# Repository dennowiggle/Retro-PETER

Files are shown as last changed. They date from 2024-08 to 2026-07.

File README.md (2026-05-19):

# Retro-PETER
A Retro computer project => FPGA peripheral board + 3.3V RCBUS slot + CPU board(s) making a custom system.

## Description
Retro-PETER is a family of boards based around the Lattice ECP5 FPGA to create a custom retro computer system.
* [PETER](Hardware/PETER "Peripheral ECP5 Technology and Entertainment Resource board.") base board with FPGA provides the peripheral features. It has on board SRAM memory but no CPU.
    - One 3.3V RCBUS connector provides a CPU slot.
    - One 3.3V RCBUS expansion connector allows connection of an RCBUS backplane for more card slots.
* [ANALYZER](Hardware/Analyzer "Logic Analyzer for RCBUS using PI PICO 2") is a 5V tolerant 72 channel logic analyzer for RCBUS.
* [BALD](Hardware/BALD "Bus Activity LED Display.") is an RCBUS LED card that flickers lights when there is activity. I found this useful for bringup of new CPU's either on an RCBUS CPU card or internal CPU cores.
* [BUTLER](Hardware/BUTLER "Backplane with Universal Translation Logic for Exploring Retro") is a backplane with voltage translation logic to support 2 x 3.3V connectors for 3.3V RCBUS cards and 3 x 5V connectors for 5V RCBUS cards.
* [GOLD](Hardware/GOLD "GPIO On LED Display.") is a simple LED board that connects to 6 GPIO outputs for flashing lights and debug info. I love a binary counter.
* [RANDY](Hardware/RANDY "RCBUS Adapter to Nouveau Design. Yeah!") is a bus adapter from RCBUS to John's Basement [2067-Z8S180](https://github.com/johnwinans/2067-Z8S180/) card.
* [SEWER](Hardware/SEWER "Simple Eval With EZ80F91 on RCBUS") is an eZ80 CPU card.
* [SPIFEE](Hardware/SPIFEE "Sixty-eight thousand Processor Including Flash Engineering Eval") is an RCBUS board with an M68SEC000FU20 CPU that runs in 8-bit mode.
* [ZORO](Hardware/ZORO "Z8S180 On RCBUS Only.") is a Z180 RCBUS CPU card.

**WARNING** : This is a 3.3V system and any connections to PETER, including RCBUS, must NOT exceed 3.3V.

**Disclaimer** This is a hobby project and a vehicle for play. Not intended to be a product or to be optimised for size, cost, function, or meet any standard. All boards are prototypes and should be considered such even if there are new revisions over time.

## Background
John Winans has a video series and boards for an ice40HX4K + Z180 CPU card aka Z80 Nouveau. There is also a companion CP/M video series and project files. This project grew from following along with those video's and projects. Here are some links to follow John's work :
* John's Basement [FPGA](https://www.youtube.com/playlist?list=PL3by7evD3F52On-ws9pcdQuEL-rYbNNFB) YouTube series.
    - Supporting  [2057-ice40HX4K](https://github.com/johnwinans/2057-ICE40HX4K-TQ144-breakout) board.
    - [Code](https://github.com/johnwinans/Verilog-Examples) for Series.
* John's Basement [Z80 Nouveau](https://www.youtube.com/playlist?list=PL3by7evD3F52rUbThUNDYGxNpKFF1HCNT) YouTube series.
    - Supporting [2067-Z8S180](https://github.com/johnwinans/2067-Z8S180/) board.
    - [Code](https://github.com/johnwinans/2067-Z8S180/tree/main/fpga) for Series.
* John's Basement [Z80 Retro](https://www.youtube.com/playlist?list=PL3by7evD3F51Cf9QnsAEdgSQ4cz7HQZX5) YouTube series covering CP/M.
    - [CP/M SW](https://github.com/Z80-Retro/2063-Z80-cpm) to go along with the video series and which supports 2057-ice40HX4K + 2067-Z8S180 aka Z80 Nouveau.
* Johns Z80 Retro! [Discord](https://discord.gg/jf73DRZvh5) channel.

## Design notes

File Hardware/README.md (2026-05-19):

# Retro-PETER Hardware Design Files
A Retro Computer project => FPGA peripheral board + 3.3V RCBUS slot + CPU board(s) making a custom system.

Hardware design files in KiCad 8 format are located here. 

Schematic design PDF drawings can be found in the `output` sub-directory of each board directory.

**Warning** : This is a 3.3V system and any connections to PETER, including RCBUS, must NOT exceed 3.3V.

**Disclaimer** : This is a hobby project and a vehicle for play. Not intended to be a product or to be optimised for size, cost, function, or meet any standard. All boards are prototypes and should be considered such even if there are new revisions over time.

## Description
Retro-PETER is a family of boards based around the Lattice ECP5 FPGA to create a custom retro computer system.
* [PETER](PETER "Peripheral ECP5 Technology and Entertainment Resource board.") base board with FPGA provides the peripheral features. It has on board SRAM memory but no CPU.
    - One 3.3V RCBUS connector provides a CPU slot.
    - One 3.3V RCBUS expansion connector allows connection of an RCBUS backplane for more card slots.
* [ANALYZER](Analyzer "Logic Analyzer for RCBUS using PI PICO 2") is a 5V tolerant 72 channel logic analyzer for RCBUS.
* [BALD](BALD "Bus Activity LED Display.") is an RCBUS LED card that flickers lights when there is activity. I found this useful for bringup of new CPU's either on an RCBUS CPU card or internal CPU cores.
* [BUTLER](BUTLER "Backplane with Universal Translation Logic for Exploring Retro") is a backplane with voltage translation logic to support 2 x 3.3V connectors for 3.3V RCBUS cards and 3 x 5V connectors for 5V RCBUS cards.
* [GOLD](GOLD "GPIO On LED Display.") is a simple LED board that connects to 6 GPIO outputs for flashing lights and debug info. I love a binary counter.
* [RANDY](RANDY "RCBUS Adapter to Nouveau Design. Yeah!") is a bus adapter from RCBUS to John's Basement [2067-Z8S180](https://github.com/johnwinans/2067-Z8S180/) card.
* [SEWER](SEWER "Simple Eval With EZ80F91 on RCBUS") is an eZ80 CPU card.
* [SPIFEE](SPIFEE "Sixty-eight thousand Processor Including Flash Engineering Eval") is an RCBUS board with an M68SEC000FU20 CPU that runs in 8-bit mode.
* [ZORO](ZORO "Z8S180 On RCBUS Only.") is a Z180 RCBUS CPU card.

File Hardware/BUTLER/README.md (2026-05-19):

# BUTLER
Backplane with Universal Translation Logic for Exploring Retro

## Description
BUTLER is an RCBUS backplane board with voltage translation logic. It has 2 connectors for 3.3V cards and 3 connectors for 5V cards.

The buffer direction control signal comes from the [PETER](../PETER) FPGA. The card uses three backplane signals for GND as well as GND planes to try and improve signal integrity.

## Top View
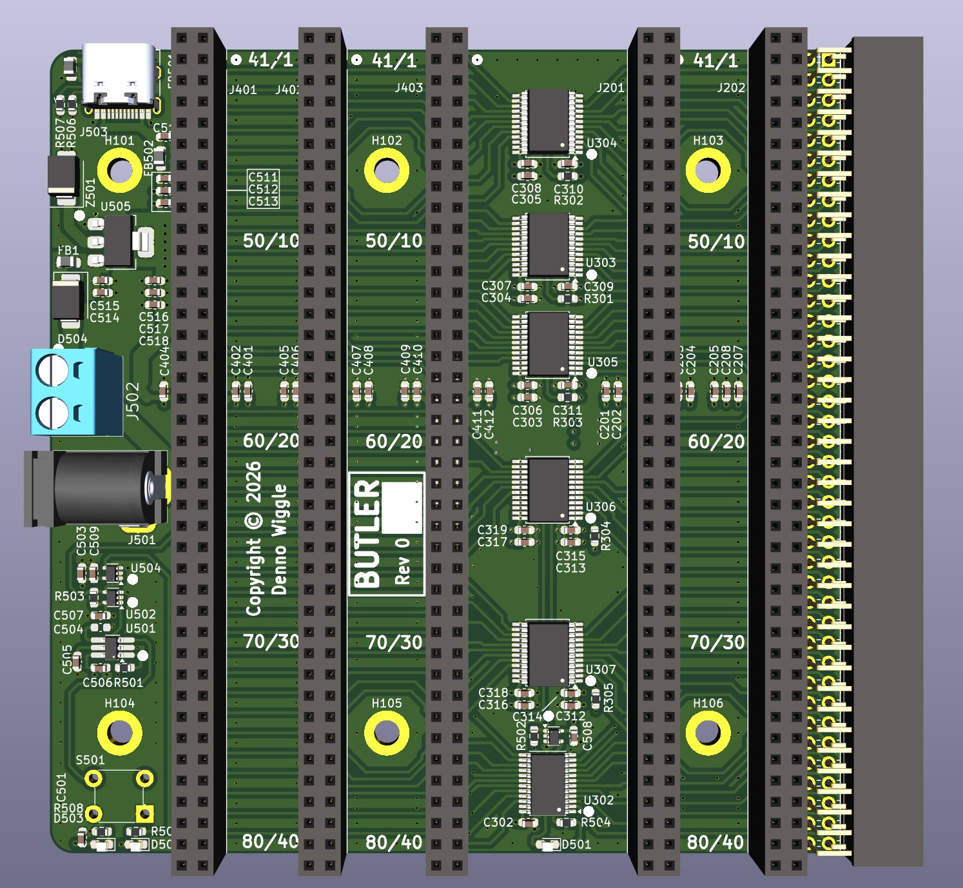
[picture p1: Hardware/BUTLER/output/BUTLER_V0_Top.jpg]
BUTLER Top View Board Image Top View of the BUTLER backplane board.


## Bottom View
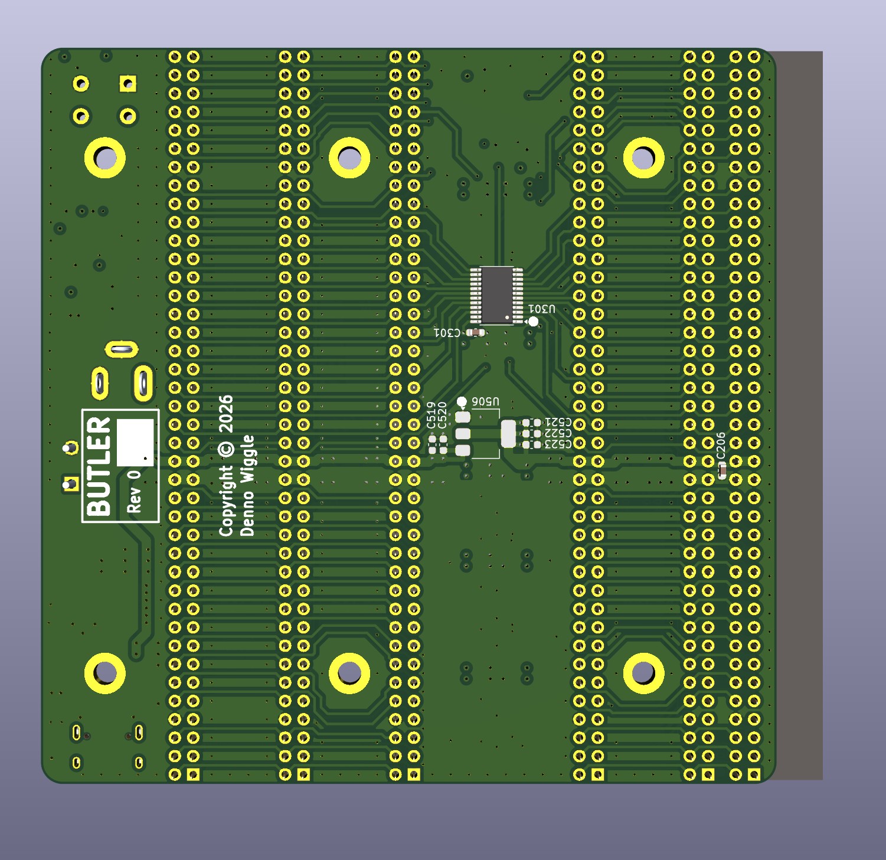
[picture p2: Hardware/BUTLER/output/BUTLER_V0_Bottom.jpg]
BUTLER Bottom View Board Image Bottom View of the BUTLER backplane board.


## BUTLER Board Rev 0.0 Release Notes
1. The [output](output/) directory contains the BOM, netlist, and PDF schematic.

2. Board design used KiCad 9.0

## BUTLER Future Changes.
1. Replace U505 5V LDO with TRACO POWER TSR 1-2450 or equivalent that has a wide input voltage operating range and is a switch mode power supply. This has been tested on the prototype as rework and worked well.

## Notes
Only preliminary testing has taken place.

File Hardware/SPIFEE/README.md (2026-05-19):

# SPIFEE
Sixty-eight thousand Processor Including Flash Engineering Eval

## Description
SPIFEE is an RCBUS board with an M68SEC000FU20 CPU that runs in 8-bit mode. There is no RAM or control signal decoding hosted on the board, that is taken care of on the main [PETER board](../PETER/).

The purpose of the card is to use it to learn 68000 programming.

## Top View
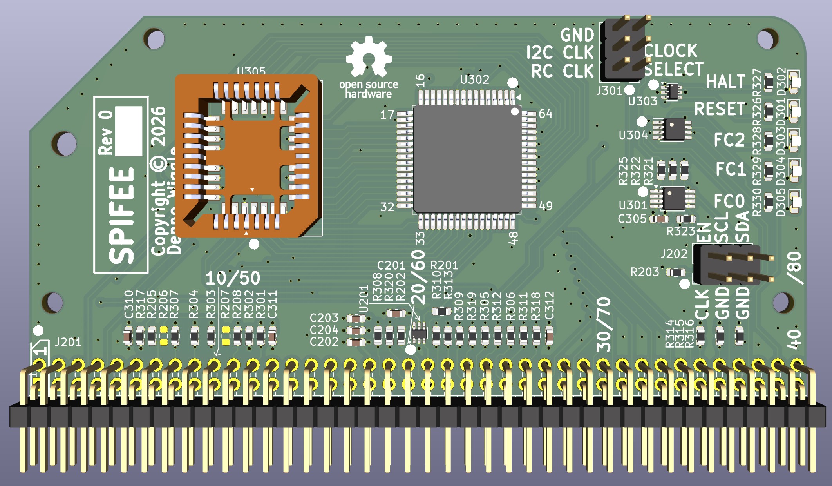
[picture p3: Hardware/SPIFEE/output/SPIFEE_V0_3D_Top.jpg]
SPIFEE Top View Board Image Top View of the SPIFEE M68000 board.


## Bottom View
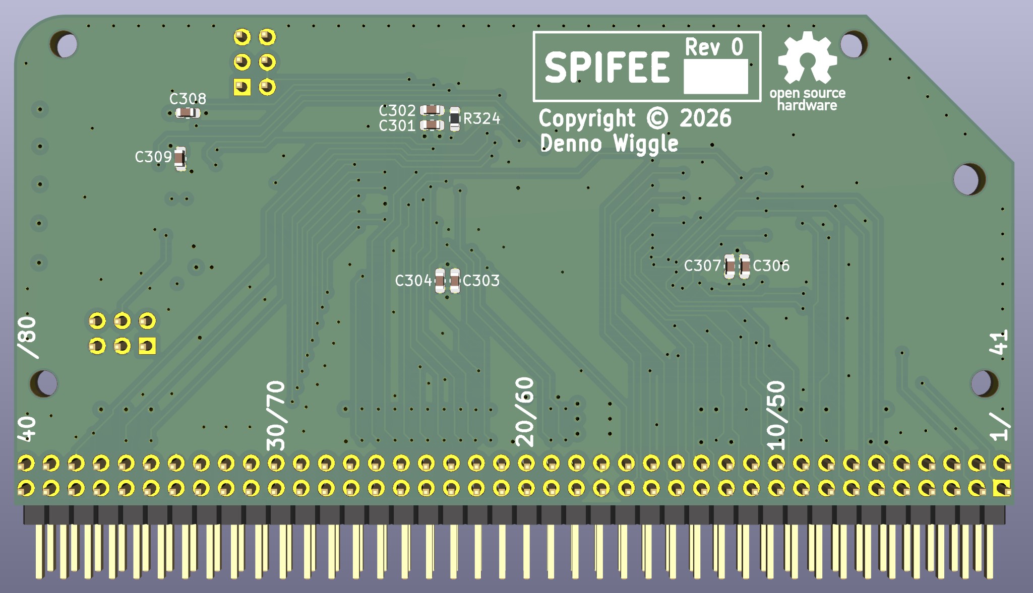
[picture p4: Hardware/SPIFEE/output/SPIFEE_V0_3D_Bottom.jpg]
SPIFEE Bottom View Board Image Bottom View of the SPIFEE M68000 board.


## SPIFEE Board Rev 0.0 Release Notes
1. The [output](output/) directory contains the BOM, netlist, and PDF schematic.

2. Board design used KiCad 10.0

3. Jumper CPU_RESET_N to CPU_HALT_N, RCBUS pin 20 to pin 63.
   * If signals need to be separate then jumper CPU_HALT_N to spare pin on PETER FPGA e.g. spare GPIO pin on PETER GPIO header.
   
4. If using a socket for the FLASH have the assembly house solder the socket, or use a hotplate and hot air.
   * If soldering the FLASH part directly it is possible to program a blank FLASH when soldered onto the board from a ROM image inside the FPGA to start. First need to develop the ROM image to do that.

## Notes
The FLASH has not been tested yet.

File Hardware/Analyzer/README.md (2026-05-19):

# ANALYZER
72 channel logic analyzer for RCBUS.

## Description
ANALYZER is a 72 channel logic analyzer in an RCBUS board form factor with 3 x Pi Pico modules. 

This design is a derivative work of John Winans [S-100 bus logic analyzer](https://github.com/johnwinans/2070-S-100-bus-analyzer) targeted for RCBUS instead of S-100 bus for use on the PETER project.

Both projects use the Dr Gusman [LogicAnalyzer software and firmware](https://github.com/gusmanb/logicanalyzer).

## Top View
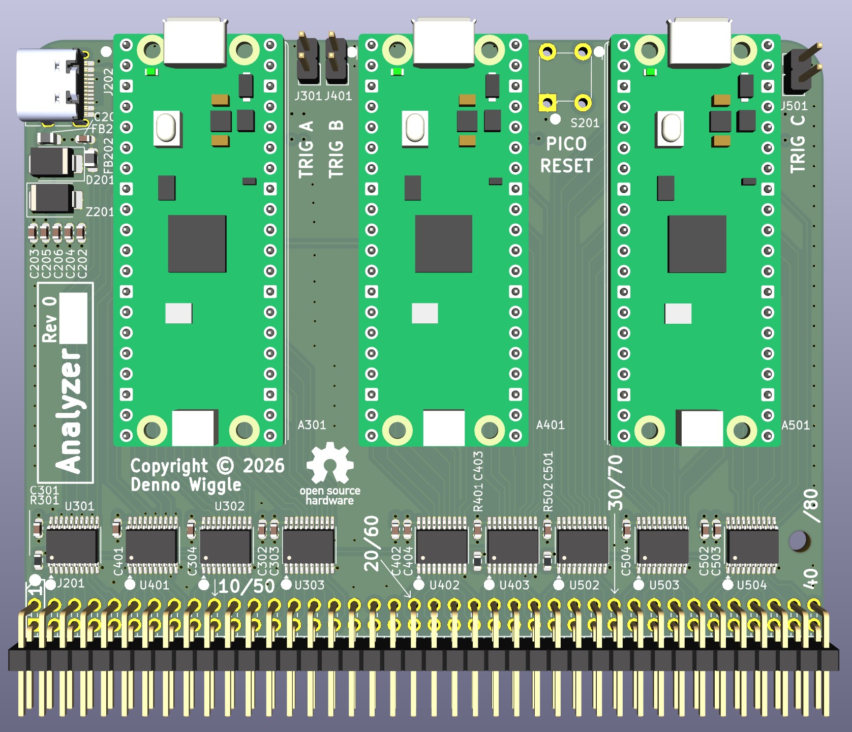
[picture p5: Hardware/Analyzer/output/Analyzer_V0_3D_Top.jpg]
ANALYZER Top View Board Image Top View of the RCBUS LogicAnalyzer board.


## Bottom View
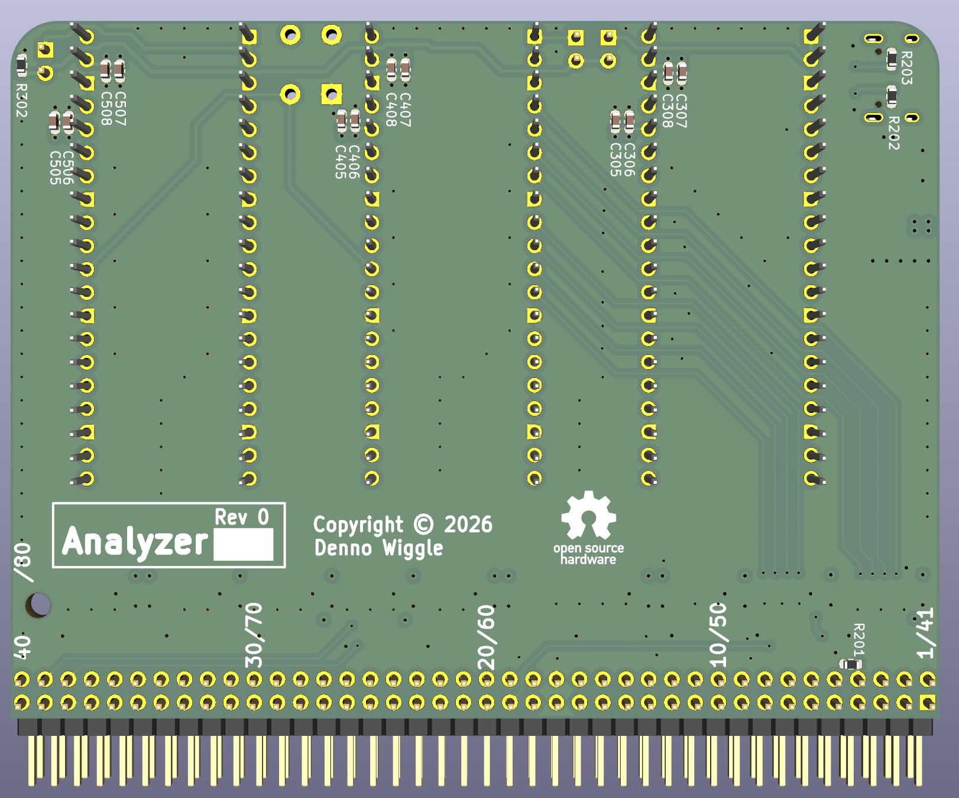
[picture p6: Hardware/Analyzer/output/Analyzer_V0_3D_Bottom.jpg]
ANALYZER Bottom View Board Image Bottom View of the RCBUS LogicAnalyzer board.


## ANALYZER Board Rev 0.0 Release Notes

1. The 'output' directory contains the BOM, netlist, and PDF schematic.

2. Board design used KiCad 10.0

3. Use sockets to mount the PICO's so that they are elevated above the board for anyone wanting to try WiFi.

## Notes for future
1. Consider using 3 x individual Pico 10K pull-down resistors for
  - TRIG_CHA, TRIG_CHB, TRIG_CHC instead of R302 2.2K on TRIG.

2. Consider replacing D201 with 3 schottky diodes to VSYS_A, VSYS_B, VSYS_B.
  - Provides option for manually sequencing power via each Pico USB connector.
  - Useful for getting same tty device name in Linux on each power on.

## Analyzer Board Pi Pico Channel Mapping to Signal and Pin Names
The [gusmanb software](https://github.com/gusmanb/logicanalyzer) only has the choice of 16 pins for trigger.

The table below has the middle PICO as the master. With the RCBUS backplane you can jumper the desired trigger signal to one of the unused pins. e.g. custom pin 41, analyzer channel 1.

 | Pico A       | Single A | Multi A | PETER Signal | RCBUS Pin | RCBUS Name  | 
 | ------------ | -------- | ------- | ------------ | --------- | ----------- |
 | GPIO_CHA_P2  | 1        | 25      | A15          | 1         | A15         | 
 | GPIO_CHA_P3  | 2        | 26      | A14          | 2         | A14         | 
 | GPIO_CHA_P4  | 3        | 27      | A13          | 3         | A13         | 
 | GPIO_CHA_P5  | 4        | 28      | DREQ0_N      | 45        | custom      | 
 | GPIO_CHA_P6  | 5        | 29      | A11          | 5         | A11         | 
 | GPIO_CHA_P7  | 6        | 30      | A10          | 6         | A10         | 
 | GPIO_CHA_P8  | 7        | 31      | A5           | 11        | A5          | 
 | GPIO_CHA_P9  | 8        | 32      | A21          | 51        | A21         | 
 | GPIO_CHA_P10 | 9        | 33      | A6           | 10        | A6          | 
 | GPIO_CHA_P11 | 10       | 34      | A22          | 50        | A22         | 
 | GPIO_CHA_P12 | 11       | 35      | A7           | 9         | A7          | 
 | GPIO_CHA_P13 | 12       | 36      | A23          | 49        | A23         | 
 | GPIO_CHA_P14 | 13       | 37      | A9           | 7         | A9          | 
 | GPIO_CHA_P15 | 14       | 38      | A8           | 8         | A8          | 
 | GPIO_CHA_P16 | 15       | 39      | A2           | 14        | A2          | 
 | GPIO_CHA_P17 | 16       | 40      | A17          | 55        | A17         | 
 | GPIO_CHA_P18 | 17       | 41      | A1           | 15        | A1          | 
 | GPIO_CHA_P19 | 18       | 42      | A16          | 56        | A16         | 
 | GPIO_CHA_P20 | 19       | 43      | A0           | 16        | A0          | 
 | GPIO_CHA_P21 | 20       | 44      | A18          | 54        | A18         | 
 | GPIO_CHA_P22 | 21       | 45      | A3           | 13        | A3          | 
 | GPIO_CHA_A0  | 22       | 46      | A19          | 53        | A19         | 
 | GPIO_CHA_A1  | 23       | 47      | A4           | 12        | A4          | 
 | GPIO_CHA_A2  | 24       | 48      | A20          | 52        | A20         | 
 
 | Pico B       | Single B | Multi B | PETER Signal | RCBUS Pin | RCBUS Name  | 
 | ------------ | -------- | ------- | ------------ | --------- | ----------- |
 | GPIO_CHB_P2  | 1        | 1       | MEM_OE_N     | 41        | custom      | 
 | GPIO_CHB_P3  | 2        | 2       | MEM_CE_N     | 42        | custom      | 
 | GPIO_CHB_P4  | 3        | 3       | MEM_WE_N     | 43        | custom      | 
 | GPIO_CHB_P5  | 4        | 4       | A12          | 4         | A12         | 
 | GPIO_CHB_P6  | 5        | 5       | TEND0_N      | 46        | custom      | 
 | GPIO_CHB_P7  | 6        | 6       | DREQ1_N      | 47        | custom      | 
 | GPIO_CHB_P8  | 7        | 7       | TEND1_N      | 48        | custom      | 
 | GPIO_CHB_P9  | 8        | 8       | M1_N         | 19        | /M1         | 
 | GPIO_CHB_P10 | 9        | 9       | BUSACK_N     | 62        | /BUSAK      | 
 | GPIO_CHB_P11 | 10       | 10      | INT0_N       | 22        | /INT        | 
 | GPIO_CHB_P12 | 11       | 11      | CLK_SRC      | 61        | CLK2        | 
 | GPIO_CHB_P13 | 12       | 12      | CLK_PHI      | 21        | CLK         | 
 | GPIO_CHB_P14 | 13       | 13      | PAGE         | 60        | PAGE_RESET2 | 
 | GPIO_CHB_P15 | 14       | 14      | RESET_N      | 20        | /RESET      | 
 | GPIO_CHB_P16 | 15       | 15      | WAIT_N       | 65        | /WAIT       | 
 | GPIO_CHB_P17 | 16       | 16      | RD_N         | 25        | /RD         | 
 | GPIO_CHB_P18 | 17       | 17      | BUSREQ_N     | 64        | /BUSRQ      | 
 | GPIO_CHB_P19 | 18       | 18      | WR_N         | 24        | /WR         | 
 | GPIO_CHB_P20 | 19       | 19      | HALT_N       | 63        | /HALT       | 
 | GPIO_CHB_P21 | 20       | 20      | MREQ_N       | 23        | /MREQ       | 
 | GPIO_CHB_P22 | 21       | 21      | IORQ_N       | 26        | /IORQ       | 
 | GPIO_CHB_A0  | 22       | 22      | NMI_N        | 66        | /NMI        | 
 | GPIO_CHB_A1  | 23       | 23      | I2C_SCL      | 78        | USER6       | 
 | GPIO_CHB_A2  | 24       | 24      | I2C_SDA      | 79        | USER7       | 
 
 | Pico C       | Single C | Multi C | PETER Signal | RCBUS Pin | RCBUS Name  | 
 | ------------ | -------- | ------- | ------------ | --------- | ----------- |
 | GPIO_CHC_P2  | 1        | 49      | D0           | 27        | D0          | 
 | GPIO_CHC_P3  | 2        | 50      | D8           | 67        | D8          | 
 | GPIO_CHC_P4  | 3        | 51      | D1           | 28        | D1          | 
 | GPIO_CHC_P5  | 4        | 52      | D9           | 68        | D9          | 
 | GPIO_CHC_P6  | 5        | 53      | D2           | 29        | D2          | 
 | GPIO_CHC_P7  | 6        | 54      | D10          | 69        | D10         | 
 | GPIO_CHC_P8  | 7        | 55      | D3           | 30        | D3          | 
 | GPIO_CHC_P9  | 8        | 56      | D11          | 70        | D11         | 
 | GPIO_CHC_P10 | 9        | 57      | D14          | 73        | D14         | 
 | GPIO_CHC_P11 | 10       | 58      | D6           | 33        | D6          | 
 | GPIO_CHC_P12 | 11       | 59      | D13          | 72        | D13         | 
 | GPIO_CHC_P13 | 12       | 60      | D5           | 32        | D5          | 
 | GPIO_CHC_P14 | 13       | 61      | D12          | 71        | D12         | 
 | GPIO_CHC_P15 | 14       | 62      | D4           | 31        | D4          | 
 | GPIO_CHC_P16 | 15       | 63      | UART1_RX     | 36        | RX          | 
 | GPIO_CHC_P17 | 16       | 64      | UART2_TX     | 75        | TX2         | 
 | GPIO_CHC_P18 | 17       | 65      | UART1_TX     | 35        | TX          | 
 | GPIO_CHC_P19 | 18       | 66      | D15          | 74        | D15         | 
 | GPIO_CHC_P20 | 19       | 67      | D7           | 34        | D7          | 
 | GPIO_CHC_P21 | 20       | 68      | UART2_RX     | 76        | RX2         | 
 | GPIO_CHC_P22 | 21       | 69      | DATA_DIR     | 37        | USER1       | 
 | GPIO_CHC_A0  | 22       | 70      | USER2        | 38        | USER2       | 
 | GPIO_CHC_A1  | 23       | 71      | USER3        | 39        | USER3       | 
 | GPIO_CHC_A2  | 24       | 72      | USER4        | 40        | USER4       | 

 | Unconnected  |          |         |              | RCBUS Pin | RCBUS Name  | 
 | ------------ | -------- | ------- | ------------ | --------- | ----------- |
 |              |          |         |              | 57        | GND         | 
 |              |          |         |              | 58        | 5V          | 
 |              |          |         |              | 59        | /RFSH       | 
 |              |          |         |              | 77        | USER5       | 
 |              |          |         |              | 80        | USER8_IEI   |

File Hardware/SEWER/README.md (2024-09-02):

# SEWER
Simple Eval With EZ80F91 on RCBUS

## Description
SEWER is an RCBUS board with an ez80F91 CPU. There is no RAM or ROM memory hosted on the board.

## Top View
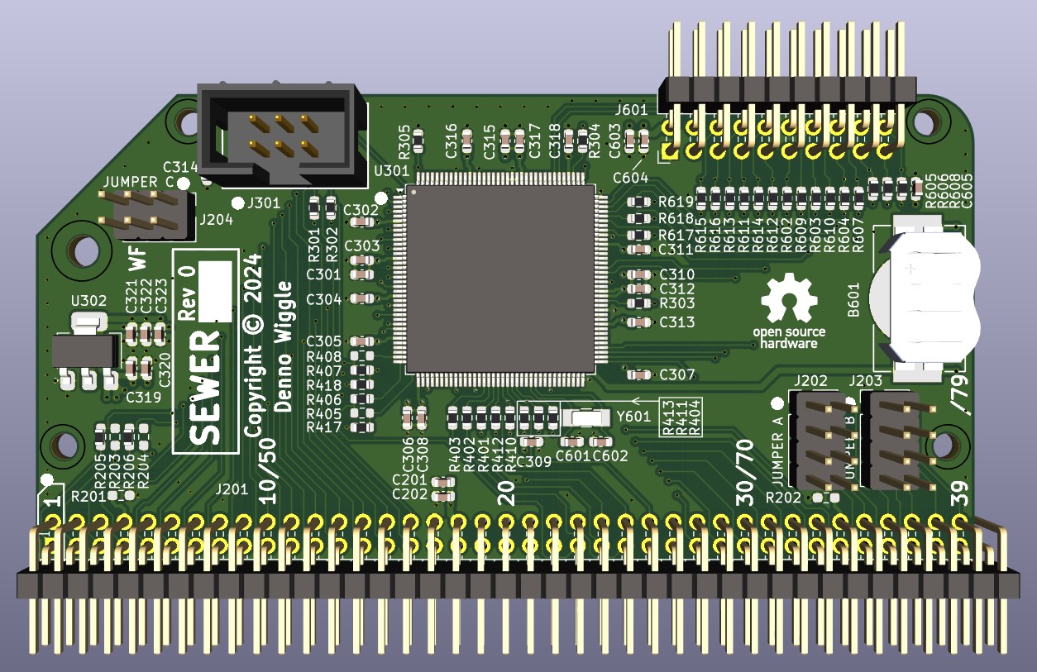
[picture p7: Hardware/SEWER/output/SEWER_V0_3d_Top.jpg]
SEWER Top View Board Image Top View of the Simple Eval With EZ80F91 on RCBUS board.


## Bottom View
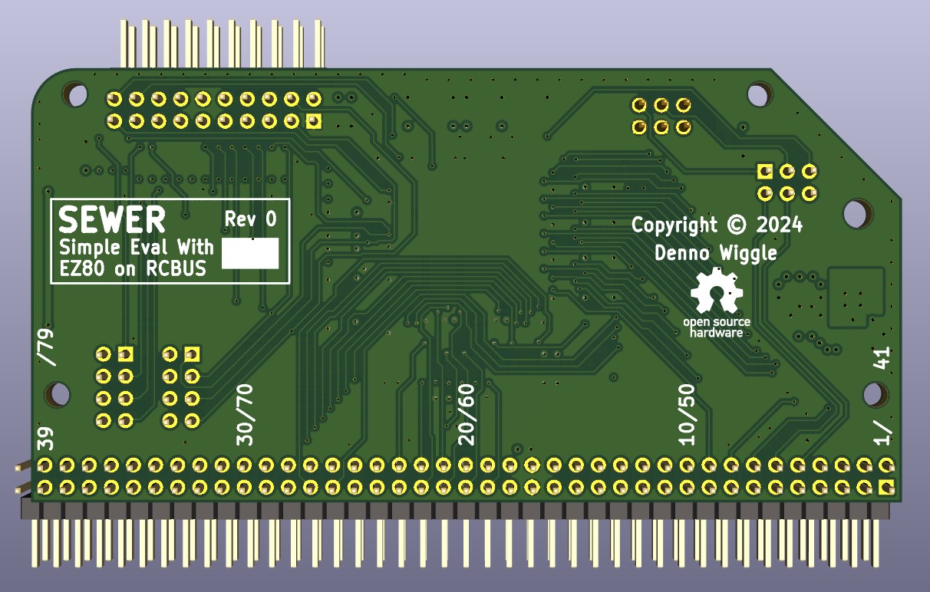
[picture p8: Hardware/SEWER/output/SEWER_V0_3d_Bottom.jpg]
ZORO Bottom View Board Image Bottom View of the Simple Eval With EZ80F91 on RCBUS board.


## SEWER Board Rev 0.0 Release Notes

1. The 'output' directory contains the BOM, netlist, and PDF schematic.

2. Board design used KiCad 8.0.4.

3. This board was designed for evaluation purposes. It is not a final design.

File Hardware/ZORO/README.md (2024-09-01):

# ZORO
Z8S180 On RCBUS Only.

## Description
ZORO is an RCBUS board with a Z180 CPU. There is no RAM or ROM memory hosted on the board.

## Top View
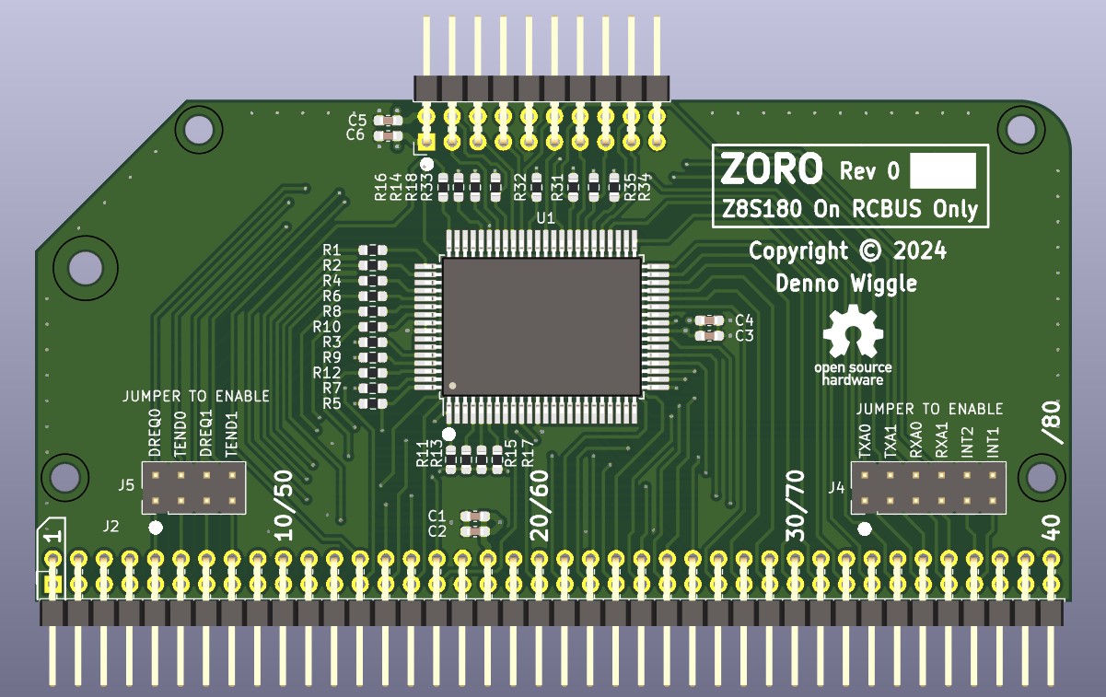
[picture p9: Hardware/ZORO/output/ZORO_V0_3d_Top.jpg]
ZORO Top View Board Image Top View of the Z8S180 On RCBUS Only board.


## Bottom View
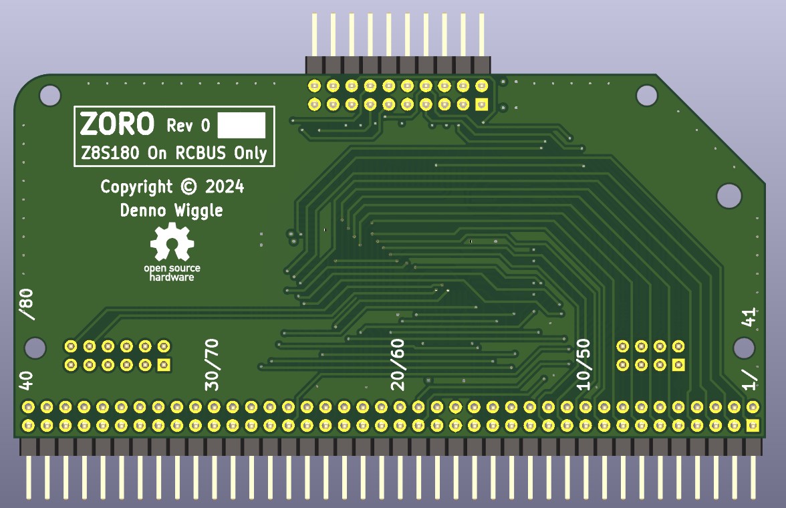
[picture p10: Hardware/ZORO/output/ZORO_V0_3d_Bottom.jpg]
ZORO Bottom View Board Image Bottom View of the Z8S180 On RCBUS Only board.


## ZORO Board Rev 0.0 Release Notes

1. The 'output' directory contains the BOM, netlist, and PDF schematic.

2. Board design used KiCad 8.0.4.

3. Change J2 to Adam Tech part number PH2RA-80-UA to reduce insertion force.

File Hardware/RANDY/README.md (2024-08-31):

# RANDY
RCBUS Adapter to Nouveau Design. Yeah!

## Description
This project is an adapter board to interface the [2067-Z8S180 board](https://github.com/johnwinans/2067-Z8S180) from John Winan's Z80 Nouveau Project to an RCBUS backplane board connector. 
* If a right-angle RCBUS socket is installed on the top side, the board will plug into an RCBUS expansion port.
* If a right-angle RCBUS plug is installed on the bottom side, the board will plug into an RCBUS card slot.

## Top View
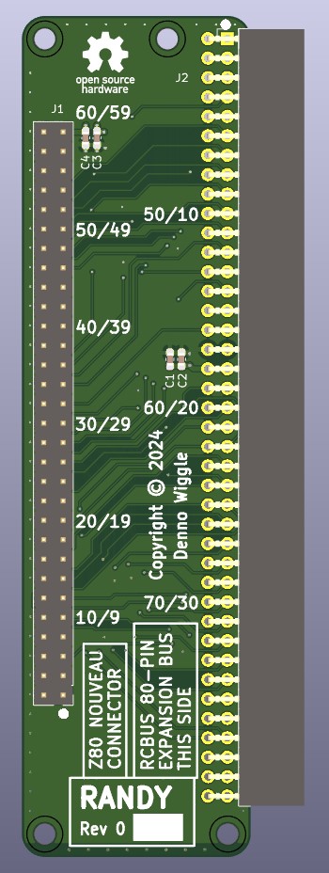
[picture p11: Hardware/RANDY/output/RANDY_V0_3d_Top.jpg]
RANDY Top View Board Image Top View of the RCBUS Adapter to Nouveau Design - Yeah! board.


## Bottom View
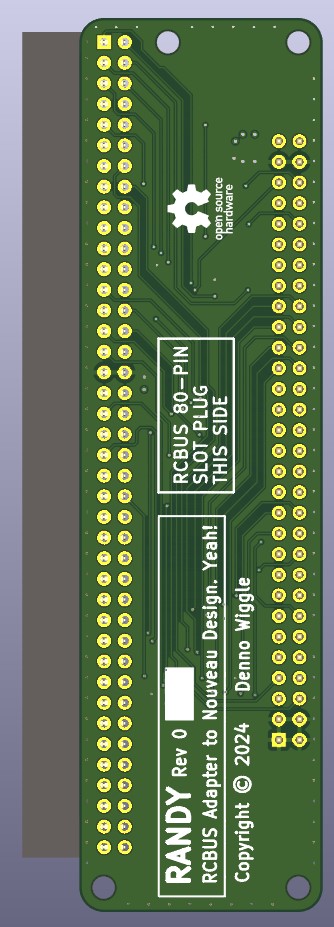
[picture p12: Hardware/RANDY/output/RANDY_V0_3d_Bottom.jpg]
RANDY Bottom View Board Image Bottom View of the RCBUS Adapter to Nouveau Design - Yeah! board.


## RANDY Board Rev 0.0 Release Notes

1. The 'output' directory contains the BOM, netlist, and PDF schematic.

2. Board design used KiCad 8.0.4.

3. J2 changed to Samtec SSW-140-02-F-D-RA.

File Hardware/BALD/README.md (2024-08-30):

# BALD
Bus Activity LED Display.

## Description
BALD is an RCBUS board with LED's to show bus activity.

## Top View
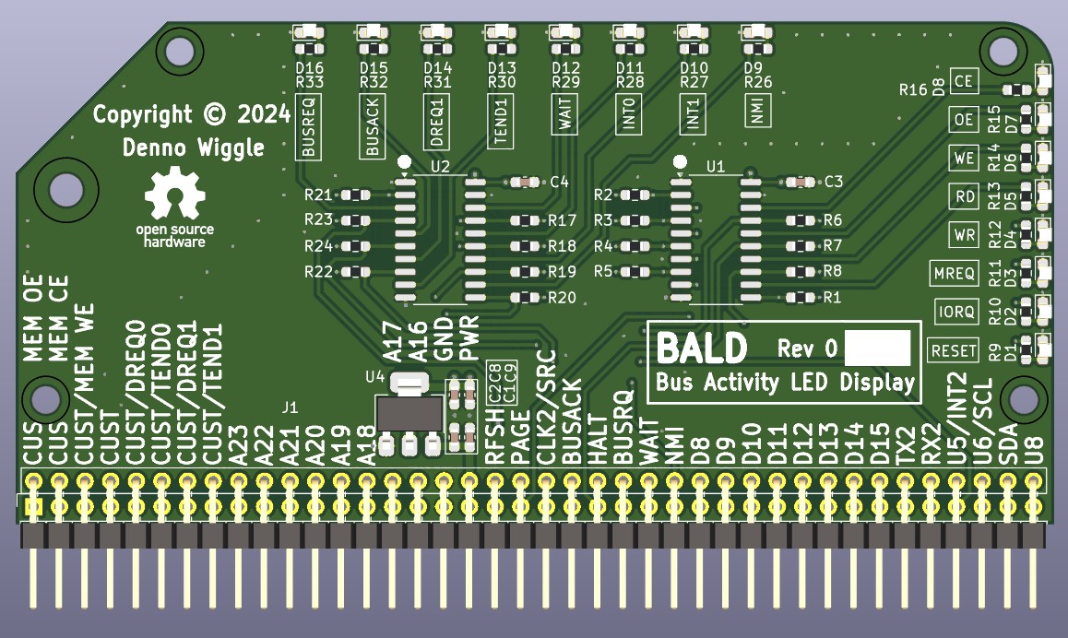
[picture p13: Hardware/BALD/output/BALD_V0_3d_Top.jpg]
BALD Top View Board Image Top View of the Bus Activity LED Display board.


## Bottom View
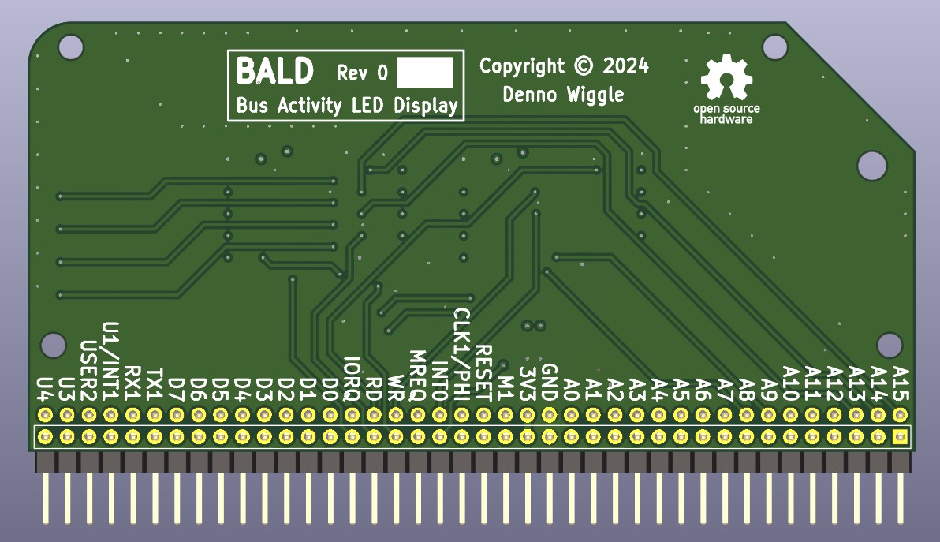
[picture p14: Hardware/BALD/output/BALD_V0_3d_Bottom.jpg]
BALD Bottom View Board Image Bottom View of the Bus Activity LED Display board.


## BALD Board Rev 0.0 Release Notes

1. The 'output' directory contains the BOM, netlist, and PDF schematic.

2. Board design used KiCad 8.0.4.

3. J1 was changed to Adam Tech part number PH2RA-80-UA to reduce insertion force.

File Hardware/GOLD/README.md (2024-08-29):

# GOLD
GPIO On LED Display

## Description
GOLD is a small breakout board that connects to the GPIO connector on PETER to display signal status on 6 LED's.

## Top View
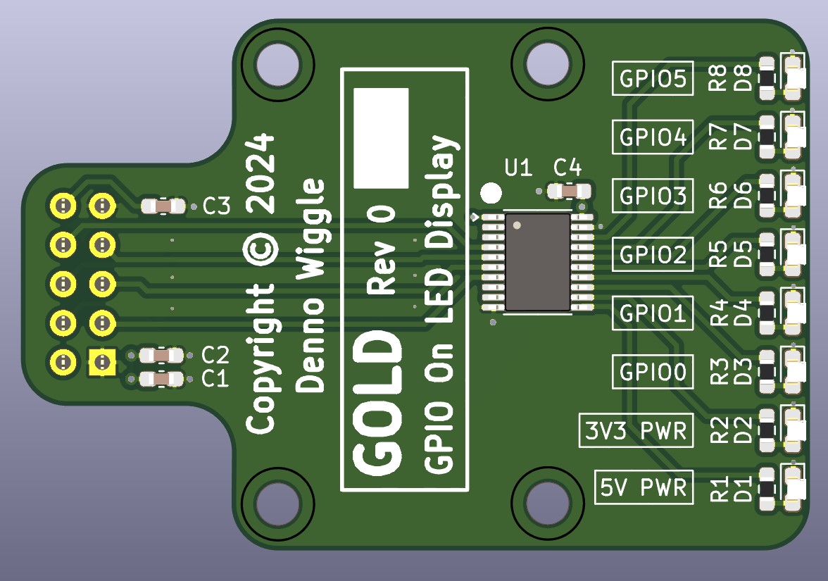
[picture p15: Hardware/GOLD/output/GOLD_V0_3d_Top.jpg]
GOLD Top View Board Image Top View of the GPIO On LED Display board.


## Bottom View
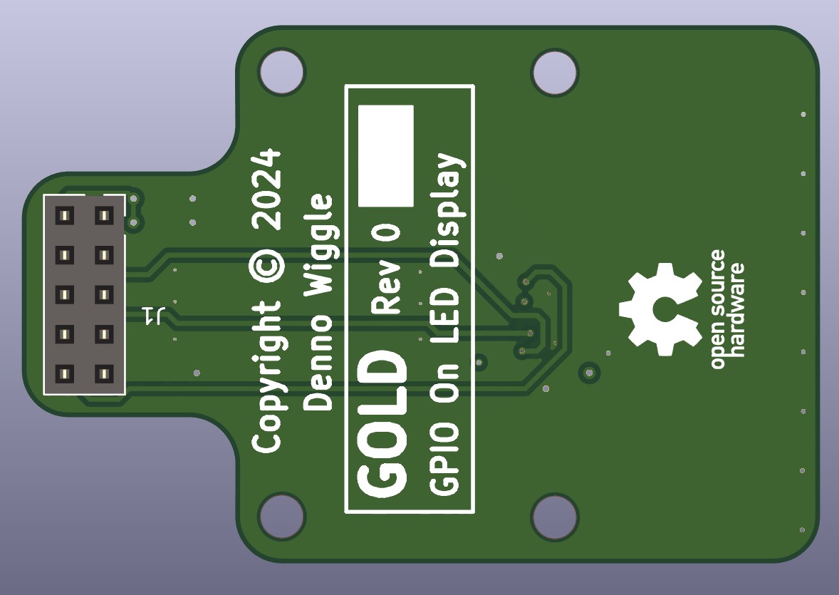
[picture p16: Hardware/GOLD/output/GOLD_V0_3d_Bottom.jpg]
GOLD Bottom View Board Image Bottom View of the GPIO On LED Display board.


## GOLD Board Rev 0.0 Release Notes

1. The 'output' directory contains the BOM, netlist, and PDF schematic.

2. Board design used KiCad 8.0.4.

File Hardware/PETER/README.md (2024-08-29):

# PETER
Peripheral ECP5 Technology and Entertainment Resource

## Description
PETER is an FPGA board based around a Lattice ECP5 FPGA chip. It provides peripheral features for a plug in 3.3V RCBUS CPU card. 

The PETER board provides video, audio, I2C, SPI, SNES controller, 2x USB UART, and PS2 keyboard and mouse connection to a 3.3V RCBUS card slot and expansion connector. 

In addition there is an ESP32-S3 WiFi module for programming the FPGA and system bootloader(s), Zilog ZDI, WiFi console and additonal features. There are on-board connectors for provision of a W5500 Wizmon Ethernet module and DS3132 Real Time Clock + AT24C32 EEPROM module.

**Warning** : This is a 3.3V system and any connections to PETER, including RCBUS, must NOT exceed 3.3V.

**Disclaimer** : This is a hobby project and a vehicle for play. Not intended to be a product or to be optimised for size, cost, function, or meet any standard. All boards are prototypes and should be considered such even if there are new revisions over time.

## Top View
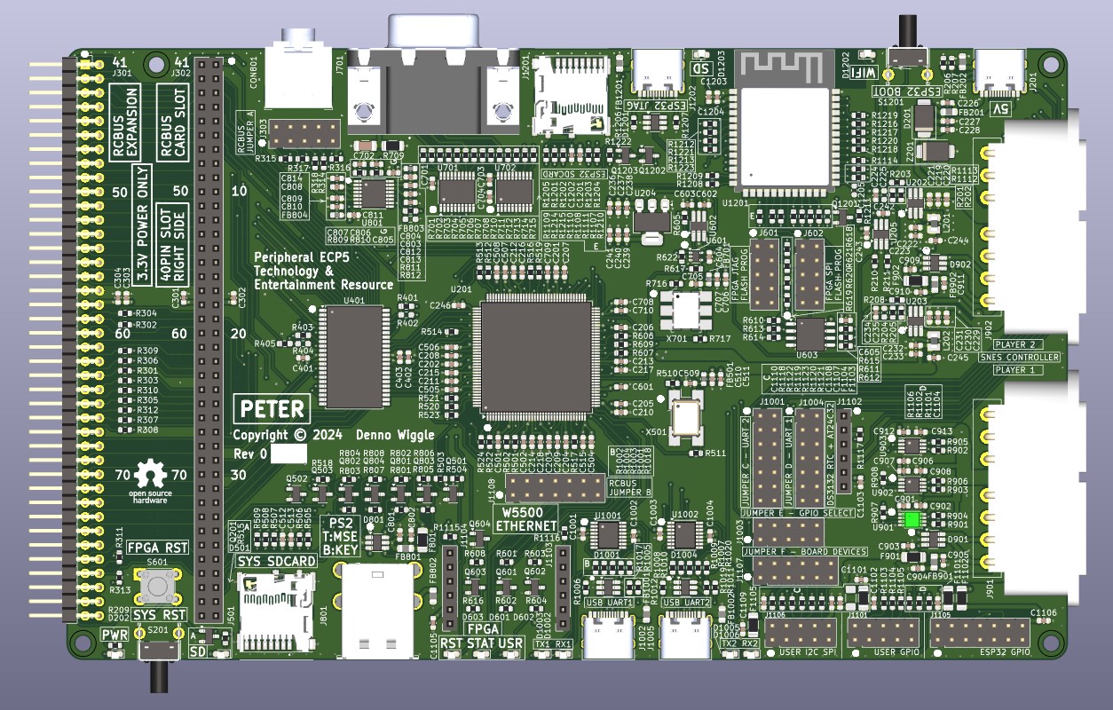
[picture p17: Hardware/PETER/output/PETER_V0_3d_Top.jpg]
PETER Top View Board Image Top View of the Peripheral ECP5 Technology and Entertainment Resource board.


## Front View
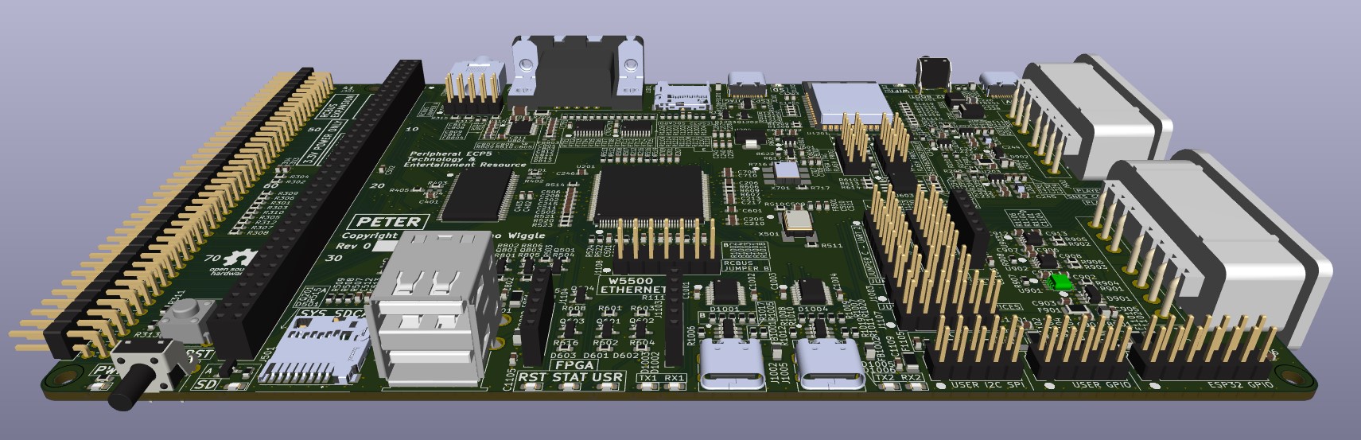
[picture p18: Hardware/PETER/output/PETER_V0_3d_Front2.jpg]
PETER Front View Board Image Top View of the Peripheral ECP5 Technology and Entertainment Resource board.


## Rear View
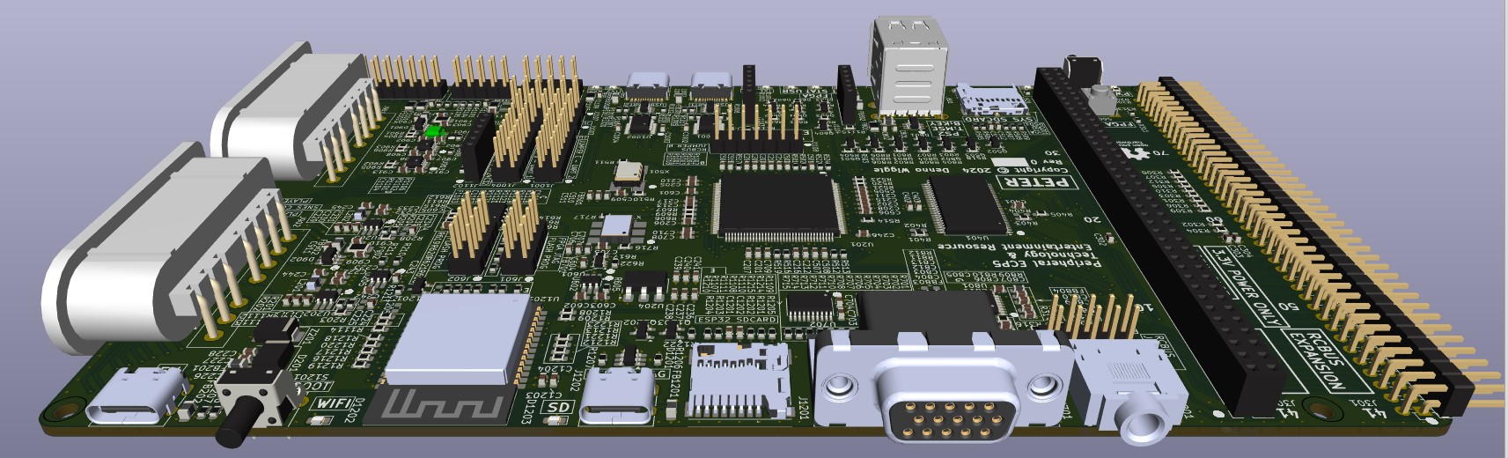
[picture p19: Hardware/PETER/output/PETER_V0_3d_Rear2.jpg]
PETER Rear View Board Image Top View of the Peripheral ECP5 Technology and Entertainment Resource board.


## Side View
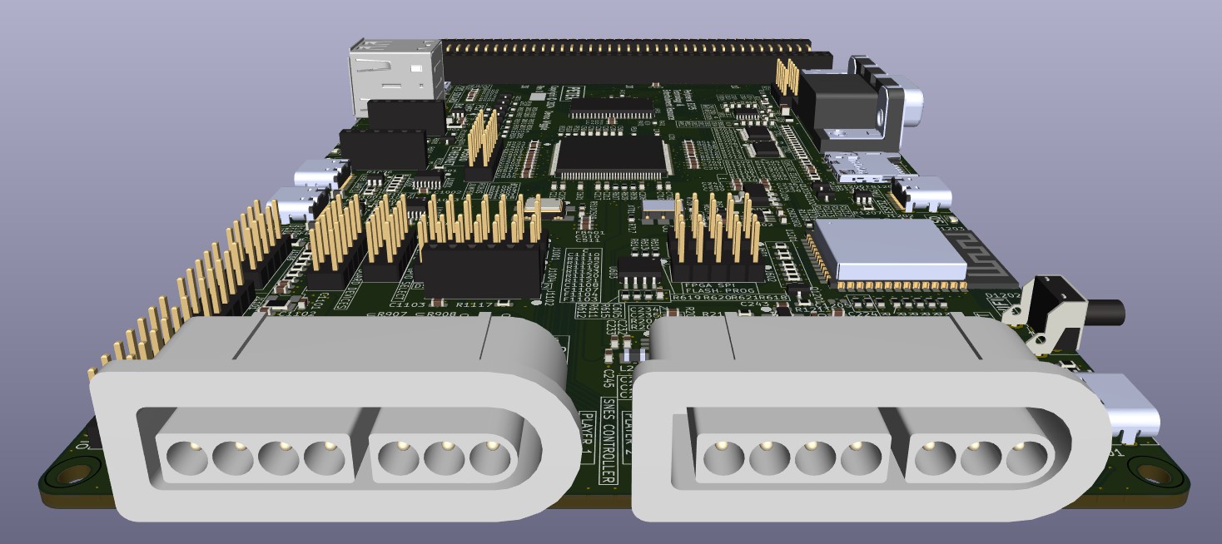
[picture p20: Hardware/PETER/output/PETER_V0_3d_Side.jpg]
PETER Side View Board Image Top View of the Peripheral ECP5 Technology and Entertainment Resource board.


## Board Bring-up Status
   - Most of the board has been tested and status is okay.
   - Audio RTL on the FPGA has yet to be implmented so the audio port is not tested.
   - The ESP32 SD card slot has not been tested.
   - RCBUS compatibility is 3.3V and has not been tested with any RCBUS supported products other than the boards here.

## Programming
* To program the FPGA FLASH an FT232H USB module can be used.
   1. Method (1) uses the open source `ecpprog` tool and JTAG. 
       - Pin connections are as follows:

      | Signal        |  FT232H Module Pin  | PETER Location |
      | ------------- | ------------------- | ---------------- |
      | TDI           | AD1 | J601.2 |
      | TMS           | AD3 | J601.4 |
      | TCK           | AD0 | J601.8 |
      | TDO           | AD2 | J601.10 |
      | GND      | Module Specific | J503.1 or 3,5,7,9 |

   2. Method (2) uses an open source SPI programmer SW tool. 
       - Pin connections are as follows:

      | Signal        |  FT232H Module Pin  | PETER Location |
      | ------------- | ------------------- | ---------------- |
      | SPI_CLK       | AD0 | J602.8 |
      | SPI_MOSI      | AD1 | J602.2 |
      | SPI_MISO      | AD2 | J602.10 |
      | SPI_CS_N      | AD3 | J602.4 |
      | CRESET/INIT_N | AD4 | J602.6 |
      | DONE          | AD5 | J602.5 |
      | GND      | Module Specific | J602.1, or 3,7,9 |

   - Connector pin layout has been chosen so that the same programming cable supports both SPI and JTAG.

* The on-board ESP32 module is programmed using the J1202 USB connector in JTAG mode. 
   - Alternatively it can be programmed over ESP32 UART0 on pins J1105.11 and J1105.12. 
   - When using UART switch S1201 provides the 'boot' function to put the ESP32 into programming mode. 
   - USB JTAG does not require the boot switch. 
   - Both methods require use of the ESP32 programming tool found in Arduino, Platform IO, or Espressif SW tools.

## PETER Board Rev 0.0 Release Notes

1. The 'output' directory contains the BOM, netlist, and PDF schematic.

2. Board design used KiCad 8.0.4.

3. There are only four mounting holes. If the RCBUS card slot is used the board should be supported from underneath when plugging in the card to prevent the PCB from bending. Adhesive rubber feet may be a better option than using the mounting holes.

4. Silkscreen error
   - J1106 silkscreen should show `GPIO`. Instead silkscreen shows `USER I2C SPI`.
   - J1101 silkscreen should show `USER I2C SPI`. Instead silkscreen shows `GPIO`.

5. USB UART TX/RX LED's are rather weak compared to the other LED's on the board. The resistor in series with each LED can be changed to a lower value (eg 270ohms).
   - Resistor locations are R1001, R1002, R1007, R1008.
   - Note : in general the LED's are low light by design. This is intentional.

6. R401 should be 10K instead of 0 ohms if R401 is populated.

7. J301 RCBUS expansion connector part number was changed to PH2RA-80-UA which has a gold flash plating providing less resistance during plug/unplug. 

8. J302 RCBUS card slot socket was purchased from Ebay and had gold plating. 

9. Reset signal FPGA_CRESET_N high level = 2.77V due to being open drain and Q604 having 20K biasing resistance. This meets the 2V Vih requirement of the FPGA pin. If a higher level is desired change R617 to 1K.

10. The SRAM memory MEM_WE_N, MEM_OE_N, and MEM_CE_N signals are routed through the FPGA and as a consequence there is about a ~10ns delay from the CPU_WR_N, CPU_RD_N, CPU_MREQ_N signals to their SRAM equivalent signals. 
    - If direct connection is needed for timing needs then the RCBUS board can be designed to directly connect to the SRAM memory signals. Alternatively the RCBUS expansion connector provides pins where jumper wires can be attached.

11. The [FTDI DT_PROG](https://www.ftdichip.com/Support/Documents/AppNotes/AN_124_User_Guide_For_FT_PROG.pdf) tool can be used to program U1001 & U1002 FT230X pin CBUS3 for VBUS_SENSE function. 
    - This allows the FT230X IC to detect removal of the USB cable and resets the USB connection without a power cycle of the board.

12. U202 and U203 TPS62A02PDDCR used for the 3.3V and 1.1V power supplies is a 2A part. The system is low power and the 1A TPS62A01PDDCR should be sufficient and would provide a lower overcurrent trip point providing enhanced overcurrent protection. The 1A part is footprint and circuit compatible.

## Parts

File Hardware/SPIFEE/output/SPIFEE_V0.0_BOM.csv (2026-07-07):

Reference | Value | Qty | DNP | Digikey | LCSC Part # | MPN | Manufacturer | Description
C201,C202,C301,C304,C305,C307,C308,C309,C310,C311,C312 | 100nF | 11 |  | 311-1344-1-ND | C14663 | CC0603KRX7R9BB104 | YAGEO | CAP CER 0.1UF 50V X7R 0603
R301,R302,R303,R304,R305,R306,R307,R308,R309,R310,R311,R312,R313,R314,R315,R316,R317,R318,R319,R320,R321,R322,R323 | 10K | 23 |  | 311-10.0KHRCT-ND | C98220 | RC0603FR-0710KL | Yaego | RES 10K OHM 1% 1/10W 0603
R206,R207 | 0R | 2 | DNP | 311-0.0GRCT-ND | C95177 | RC0603JR-070RL | Yaego | RES 0 OHM 5% 1/10W 0603
R203,R326,R327,R328,R329,R330 | 1K00 | 6 |  | 311-1.00KHRCT-ND | C22548 | RC0603FR-071KL | Yaego | RES 1K OHM 1% 1/10W 0603
R202,R205,R208 | 0R | 3 |  | 311-0.0GRCT-ND | C95177 | RC0603JR-070RL | Yaego | RES 0 OHM 5% 1/10W 0603
R201,R324,R325 | 33R | 3 |  | 13-RC0603FR-0733RLCT-ND | C108661 | RC0603FR-0733RL | Yaego | RES 33 OHM 1% 1/10W 0603
C203,C204,C302,C303,C306 | 4.7uF | 5 |  | 1276-1784-1-ND | C19666 | CL10A475KO8NNNC | Yaego | CAP CER 4.7UF 16V X5R 0603
U303 | 74LVC2G07 | 1 |  | 1727-4121-1-ND | C24478 | 74LVC2G07GW,125 | Nexperia | IC BUFF NON-INVERT 5.5V 6-TSSOP
U201 | 74LVC2G34 | 1 |  | 1727-4219-1-ND |  | 74LVC2G34GW,125 | Nexperia | IC BUFF NON-INVERT 5.5V 6-TSSOP
U302 | MC68SEC000FU | 1 |  |  |  | MC68SEC000FU20 | Motorola | 16/32-bit microprocessor, 16-bit external data bus, 23-bit external address bus (effectively 24-bit), QFP64
U305 | SST39LF040-55 | 1 |  | SST39LF040-55-4C-NHE-ND | C645927 | SST39LF040-55-4C-NHE | Microchip | IC FLASH 4MBIT 512KX8 PARALLEL 3V3 55ns PLCC32
D301,D302,D303,D304,D305 | LED_LTST-S270KGKT | 5 |  | 160-1478-1-ND | C125113 | LTST-S270KGKT | Lite-On Inc. | LED 571NM GREEN CLEAR CHIP 0603 R/A
U304 | 74LVC3G06 | 1 |  | 31-74LVC3G06SS8-7CT-ND | C6089410 | 74LVC3G06SS8-7 | Diodes Incorporated | IC INVERTER 3CH 3-INP 8SSOP
U301 | DS1086LU+ | 1 |  | DS1086LU+-ND | C1519863 | DS1086LU+ | Analog Devices Inc./Maxim Integrated | IC I2C SS CLOCK GENERATOR uSOP8
J202,J301 | Conn_02x03 | 2 |  | 2057-PH2-06-UA-ND |  | PH2-06-UA | Adam Tech | CONN HEADER VERT 6POS 2.54MM
J201 | Conn_02x40_Top_Bottom | 1 |  | 2057-PH2RA-80-UA-ND |  | PH2RA-80-UA | Adam Tech | CONN HEADER R/A 80POS 2.54MM
H1,H2,H3,H4,H5 | MountingHole | 5

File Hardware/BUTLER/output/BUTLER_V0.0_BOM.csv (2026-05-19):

Reference | Value | Footprint | Qty | DNP | Digikey | LCSC Part # | MPN | Manufacturer | Voltage | Description
C202,C203,C206,C207,C301,C302,C306,C307,C308,C309,C310,C311,C314,C315,C318,C319,C402,C403,C406,C407,C410,C411,C505,C506,C507,C508,C509,C510,C511,C515,C516 | 100nF | Capacitor_SMD:C_0603_1608Metric | 31 |  | 311-1344-1-ND | C14663 | CC0603KRX7R9BB104 | YAGEO | 50V | CAP CER 0.1UF 50V X7R 0603
C504,C520,C521 | 100nF | Capacitor_SMD:C_0603_1608Metric | 3 | DNP | 311-1344-1-ND | C14663 | CC0603KRX7R9BB104 | YAGEO | 50V | CAP CER 0.1UF 50V X7R 0603
C201,C204,C205,C208,C303,C304,C305,C312,C313,C316,C317,C401,C404,C405,C408,C409,C412,C501,C503,C512,C513,C514,C517,C518 | 4.7uF | Capacitor_SMD:C_0603_1608Metric | 24 |  | 1276-1784-1-ND | C19666 | CL10A475KO8NNNC | Yaego | 16V | CAP CER 4.7UF 16V X5R 0603
C519,C522,C523 | 4.7uF | Capacitor_SMD:C_0603_1608Metric | 3 | DNP | 1276-1784-1-ND | C19666 | CL10A475KO8NNNC | Yaego | 16V | CAP CER 4.7UF 16V X5R 0603
R301,R302,R303,R304,R305,R501,R502,R503 | 10K | Resistor_SMD:R_0603_1608Metric | 8 |  | 311-10.0KHRCT-ND | C98220 | RC0603FR-0710KL | Yaego |  | RES 10K OHM 1% 1/10W 0603
S501 | 1825910-6 | digikey-footprints:Switch_Tactile_THT_6x6mm | 1 |  | 450-1650-ND |  | 1825910-6 | TE Connectivity ALCOSWITCH Switches |  | SWITCH TACTILE SPST-NO 0.05A 24V
R504 | 1K00 | Resistor_SMD:R_0603_1608Metric | 1 |  | 311-1.00KHRCT-ND | C22548 | RC0603FR-071KL | Yaego |  | RES 1K OHM 1% 1/10W 0603
R505,R508 | 2K32 | Resistor_SMD:R_0603_1608Metric | 2 |  | 311-2.32KHRCT-ND | C137749 | RC0603FR-072K32L | Yaego |  | RES 2K32 OHM 1% 1/10W 0603
R506,R507 | 5K1 | Resistor_SMD:R_0603_1608Metric | 2 |  | 311-5.10KHRCT-ND | C105580 | RC0603FR-075K1L | Yaego |  | RES 5.1K OHM 1% 1/10W 0603
U502 | 74AHC1G09GW,125 | Package_TO_SOT_SMD:SOT-353_SC-70-5 | 1 |  | 1727-6017-1-ND | C730245 | 74AHC1G09GW,125 | Nexperia USA Inc. |  | IC GATE AND 1CH 2-INP OPEN DRAIN 5TSSOP
U503,U504 | 74LVC1G38GW,125 | Package_TO_SOT_SMD:SOT-353_SC-70-5 | 2 |  | 1727-6077-1-ND | C548373 | 74LVC1G38GW,125 | Nexperia USA Inc. |  | IC GATE NAND 1CH 2-INP OPEN DRAIN 5TSSOP
U505 | AZ1117CH-5.0TRG1 | Package_TO_SOT_SMD:SOT-223 | 1 |  | AZ1117CH-5.0TRG1DICT-ND | C99342 | AZ1117CH-5.0TRG1 | Diodes Inc |  | IC REG LINEAR 5.0V 1A SOT223
D504 | B320B-13-F | Diode_SMD:D_SMB | 1 |  | B320B-FDICT-ND | C134449 | B320B-13-F | Diodes Inc |  | DIODE SCHOTTKY 20V 3A SMB
FB1,FB501,FB502 | BLM21PG121SN1D | Inductor_SMD:L_0805_2012Metric | 3 |  | 490-5986-1-ND | C79382 | BLM21PG121SN1D | Murata Electronics North America |  | FERRITE BEAD 120 OHM 0805 3A
J201,J202,J401,J402,J403 | Conn_02x40_Top_Bottom | WTM_Library:PinSocket_2x40_P2.54mm_Horizontal_RCBUS80,WTM_Library:PinSocket_2x40_P2.54mm_Vertical_RCBUS80 | 5 |  |  | C7500806 |  |  |  | CONN RCPT 80POS 0.1 TIN PCB R/A,Generic connector, double row, 02x40, top/bottom pin numbering scheme (row 1: 1...pins_per_row, row2: pins_per_row+1 ... num_pins), script generated (kicad-library-utils/schlib/autogen/connector/)
J203 | Conn_02x40_Top_Bottom | WTM_Library:PinSocket_2x40_P2.54mm_Horizontal_RCBUS80,WTM_Library:PinSocket_2x40_P2.54mm_Vertical_RCBUS80 | 1 |  | 612-SSW-140-02-T-D-RA-ND | C22385332 | SSW-140-02-T-D-RA | Samtec Inc. |  | CONN RCPT 80POS 0.1 TIN PCB R/A,Generic connector, double row, 02x40, top/bottom pin numbering scheme (row 1: 1...pins_per_row, row2: pins_per_row+1 ... num_pins), script generated (kicad-library-utils/schlib/autogen/connector/)
D501,D502,D503 | LED_LTST-S270KGKT | WTM_Library:LTST-S270KGKT | 3 |  | 160-1478-1-ND | C125113 | LTST-S270KGKT | Lite-On Inc. |  | LED 571NM GREEN CLEAR CHIP 0603 R/A
J501 | PJ-002A | WTM_Library:CUI_PJ-002A | 1 |  | CP-002A-ND |  | PJ-002A |  |  | CONN PWR JACK 2X5.5MM SOLDER
J502 | Screw_Terminal_01x02 | WTM_Library:CUI_TB001-500-02BE | 1 |  | 102-6134-ND |  | TB001-500-02BE | CUI Devices |  | TERM BLOCK, SCREW TYPE, 5.00MM PCB
Z501 | SMBJ5.0A | Diode_SMD:D_SMB | 1 |  | SMBJ5.0ALFCT-ND | C110528 | SMBJ5.0A | Littlefuse |  | TVS DIODE 5VWM 9.2VC DO214AA
U301,U302 | SN74CBT3861PWR | Package_SO:TSSOP-24_4.4x7.8mm_P0.65mm | 2 |  | 296-6483-1-ND | C44508 | SN74CBTD3861DBQR | Texas Instruments |  | 10-bit FET bus switch
U303,U304,U305,U306,U307 | SN74LVC8T245DBR | Package_SO:SSOP-24_5.3x8.2mm_P0.65mm | 5 |  | 296-21065-1-ND | C19197 | SN74LVC8T245DBR | Texas Instruments |  | IC TRANSLATION TXRX 5.5V 24SSOP
U506 | TLV1117LV33DCYR | Package_TO_SOT_SMD:SOT-223 | 1 | DNP | 296-28778-1-ND | C15578 | TLV1117LV33DCYR | Texas Instruments |  | IC REG LINEAR 3.3V 1A SOT223-4
U501 | TPS3808EG50DBVR | Package_TO_SOT_SMD:TSOT-23-6_HandSoldering | 1 |  | 296-TPS3808EG50DBVRCT-ND | C134123 | TPS3808EG50DBVR | Texas Instruments |  | IC VOLT SUPERVISOR 5V SOT23-6
J503 | USB_C_Receptacle_USB2.0 | WTM_Library:USB_C_Receptacle_HRO_TYPE-C-31-M-12 | 1 |  | 2073-USB4105-GF-ACT-ND | C167321 | USB4105-GF-A | GCT |  | CONN RCP USB2.0 TYP C 24P SMD RA

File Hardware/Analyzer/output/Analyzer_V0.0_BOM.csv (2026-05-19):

Reference | Value | Footprint | Qty | DNP | Digikey | LCSC Part # | MPN | Manufacturer | Description
Z201 | SMBJ5.0A | Diode_SMD:D_SMB | 1 |  | SMBJ5.0ALFCT-ND | C110528 | SMBJ5.0A | Littlefuse | TVS DIODE 5VWM 9.2VC DO214AA
U301,U302,U303,U401,U402,U403,U502,U503,U504 | 74LVCH245APW,118 | Package_SO:TSSOP-20_4.4x6.5mm_P0.65mm | 9 |  | 1727-4041-1-ND | C426764 | 74LVCH245APW,118 | Nexperia USA Inc. | IC TXRX NON-INVERT 3.6V 20-TSSOP
S201 | 1825910-6 | digikey-footprints:Switch_Tactile_THT_6x6mm | 1 |  | 450-1650-ND |  | 1825910-6 | TE Connectivity ALCOSWITCH Switches | SWITCH TACTILE SPST-NO 0.05A 24V
R302 | 2.2K | Resistor_SMD:R_0603_1608Metric | 1 |  | 311-2.20KHRCT-ND | C114662 | RC0603FR-072K2L | Yaego | RES 2.2K OHM 1% 1/10W 0603
R301,R401,R502 | 10K | Resistor_SMD:R_0603_1608Metric | 3 |  | 311-10.0KHRCT-ND | C98220 | RC0603FR-0710KL | Yaego | RES 10K OHM 1% 1/10W 0603
R202,R203 | 5K1 | Resistor_SMD:R_0603_1608Metric | 2 |  | 311-5.10KHRCT-ND | C105580 | RC0603FR-075K1L | Yaego | RES 5.1K OHM 1% 1/10W 0603
R201 | 0R | Resistor_SMD:R_0603_1608Metric | 1 |  | 311-0.0GRCT-ND | C95177 | RC0603JR-070RL | Yaego | RES 0 OHM 5% 1/10W 0603
J301,J401,J501 | Conn_01x02 | Connector_PinHeader_2.54mm:PinHeader_1x02_P2.54mm_Vertical | 3 |  | 2057-PH2-02-UA-ND |  | PH2-02-UA | Adam Tech | CONN HEADER VERT 2POS 2.54MM
J202 | USB_C_Receptacle_USB2.0 | WTM_Library:USB_C_Receptacle_HRO_TYPE-C-31-M-12 | 1 |  | 2073-USB4105-GF-ACT-ND | C167321 | USB4105-GF-A | GCT | CONN RCP USB2.0 TYP C 24P SMD RA
J201 | Conn_02x40_Top_Bottom | WTM_Library:RCBUS_PinHeader_2x40_P2.54mm_Horizontal | 1 |  | 2057-PH2RA-80-UA-ND |  | PH2RA-80-UA | Adam Tech | CONN HEADER R/A 80POS 2.54MM
H4 | MountingHole | MountingHole:MountingHole_2.7mm_M2.5_DIN965 | 1
FB201,FB202 | BLM21PG121SN1D | Inductor_SMD:L_0805_2012Metric | 2 |  | 490-5986-1-ND | C79382 | BLM21PG121SN1D | Murata Electronics North America | FERRITE BEAD 120 OHM 0805 3A
D201 | B320B-13-F | Diode_SMD:D_SMB | 1 |  | B320B-FDICT-ND | C134449 | B320B-13-F | Diodes Inc | DIODE SCHOTTKY 20V 3A SMB
C203,C204,C205,C206,C302,C305,C307,C402,C405,C407,C502,C505,C507 | 4.7uF | Capacitor_SMD:C_0603_1608Metric | 13 |  | 1276-1784-1-ND | C19666 | CL10A475KO8NNNC | Yaego | CAP CER 4.7UF 16V X5R 0603
C201,C202,C301,C303,C304,C306,C308,C401,C403,C404,C406,C408,C501,C503,C504,C506,C508 | 100nF | Capacitor_SMD:C_0603_1608Metric | 17 |  | 311-1344-1-ND | C14663 | CC0603KRX7R9BB104 | YAGEO | CAP CER 0.1UF 50V X7R 0603
A301,A401,A501 | RaspberryPi_Pico2W | Module:RaspberryPi_Pico_Common_THT | 3 |  | 2648-SC1634-ND |  | SC1634 | Raspberry Pi | RASPBERRY PI PICO 2 WH RP2350

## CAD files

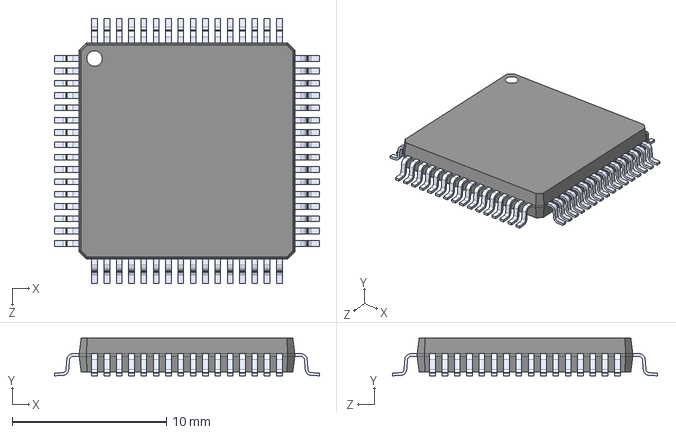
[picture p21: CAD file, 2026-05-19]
Hardware/SPIFEE/SPIFEE-3D/MC68SEC000FU20--3DModel-STEP-56544.STEP
17.2 x 2.45 x 17.2 mm

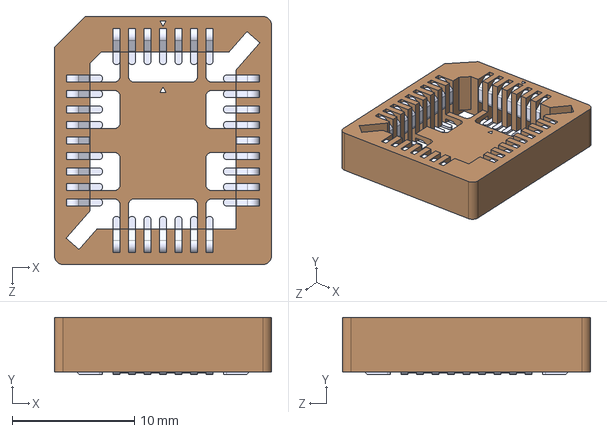
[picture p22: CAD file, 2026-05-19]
Hardware/SPIFEE/SPIFEE-3D/PLCC32_SMT_SOCKET_69802-132LF--3DModel-STEP-554624.STEP
17.8 x 4.70 x 20.3 mm

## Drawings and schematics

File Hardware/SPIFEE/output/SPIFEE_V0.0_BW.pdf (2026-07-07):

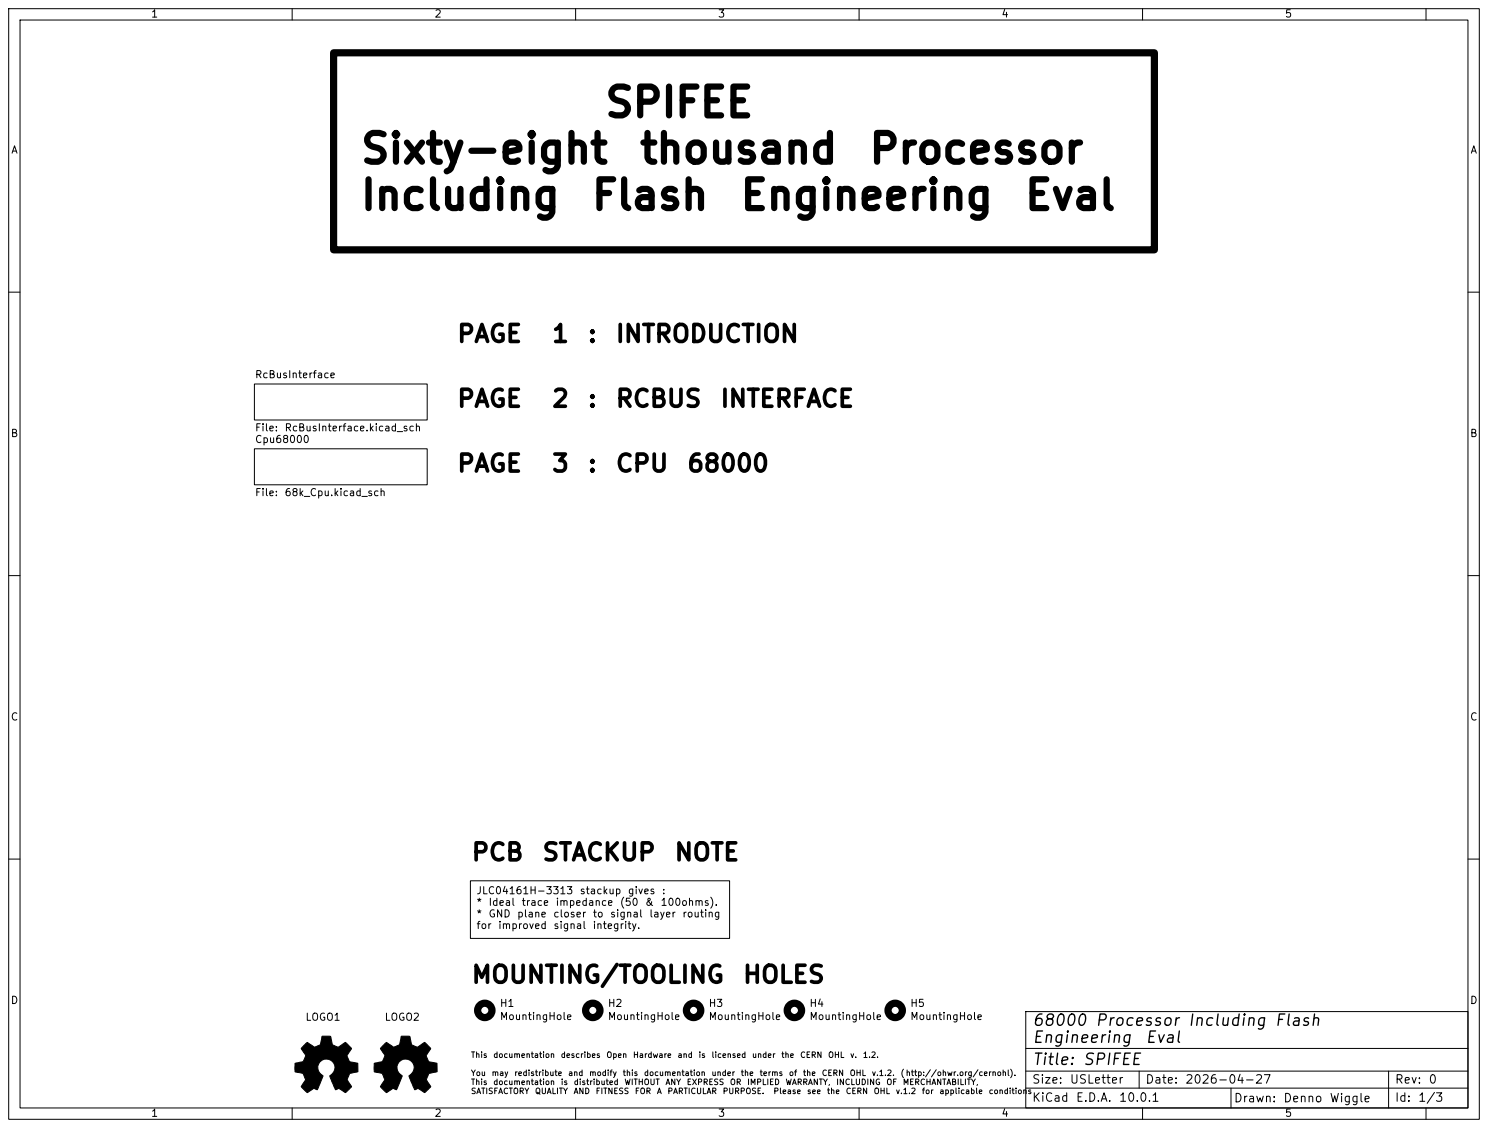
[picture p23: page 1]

Sixty-eight thousand Processor
Including Flash Engineering Eval

This documentation describes Open Hardware and is licensed under the CERN OHL v. 1.2. You may redistribute and modify this documentation under the terms of the CERN OHL v.1.2. ( http://ohwr.org/cernohl). This documentation is distributed WITHOUT ANY EXPRESS OR IMPLIED WARRANTY, INCLUDING OF MERCHANTABILITY, SATISFACTORY QUALITY AND FITNESS FOR A PARTICULAR PURPOSE. Please see the CERN OHL v.1.2 for applicable conditions PAGE 1 : INTRODUCTION

JLC04161H-3313 stackup gives : * Ideal trace impedance (50 & 100ohms). * GND plane closer to signal layer routing

for improved signal integrity.
MOUNTING/TOOLING HOLES

Size: USLetter | | Rev: 0
KiCad E.D.A. 10.0.1 | Drawn: Denno Wiggle | Id: 1/3

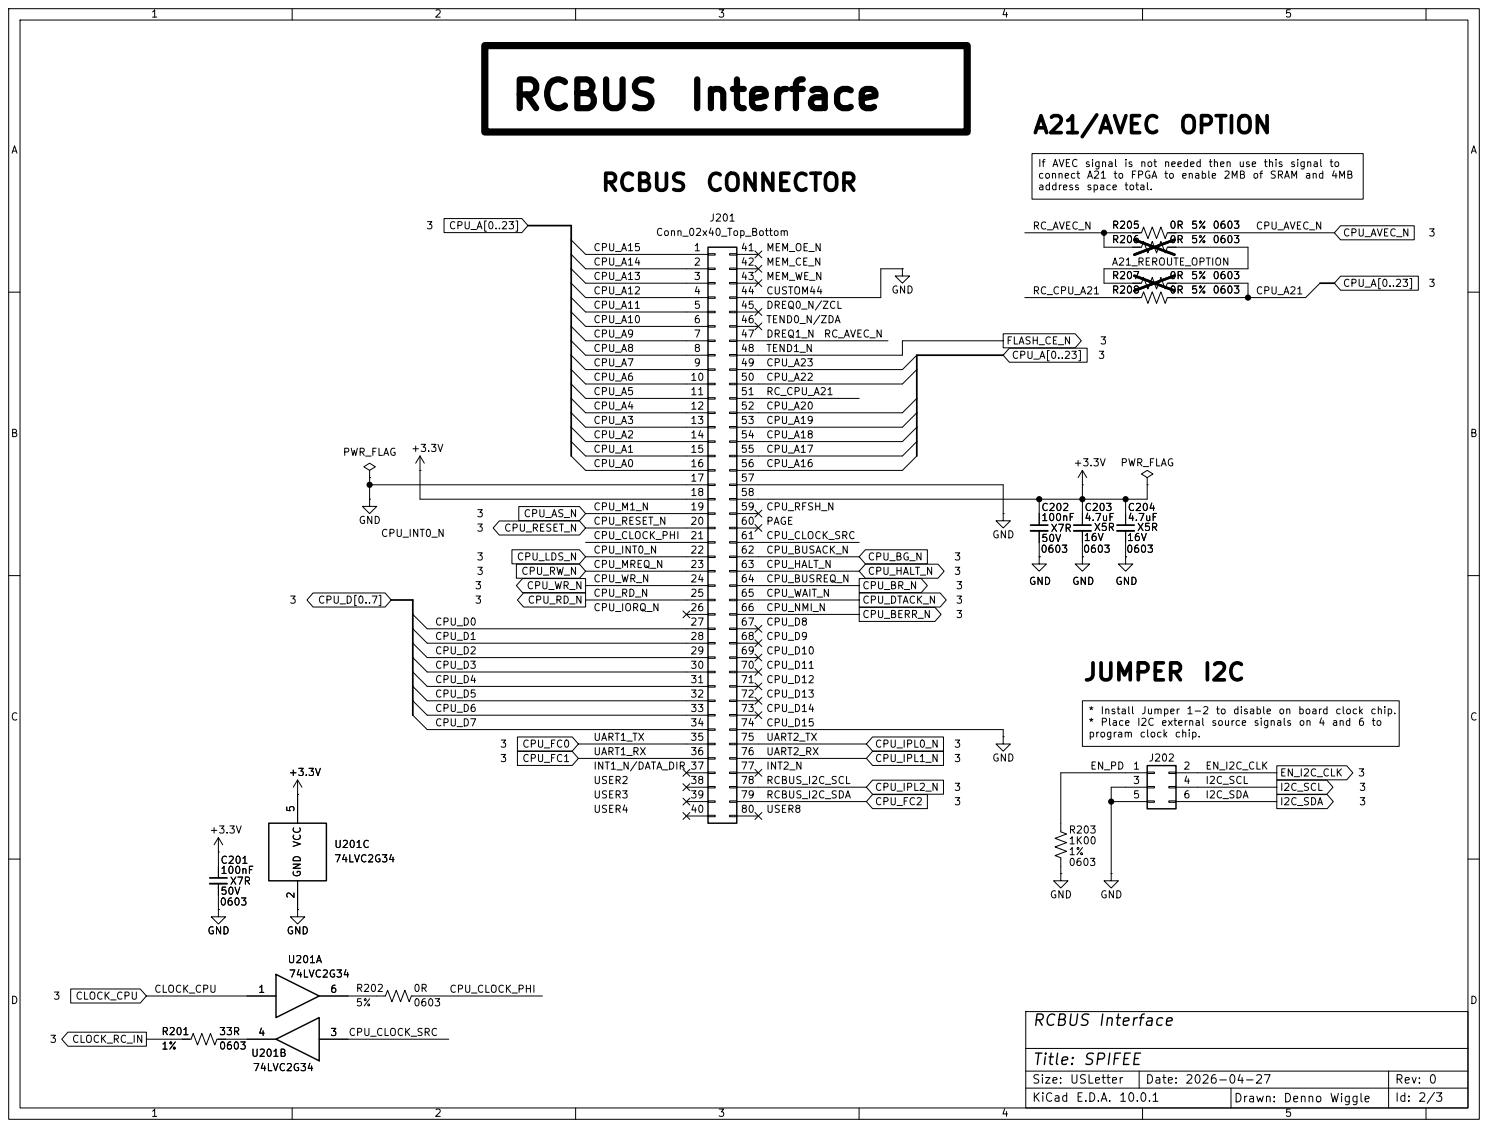
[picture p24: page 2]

address space total. RCBUS Interface
CUSTOM44 PAGE RCBUS_I2C_SDA CPU_D9 RCBUS_I2C_SCL CPU_M1_N RCBUS CONNECTOR

If AVEC signal is not needed then use this signal to
connect A21 to FPGA to enable 2MB of SRAM and 4MB

* Install Jumper 1-2 to disable on board clock chip. * Place I2C external source signals on 4 and 6 to

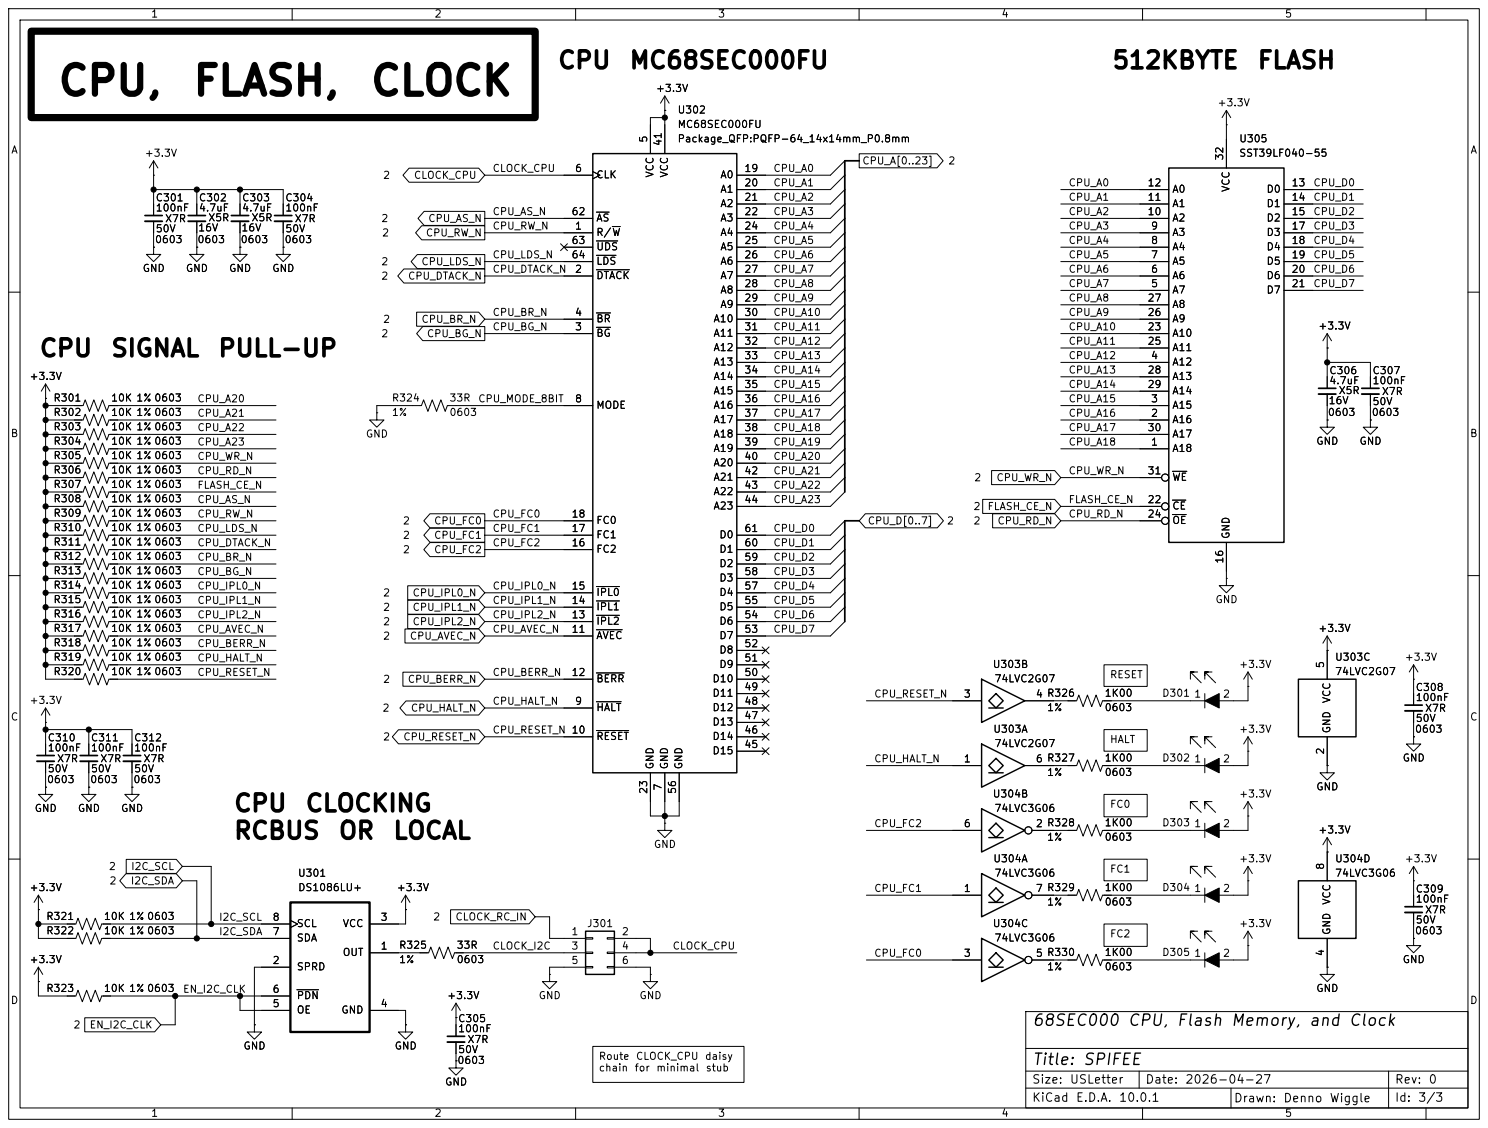
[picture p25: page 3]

CPU SIGNAL PULL-UP

FC2 Route CLOCK_CPU daisy chain for minimal stub

68SEC000 CPU, Flash Memory, and Clock

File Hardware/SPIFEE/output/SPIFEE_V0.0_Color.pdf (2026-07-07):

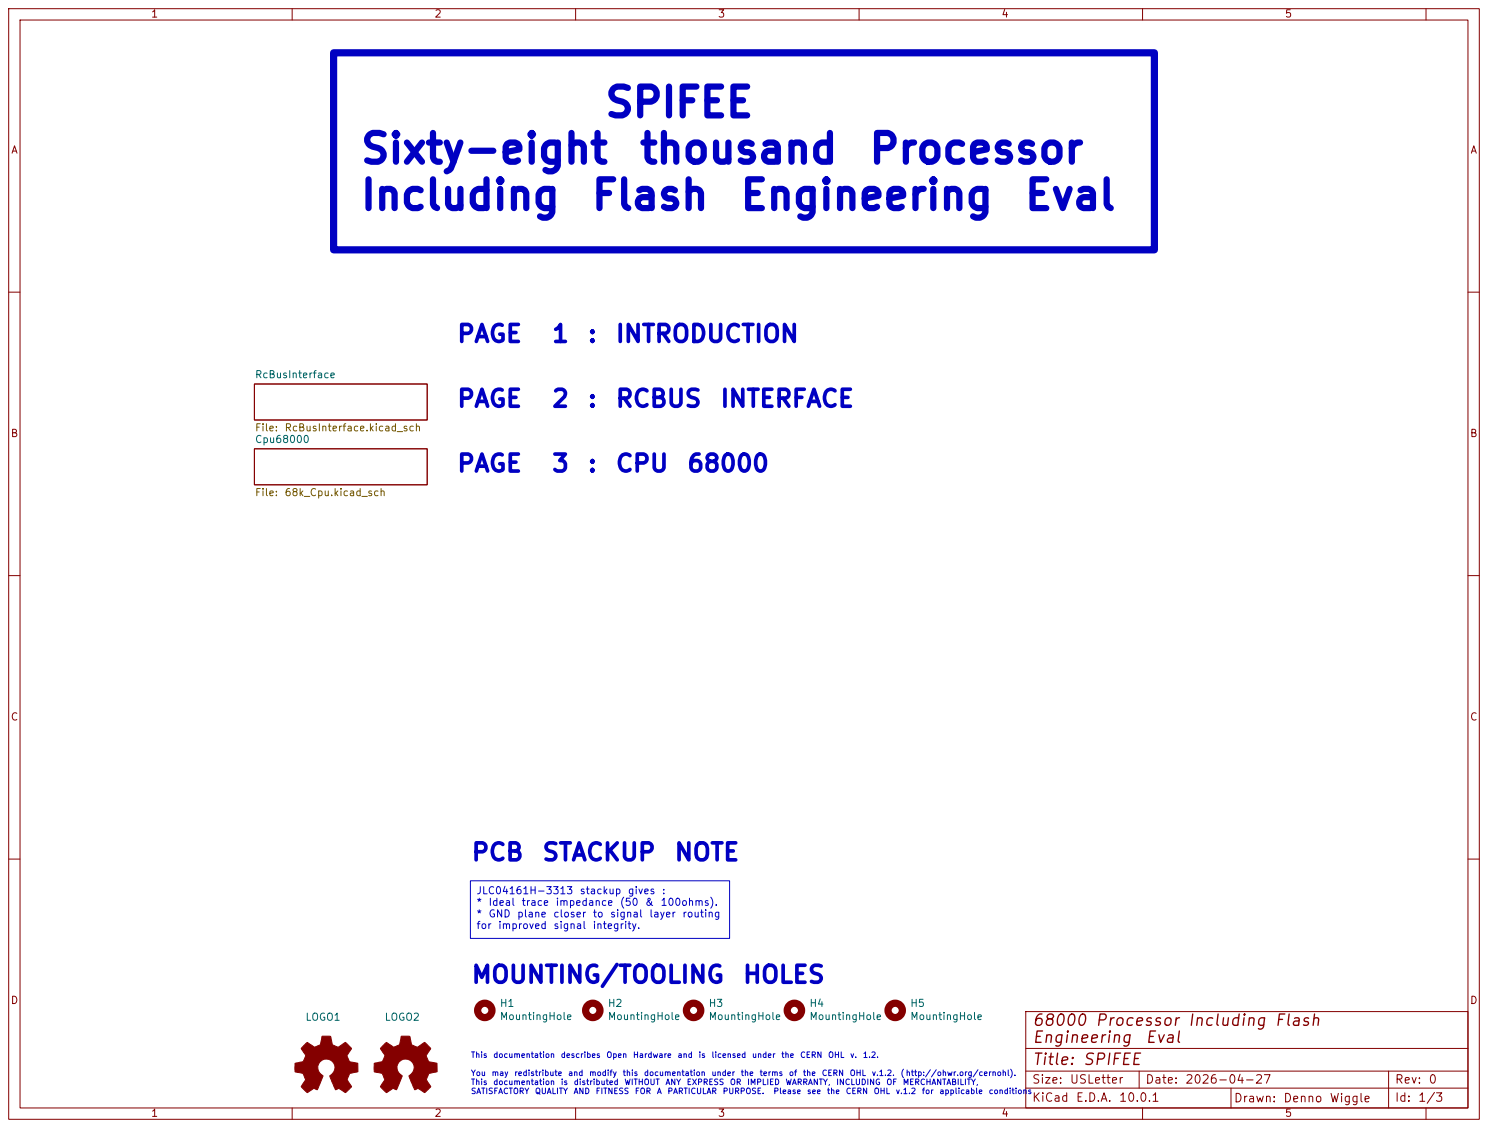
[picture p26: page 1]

Sixty-eight thousand Processor
Including Flash Engineering Eval

This documentation describes Open Hardware and is licensed under the CERN OHL v. 1.2. You may redistribute and modify this documentation under the terms of the CERN OHL v.1.2. ( http://ohwr.org/cernohl). This documentation is distributed WITHOUT ANY EXPRESS OR IMPLIED WARRANTY, INCLUDING OF MERCHANTABILITY, SATISFACTORY QUALITY AND FITNESS FOR A PARTICULAR PURPOSE. Please see the CERN OHL v.1.2 for applicable conditions PAGE 1 : INTRODUCTION

JLC04161H-3313 stackup gives : * Ideal trace impedance (50 & 100ohms). * GND plane closer to signal layer routing

for improved signal integrity.
MOUNTING/TOOLING HOLES

Size: USLetter | | Rev: 0
KiCad E.D.A. 10.0.1 | Drawn: Denno Wiggle | Id: 1/3

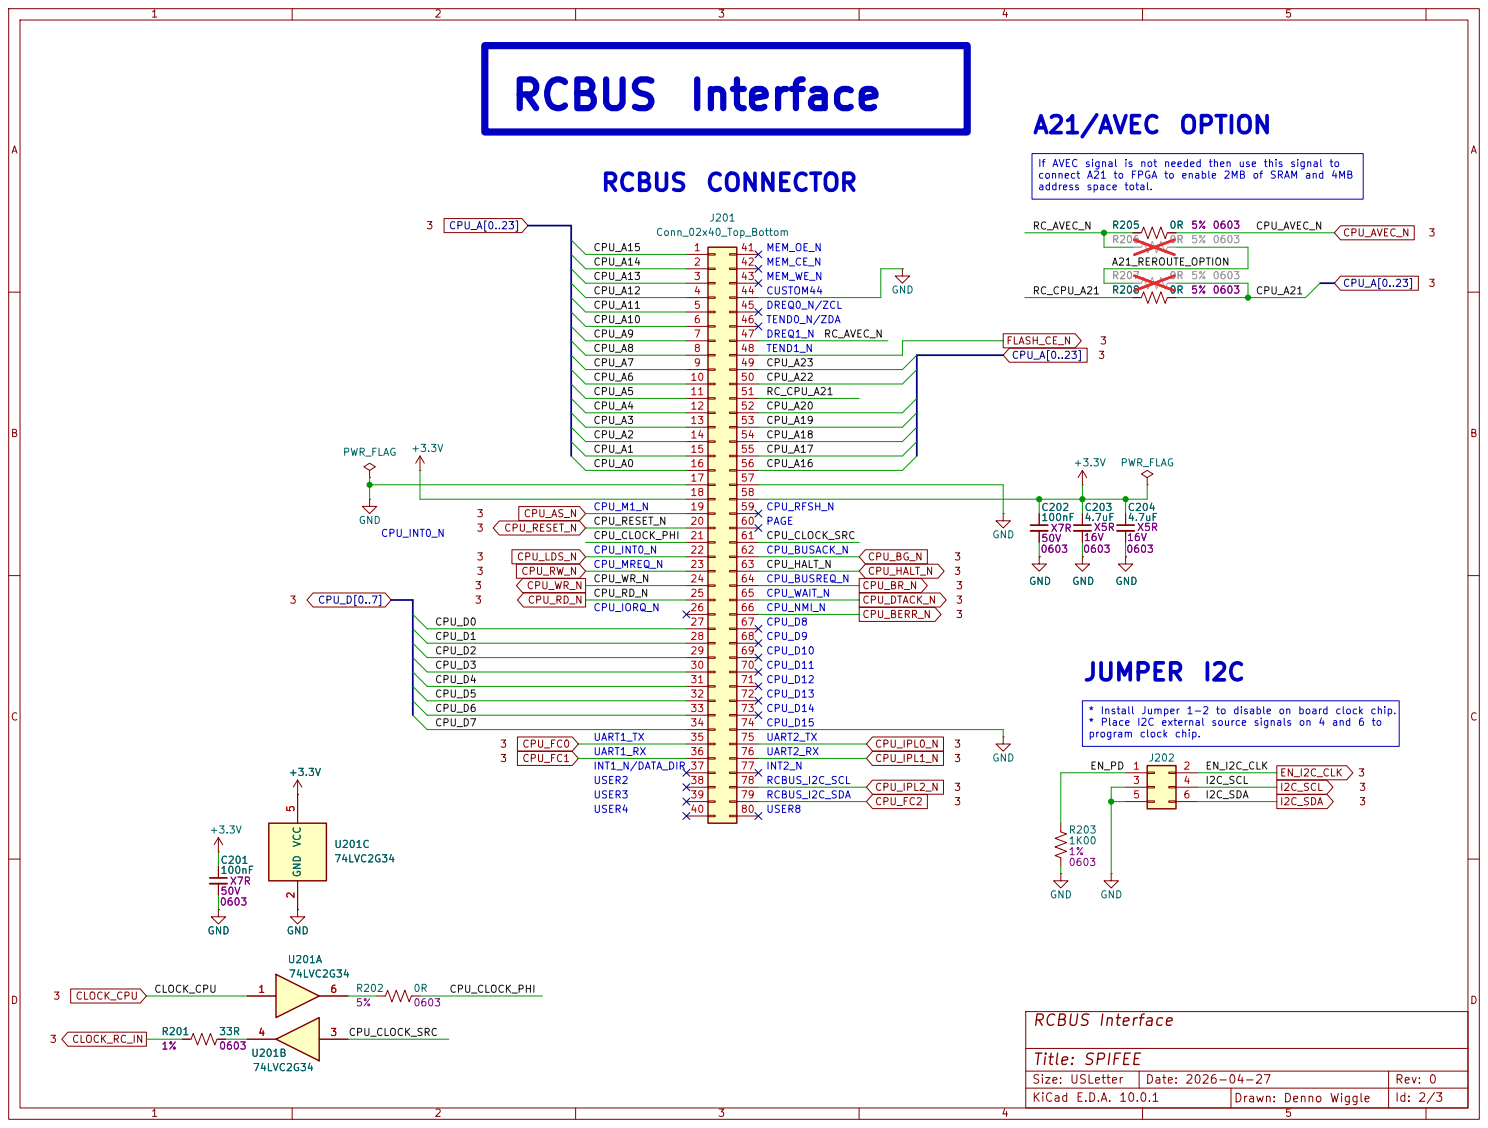
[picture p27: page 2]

If AVEC signal is not needed then use this signal to
connect A21 to FPGA to enable 2MB of SRAM and 4MB

* Install Jumper 1-2 to disable on board clock chip. * Place I2C external source signals on 4 and 6 to

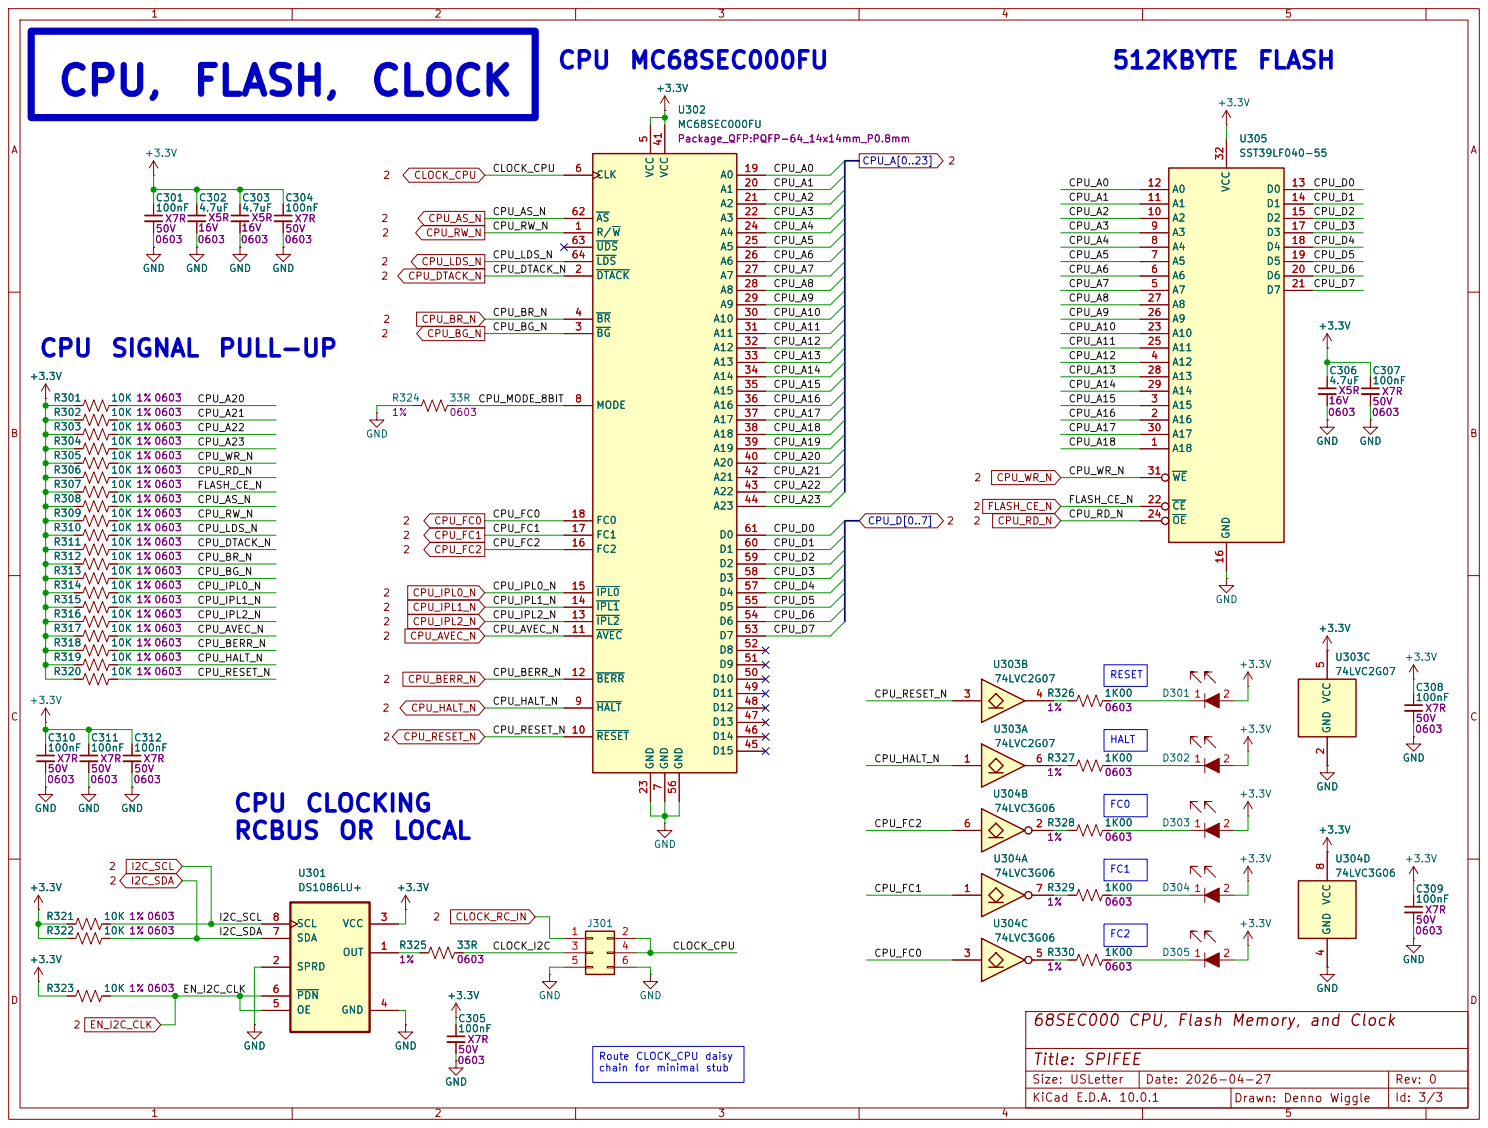
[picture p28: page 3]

68SEC000 CPU, Flash Memory, and Clock

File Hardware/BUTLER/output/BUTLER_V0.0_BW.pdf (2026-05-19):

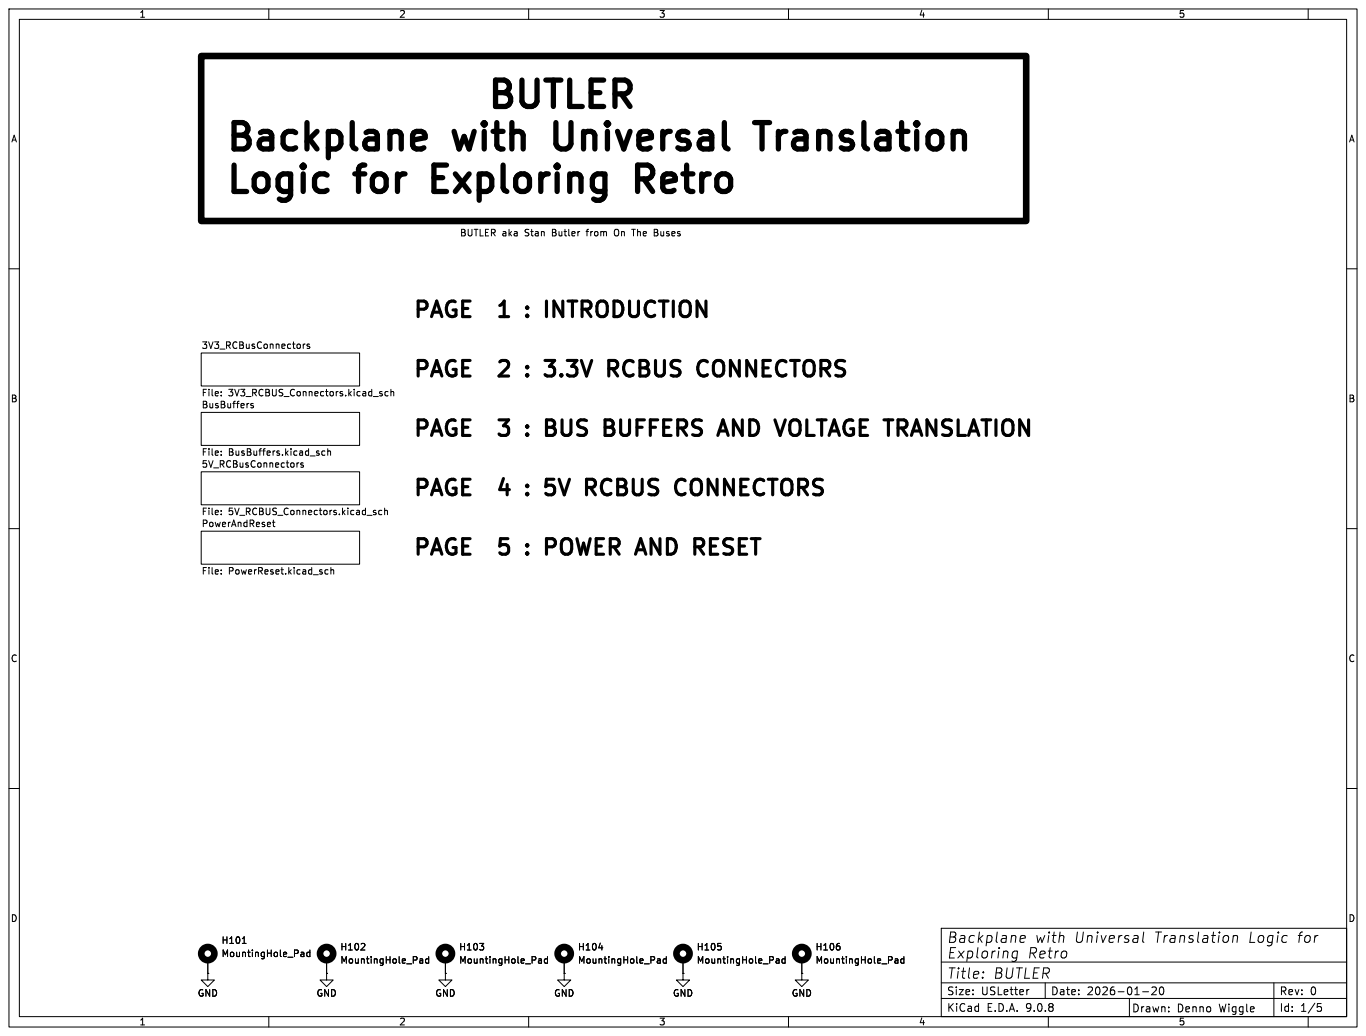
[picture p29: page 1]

Backplane with Universal Translation
Logic for Exploring Retro

5V_RCBusConnectors File: 5V_RCBUS_Connectors.kicad_sch PowerAndReset File: PowerReset.kicad_sch

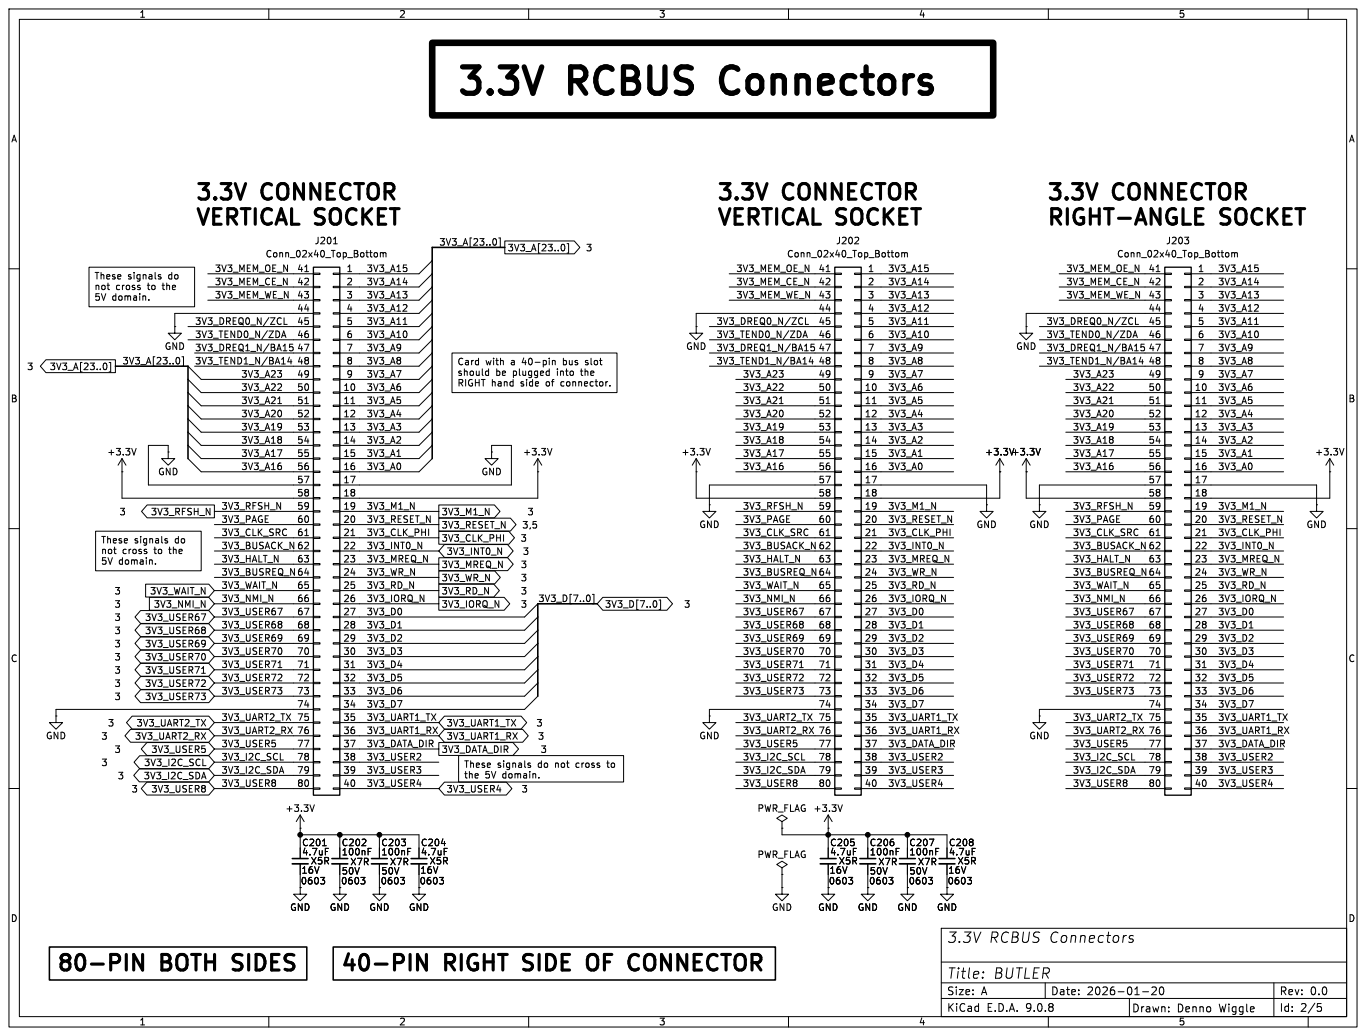
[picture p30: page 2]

5V domain. These signals do
not cross to the

the 5V domain. These signals do

3V3_D5 These signals do not cross to

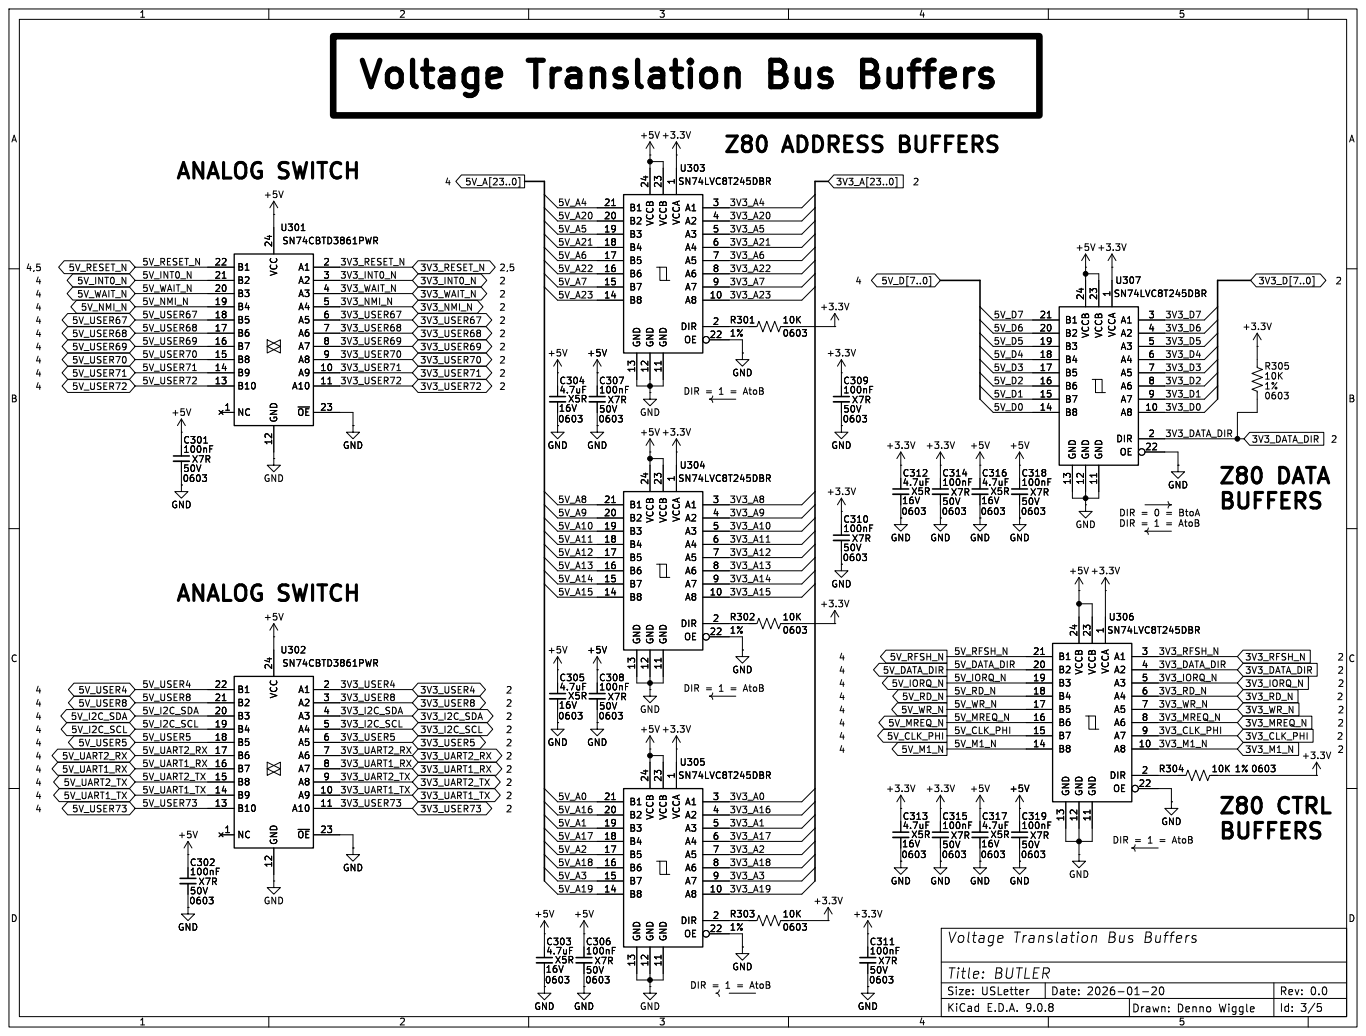
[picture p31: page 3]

5V_A7 Voltage Translation Bus Buffers

DIR = 1 = AtoB Z80 ADDRESS BUFFERS

DIR = 0 = BtoA DIR = 1 = AtoB ANALOG SWITCH

1 VCCB 23 GND 11 VCCB 24 GND 12 GND 13 B1 21 B2 20 B3 19 B4 18 B5 17 B6 16 B7 15 B8 14 U303 SN74LVC8T245DBR

1 VCCB 23 GND 11 VCCB 24 GND 12 GND 13 B1 21 B2 20 B3 19 B4 18 B5 17 B6 16 B7 15 B8 14 GND

1 VCCB 23 GND 11 VCCB 24 GND 12 GND 13 B1 21 B2 20 B3 19 B4 18 B5 17 B6 16 B7 15 B8 14 U307 SN74LVC8T245DBR

1 VCCB 23 GND 11 VCCB 24 GND 12 GND 13 B1 21 B2 20 B3 19 B4 18 B5 17 B6 16 B7 15 B8 14 U304 SN74LVC8T245DBR GND

1 VCCB 23 GND 11 VCCB 24 GND 12 GND 13 B1 21 B2 20 B3 19 B4 18 B5 17 B6 16 B7 15 B8 14 U306 SN74LVC8T245DBR GND

1 VCCB 23 GND 11 VCCB 24 GND 12 GND 13 B1 21 B2 20 B3 19 B4 18 B5 17 B6 16 B7 15 B8 14 R304 10K 1% 0603 GNDGND

DIR = 1 = AtoB ANALOG SWITCH

1 VCCB 23 GND 11 VCCB 24 GND 12 GND 13 B1 21 B2 20 B3 19 B4 18 B5 17 B6 16 B7 15 B8 14 U305 SN74LVC8T245DBR

1 VCCB 23 GND 11 VCCB 24 GND 12 GND 13 B1 21 B2 20 B3 19 B4 18 B5 17 B6 16 B7 15 B8 14 R303 10K

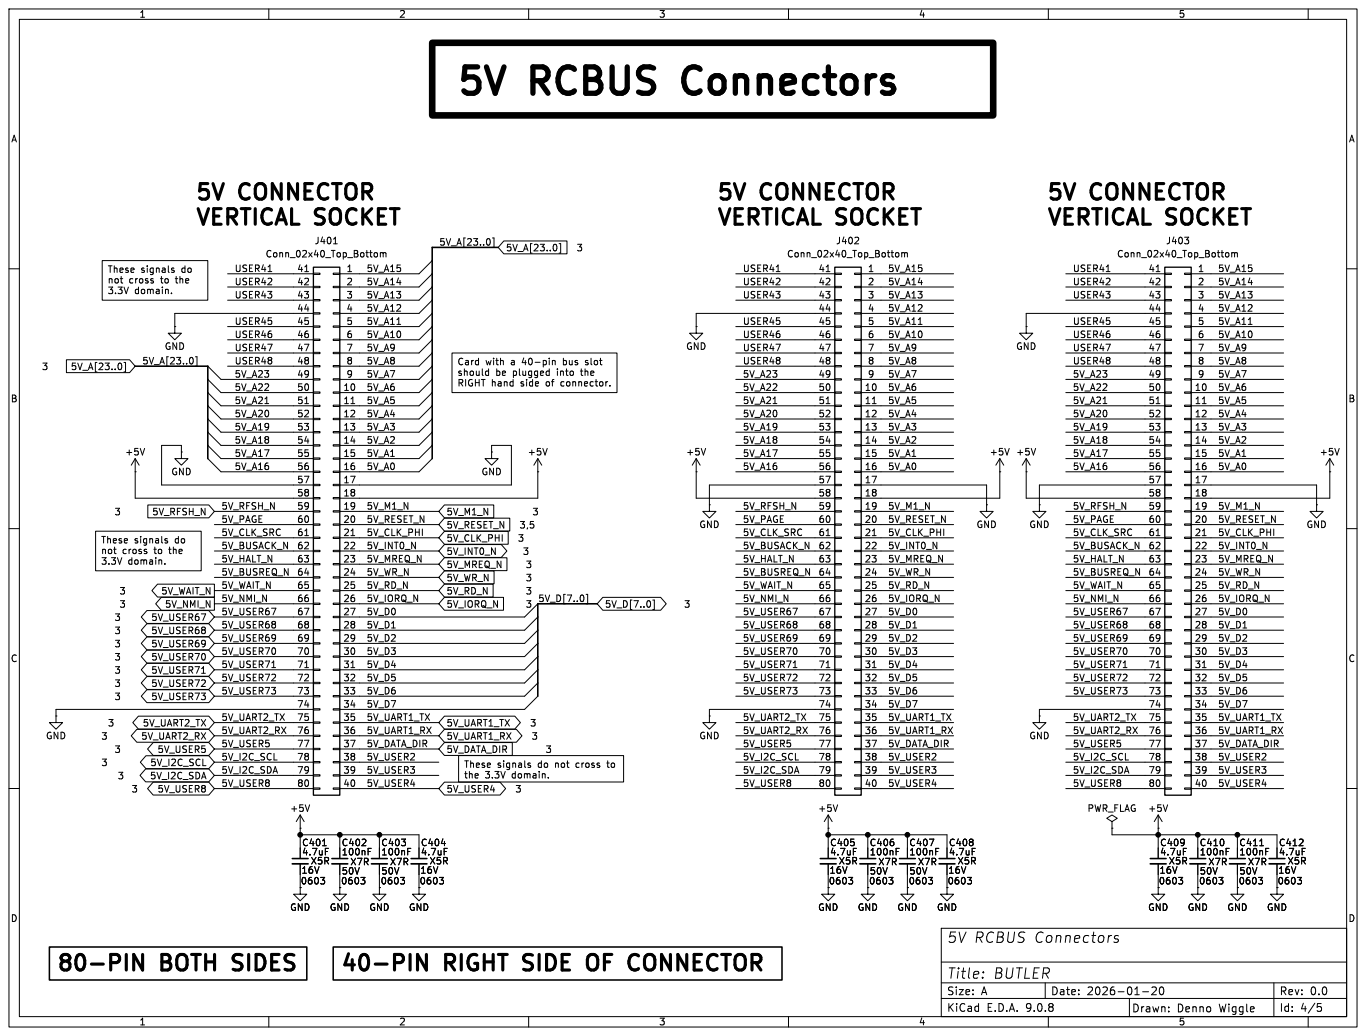
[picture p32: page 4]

5V_A11 These signals do
not cross to the

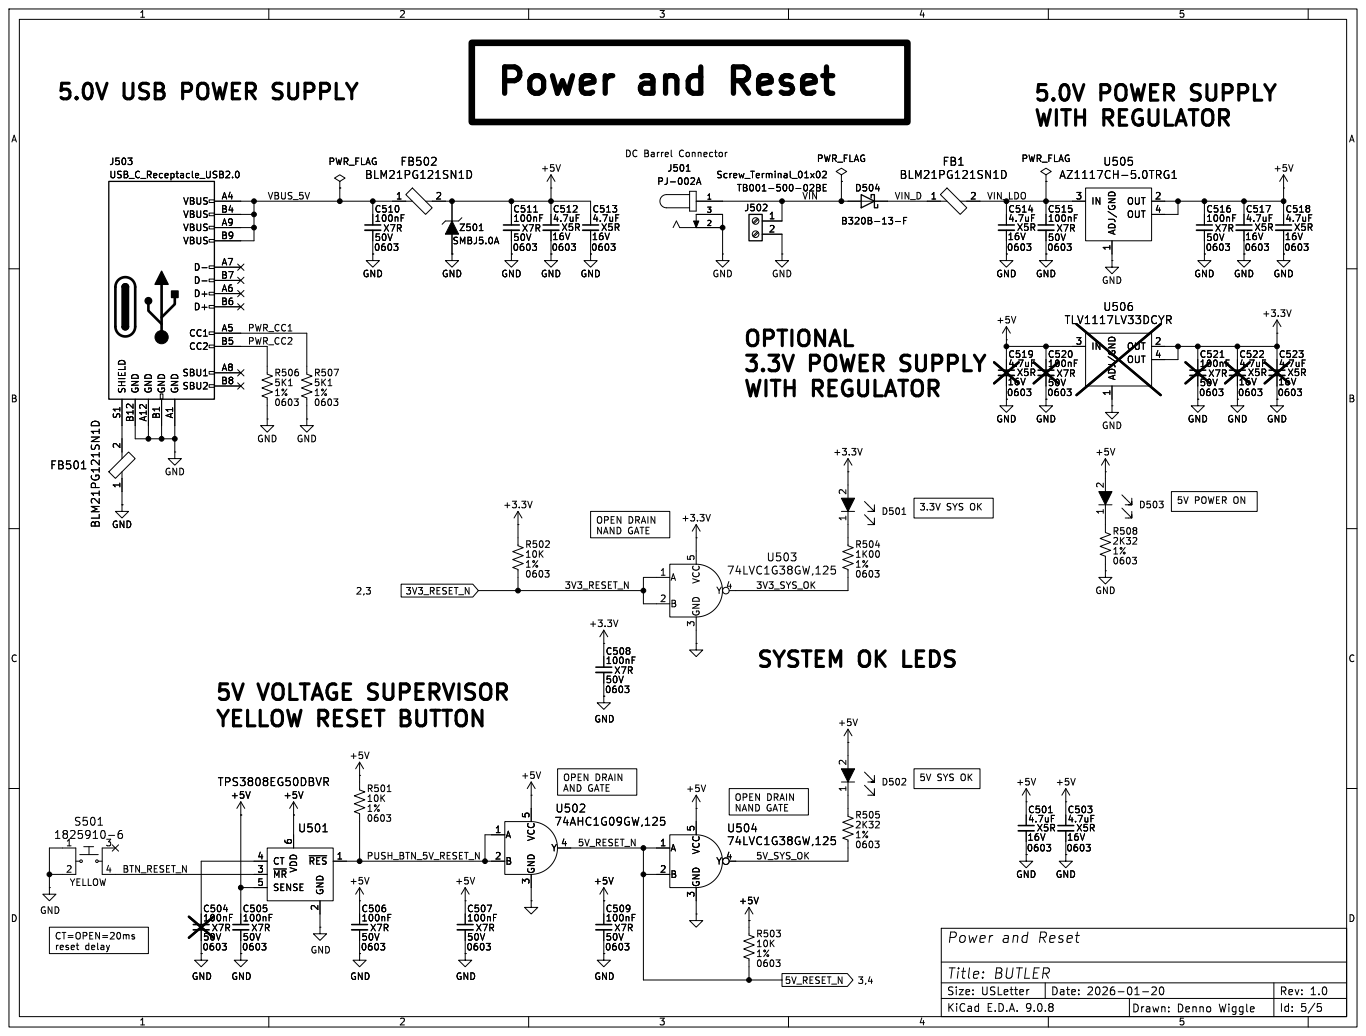
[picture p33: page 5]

5V SYS OK Power and Reset

3.3V SYS OK DC Barrel Connector YELLOW RESET BUTTON

5V POWER ON OPEN DRAIN
NAND GATE OPEN DRAIN
NAND GATE

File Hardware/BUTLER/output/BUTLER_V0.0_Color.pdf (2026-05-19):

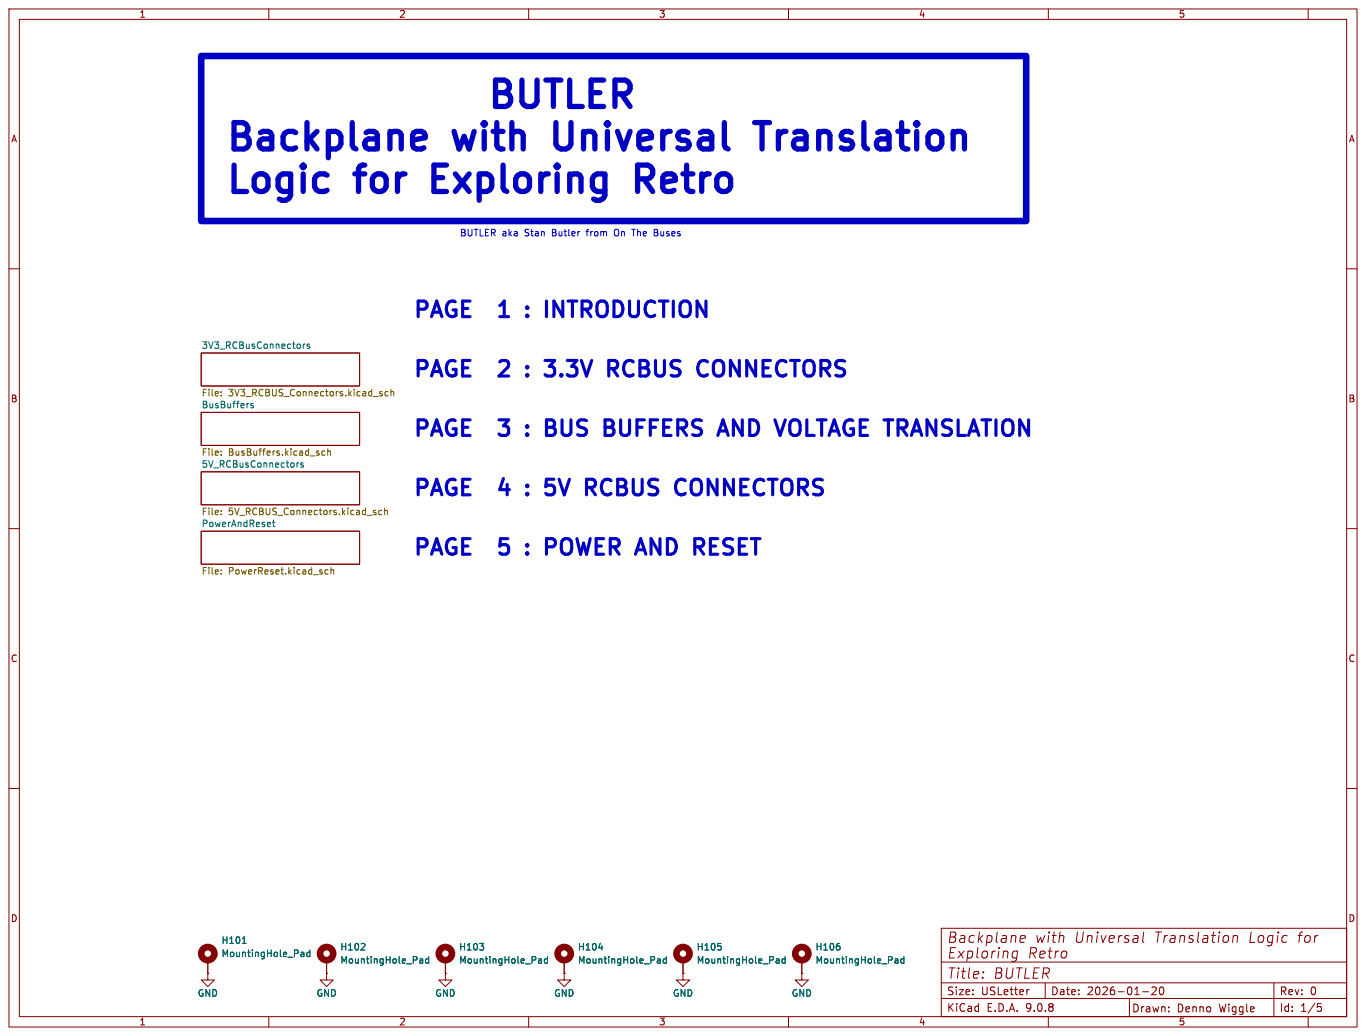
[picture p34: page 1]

3V3_RCBusConnectors File: 3V3_RCBUS_Connectors.kicad_sch BusBuffers File: BusBuffers.kicad_sch GND

Backplane with Universal Translation
Logic for Exploring Retro

5V_RCBusConnectors File: 5V_RCBUS_Connectors.kicad_sch PowerAndReset File: PowerReset.kicad_sch


5V domain. These signals do
not cross to the

the 5V domain. These signals do

3V3_D5 These signals do not cross to


5V_A7 Voltage Translation Bus Buffers

DIR = 1 = AtoB Z80 ADDRESS BUFFERS

DIR = 0 = BtoA DIR = 1 = AtoB ANALOG SWITCH

1 VCCB 23 GND 11 VCCB 24 GND 12 GND 13 B1 21 B2 20 B3 19 B4 18 B5 17 B6 16 B7 15 B8 14 U303 SN74LVC8T245DBR

1 VCCB 23 GND 11 VCCB 24 GND 12 GND 13 B1 21 B2 20 B3 19 B4 18 B5 17 B6 16 B7 15 B8 14 GND

1 VCCB 23 GND 11 VCCB 24 GND 12 GND 13 B1 21 B2 20 B3 19 B4 18 B5 17 B6 16 B7 15 B8 14 +5V U301 SN74CBTD3861PWR

1 VCCB 23 GND 11 VCCB 24 GND 12 GND 13 B1 21 B2 20 B3 19 B4 18 B5 17 B6 16 B7 15 B8 14 U307 SN74LVC8T245DBR

1 VCCB 23 GND 11 VCCB 24 GND 12 GND 13 B1 21 B2 20 B3 19 B4 18 B5 17 B6 16 B7 15 B8 14 U306 SN74LVC8T245DBR GND

1 VCCB 23 GND 11 VCCB 24 GND 12 GND 13 B1 21 B2 20 B3 19 B4 18 B5 17 B6 16 B7 15 B8 14 U304 SN74LVC8T245DBR

1 VCCB 23 GND 11 VCCB 24 GND 12 GND 13 B1 21 B2 20 B3 19 B4 18 B5 17 B6 16 B7 15 B8 14 R304 10K 1% 0603 GNDGND

DIR = 1 = AtoB ANALOG SWITCH

1 VCCB 23 GND 11 VCCB 24 GND 12 GND 13 B1 21 B2 20 B3 19 B4 18 B5 17 B6 16 B7 15 B8 14 U305 SN74LVC8T245DBR

1 VCCB 23 GND 11 VCCB 24 GND 12 GND 13 B1 21 B2 20 B3 19 B4 18 B5 17 B6 16 B7 15 B8 14 R303 10K


5V_A11 These signals do
not cross to the


5V SYS OK Power and Reset

5V POWER ON OPEN DRAIN
NAND GATE OPEN DRAIN
NAND GATE

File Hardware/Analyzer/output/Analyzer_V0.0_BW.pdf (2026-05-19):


Logic Analyzer for RCBUS
using PI PICO 2[W]

PAGE 2 : RCBUS INTERFACE & POWER SUPPLY

PAGE 3 : PI PICO ANALYZER A

PAGE 4 : PI PICO ANALYZER B

PAGE 5 : Pi PICO ANALYZER C

This documentation describes Open Hardware and is licensed under the CERN OHL v. 1.2. You may redistribute and modify this documentation under the terms of the CERN OHL v.1.2. ( http://ohwr.org/cernohl). This documentation is distributed WITHOUT ANY EXPRESS OR IMPLIED WARRANTY, INCLUDING OF MERCHANTABILITY, SATISFACTORY QUALITY AND FITNESS FOR A PARTICULAR PURPOSE. Please see the CERN OHL v.1.2 for applicable conditions BACKGROUND OF DESIGN

This design is a derivative work of John Winans S-100 bus logic
analyzer targeted for RCBUS instead of S-100 bus. https://github.com/johnwinans/2070-S-100-bus-analyzer Both projects use the Dr Gusman software and firmware. https://github.com/gusmanb/logicanalyzer JLC04161H-3313 stackup gives : * Ideal trace impedance (50 & 100ohms). * GND plane closer to signal layer routing

for improved signal integrity.
MOUNTING/TOOLING HOLES

Size: USLetter | | Rev: 0
KiCad E.D.A. 10.0.1 | Drawn: Denno Wiggle | Id: 1/5


RCBUS CARD SOCKET CONNECTOR
40-PIN LEFT SIDE

PUSH BUTTON RESET FOR PICO

RC Bus Connections and Power Supply


8 GPIO6 9 GPIO7 10 GPIO8 11 GPIO9 12 GND 13 GPIO10 14 GPIO11 15 GPIO12 16 GPIO13 17 GND 18 GPIO14 19 GPIO15 20 GPIO16 21 GPIO17 22 GND 23 GPIO18 24 GPIO19 25 GPIO20 26 GPIO21 27 GND 28 GPIO22 29 RUN 30 GPIO26_ADC0 31 GPIO27_ADC1 32

Pi PICO Analyzer Channel A

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

Pi PICO Analyzer Channel B

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

Pi PICO Analyzer Channel C

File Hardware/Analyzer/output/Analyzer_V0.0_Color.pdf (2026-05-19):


Logic Analyzer for RCBUS
using PI PICO 2[W]

PAGE 2 : RCBUS INTERFACE & POWER SUPPLY

PAGE 3 : PI PICO ANALYZER A

PAGE 4 : PI PICO ANALYZER B

PAGE 5 : Pi PICO ANALYZER C

This documentation describes Open Hardware and is licensed under the CERN OHL v. 1.2. You may redistribute and modify this documentation under the terms of the CERN OHL v.1.2. ( http://ohwr.org/cernohl). This documentation is distributed WITHOUT ANY EXPRESS OR IMPLIED WARRANTY, INCLUDING OF MERCHANTABILITY, SATISFACTORY QUALITY AND FITNESS FOR A PARTICULAR PURPOSE. Please see the CERN OHL v.1.2 for applicable conditions BACKGROUND OF DESIGN

This design is a derivative work of John Winans S-100 bus logic
analyzer targeted for RCBUS instead of S-100 bus. https://github.com/johnwinans/2070-S-100-bus-analyzer Both projects use the Dr Gusman software and firmware. https://github.com/gusmanb/logicanalyzer JLC04161H-3313 stackup gives : * Ideal trace impedance (50 & 100ohms). * GND plane closer to signal layer routing

for improved signal integrity.
MOUNTING/TOOLING HOLES

Size: USLetter | | Rev: 0
KiCad E.D.A. 10.0.1 | Drawn: Denno Wiggle | Id: 1/5


RCBUS CARD SOCKET CONNECTOR
40-PIN LEFT SIDE

PUSH BUTTON RESET FOR PICO

RC Bus Connections and Power Supply


8 GPIO6 9 GPIO7 10 GPIO8 11 GPIO9 12 GND 13 GPIO10 14 GPIO11 15 GPIO12 16 GPIO13 17 GND 18 GPIO14 19 GPIO15 20 GPIO16 21 GPIO17 22 GND 23 GPIO18 24 GPIO19 25 GPIO20 26 GPIO21 27 GND 28 GPIO22 29 RUN 30 GPIO26_ADC0 31 GPIO27_ADC1 32

Pi PICO Analyzer Channel A

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

Pi PICO Analyzer Channel B

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

Pi PICO Analyzer Channel C

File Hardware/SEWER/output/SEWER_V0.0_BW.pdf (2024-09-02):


RcBusInterface File: RcBusInterface.kicad_sch CpuPowerZdi File: ez80_PowerZdi.kicad_sch CpuGpioRtc File: ez80_Gpio.kicad_sch

Simple Eval With EZ80F91 on RCBUS




CPU Address and Data Bus



1 3 B601 BAT-HLD-012-SMT GND GND

CPU GPIO & Real Time Clock

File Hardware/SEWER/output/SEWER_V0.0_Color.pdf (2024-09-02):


RcBusInterface File: RcBusInterface.kicad_sch CpuPowerZdi File: ez80_PowerZdi.kicad_sch CpuGpioRtc File: ez80_Gpio.kicad_sch

Simple Eval With EZ80F91 on RCBUS




CPU Address and Data Bus



1 3 B601 BAT-HLD-012-SMT GND GND

CPU GPIO & Real Time Clock

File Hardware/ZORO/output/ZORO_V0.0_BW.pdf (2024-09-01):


3 NC 30 A18 31 VDD 32 A19 33 GND 34 D0 35 D1 36 D2 37 D3 38 D4 39 ~{INT0} 4 D5 40 D6 41 NC 42 NC 43 D7 44 ~{RTS0}45 ~{CTS0}46 ~{DCD0}47 TXA0 48 RXA0 49 ~{INT1} 5 CKA0/~{DREQ0}50 NC 51 TXA1 52 TEST 53 RXA1 54 CKA1/~{TEND0}55 TXS 56 RXS/~{CTS1}57 CKS 58 ~{DREQ1}59 ~{INT2} 6 ~{TEND1}60 ~{HALT}61 NC 62 NC 63 ~{RFSH}64

7 ~{RD} 70 PHI 71 GND 72 GND 73 XTAL 74 NC 75 EXTAL 76 ~{WAIT} 77 ~{BUSACK} 78 ~{BUSREQ} 79 A0

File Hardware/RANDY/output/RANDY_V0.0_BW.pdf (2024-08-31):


RCBUS Adapter to Nouveau Design. Yeah!

Converts BUS from John Winans Nouveau Project
Id: 1/1 Title: RANDY

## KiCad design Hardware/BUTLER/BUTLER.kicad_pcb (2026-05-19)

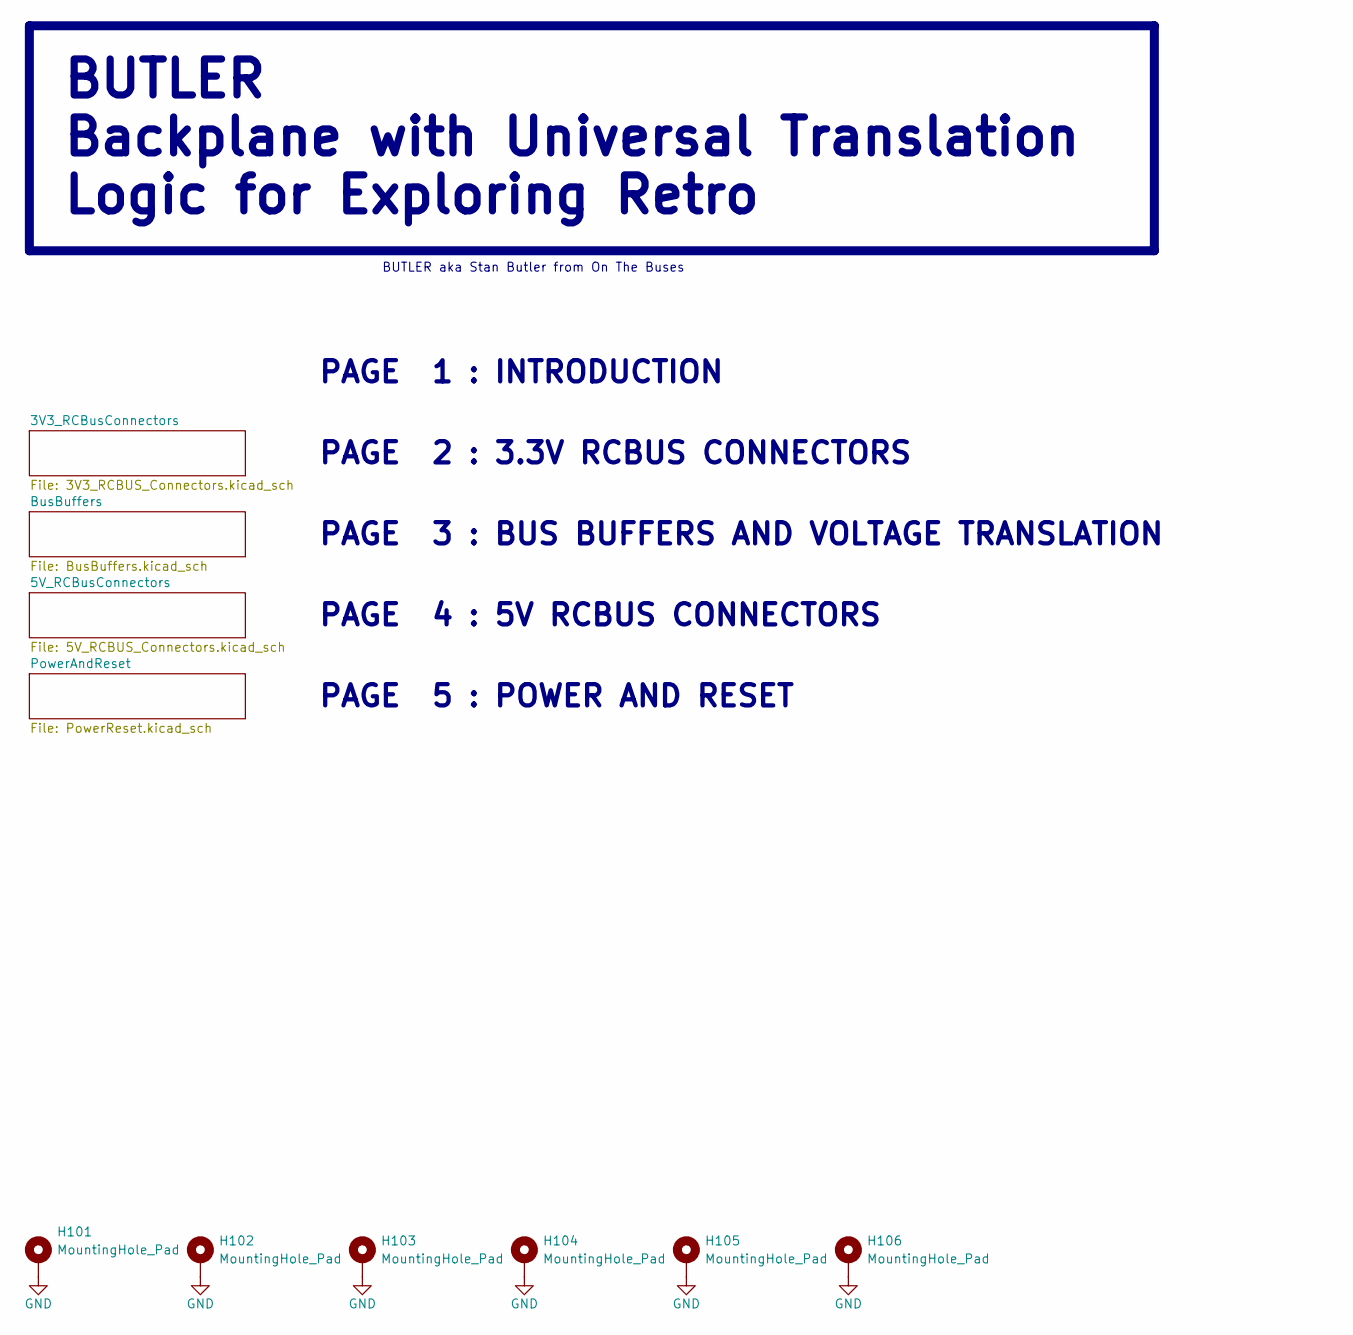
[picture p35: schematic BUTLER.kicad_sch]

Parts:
H101, H102, H103, H104, H105, H106: MountingHole_Pad; MountingHole_3.2mm_M3_DIN965_Pad

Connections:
GND: H101.1, H102.1, H103.1, H104.1, H105.1, H106.1; also elsewhere on the board

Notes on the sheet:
PAGE 5 : POWER AND RESET
PAGE 1 : INTRODUCTION
PAGE 4 : 5V RCBUS CONNECTORS
PAGE 2 : 3.3V RCBUS CONNECTORS
BUTLER aka Stan Butler from On The Buses
PAGE 3 : BUS BUFFERS AND VOLTAGE TRANSLATION
BUTLER Backplane with Universal Translation Logic for Exploring Retro

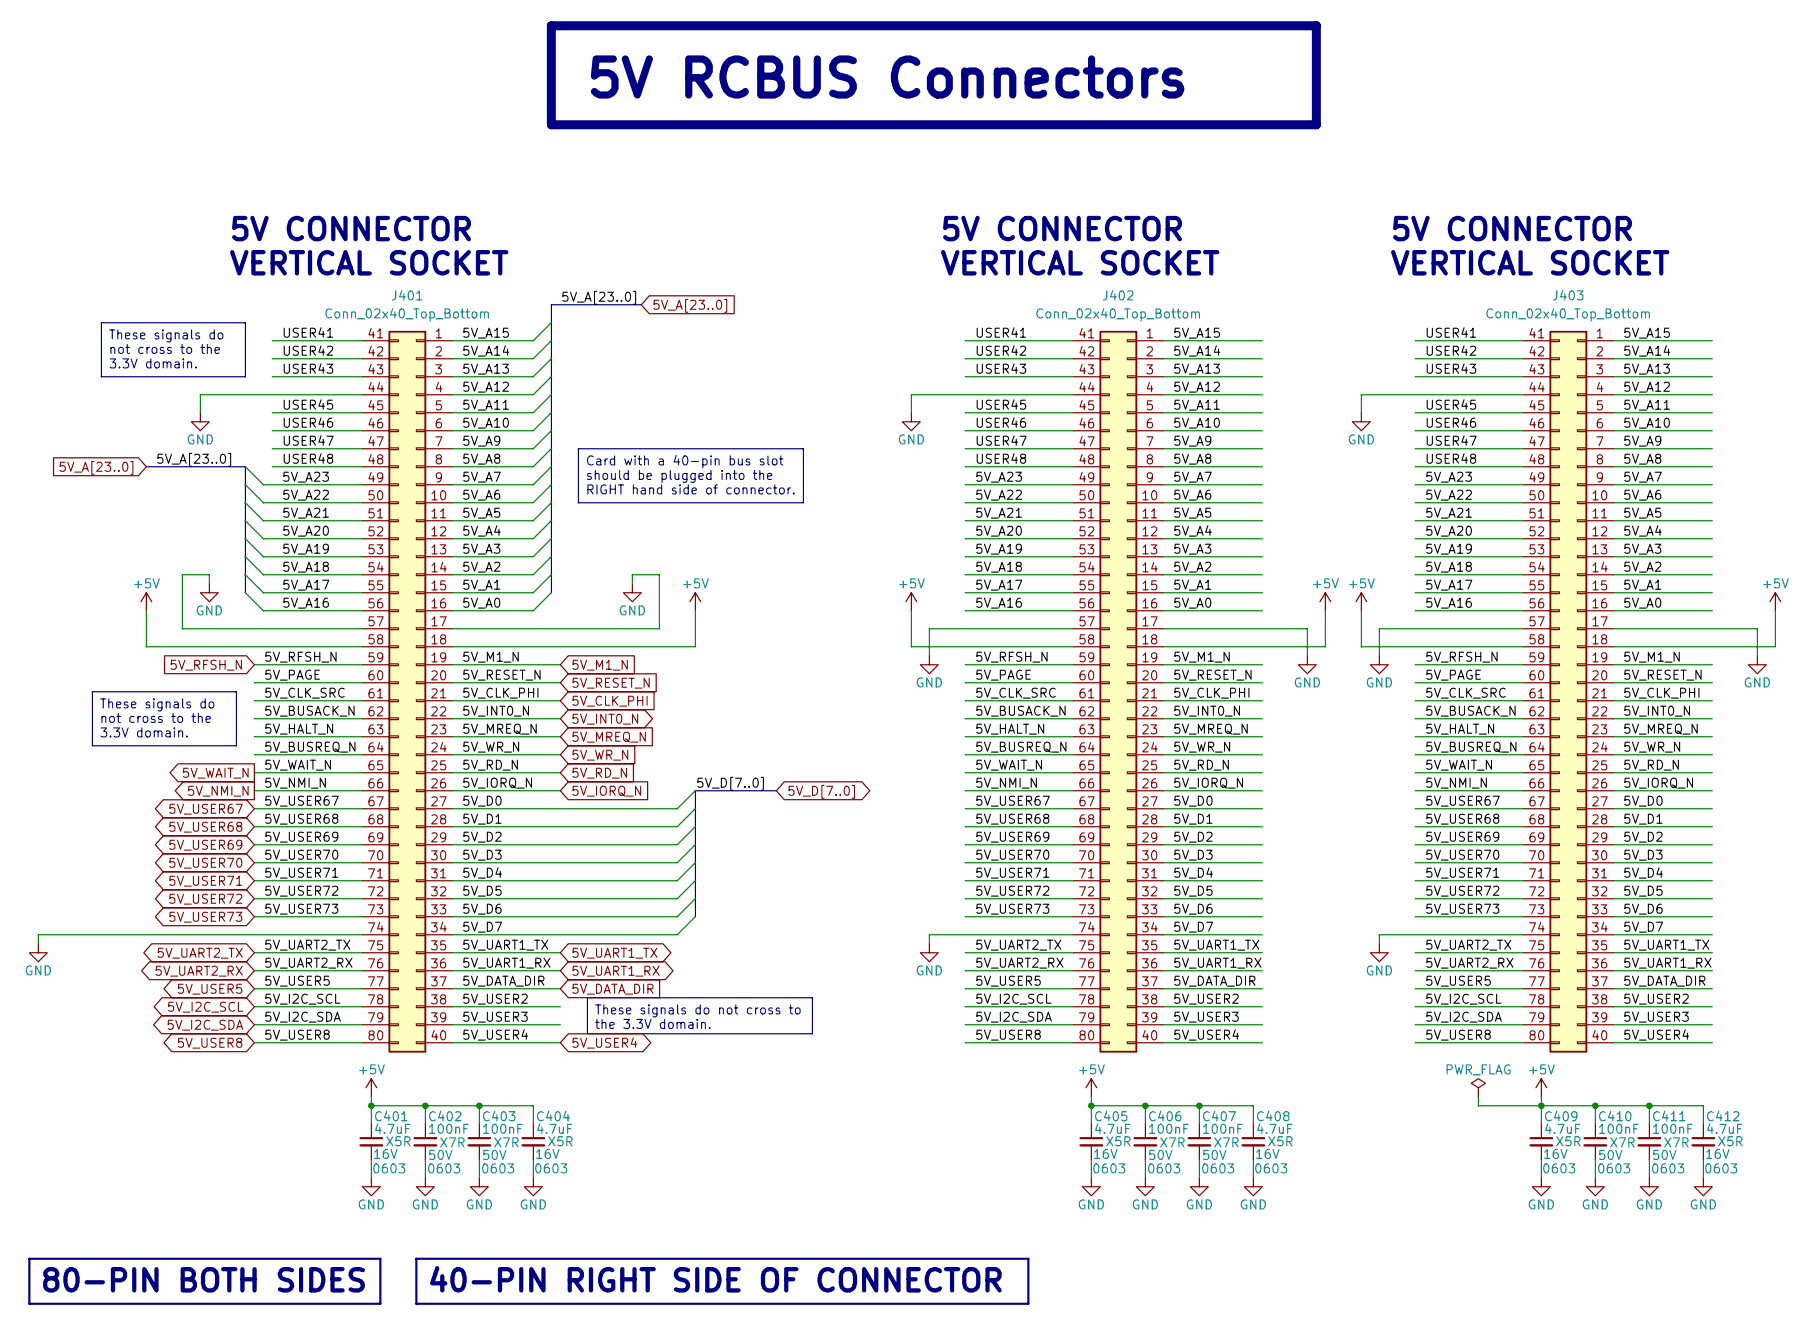
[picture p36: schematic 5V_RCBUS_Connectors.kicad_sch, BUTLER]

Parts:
C401, C404, C405, C408, C409, C412: 4.7uF; C_0603_1608Metric; Voltage 16V; Tolerance 10%; MPN CL10A475KO8NNNC; Digikey 1276-1784-1-ND
C402, C403, C406, C407, C410, C411: 100nF; C_0603_1608Metric; Voltage 50V; Tolerance 10%; MPN CC0603KRX7R9BB104; Digikey 311-1344-1-ND
J401, J402, J403: Conn_02x40_Top_Bottom; PinSocket_2x40_P2.54mm_Vertical_RCBUS80; LCSC Part # C7500806

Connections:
5V_A0: J401.16, J402.16, J403.16; also elsewhere on the board
5V_A1: J401.15, J402.15, J403.15; also elsewhere on the board
5V_A2: J401.14, J402.14, J403.14; also elsewhere on the board
5V_A3: J401.13, J402.13, J403.13; also elsewhere on the board
5V_A4: J401.12, J402.12, J403.12; also elsewhere on the board
5V_A5: J401.11, J402.11, J403.11; also elsewhere on the board
5V_A6: J401.10, J402.10, J403.10; also elsewhere on the board
5V_A7: J401.9, J402.9, J403.9; also elsewhere on the board
5V_A8: J401.8, J402.8, J403.8; also elsewhere on the board
5V_A9: J401.7, J402.7, J403.7; also elsewhere on the board
5V_A10: J401.6, J402.6, J403.6; also elsewhere on the board
5V_A11: J401.5, J402.5, J403.5; also elsewhere on the board
5V_A12: J401.4, J402.4, J403.4; also elsewhere on the board
5V_A13: J401.3, J402.3, J403.3; also elsewhere on the board
5V_A14: J401.2, J402.2, J403.2; also elsewhere on the board
5V_A15: J401.1, J402.1, J403.1; also elsewhere on the board
5V_A16: J401.56, J402.56, J403.56; also elsewhere on the board
5V_A17: J401.55, J402.55, J403.55; also elsewhere on the board
5V_A18: J401.54, J402.54, J403.54; also elsewhere on the board
5V_A19: J401.53, J402.53, J403.53; also elsewhere on the board
5V_A20: J401.52, J402.52, J403.52; also elsewhere on the board
5V_A21: J401.51, J402.51, J403.51; also elsewhere on the board
5V_A22: J401.50, J402.50, J403.50; also elsewhere on the board
5V_A23: J401.49, J402.49, J403.49; also elsewhere on the board
5V_CLK_PHI: J401.21, J402.21, J403.21; also elsewhere on the board
5V_D0: J401.27, J402.27, J403.27; also elsewhere on the board
5V_D1: J401.28, J402.28, J403.28; also elsewhere on the board
5V_D2: J401.29, J402.29, J403.29; also elsewhere on the board
5V_D3: J401.30, J402.30, J403.30; also elsewhere on the board
5V_D4: J401.31, J402.31, J403.31; also elsewhere on the board
5V_D5: J401.32, J402.32, J403.32; also elsewhere on the board
5V_D6: J401.33, J402.33, J403.33; also elsewhere on the board
5V_D7: J401.34, J402.34, J403.34; also elsewhere on the board
5V_DATA_DIR: J401.37, J402.37, J403.37; also elsewhere on the board
5V_I2C_SCL: J401.78, J402.78, J403.78; also elsewhere on the board
5V_I2C_SDA: J401.79, J402.79, J403.79; also elsewhere on the board
5V_INT0_N: J401.22, J402.22, J403.22; also elsewhere on the board
5V_IORQ_N: J401.26, J402.26, J403.26; also elsewhere on the board
5V_M1_N: J401.19, J402.19, J403.19; also elsewhere on the board
5V_MREQ_N: J401.23, J402.23, J403.23; also elsewhere on the board
5V_NMI_N: J401.66, J402.66, J403.66; also elsewhere on the board
5V_RD_N: J401.25, J402.25, J403.25; also elsewhere on the board
5V_RESET_N: J401.20, J402.20, J403.20; also elsewhere on the board
5V_RFSH_N: J401.59, J402.59, J403.59; also elsewhere on the board
5V_UART1_RX: J401.36, J402.36, J403.36; also elsewhere on the board
5V_UART1_TX: J401.35, J402.35, J403.35; also elsewhere on the board
5V_UART2_RX: J401.76, J402.76, J403.76; also elsewhere on the board
5V_UART2_TX: J401.75, J402.75, J403.75; also elsewhere on the board
5V_USER4: J401.40, J402.40, J403.40; also elsewhere on the board
5V_USER5: J401.77, J402.77, J403.77; also elsewhere on the board
5V_USER8: J401.80, J402.80, J403.80; also elsewhere on the board
5V_USER67: J401.67, J402.67, J403.67; also elsewhere on the board
5V_USER68: J401.68, J402.68, J403.68; also elsewhere on the board
5V_USER69: J401.69, J402.69, J403.69; also elsewhere on the board
5V_USER70: J401.70, J402.70, J403.70; also elsewhere on the board
5V_USER71: J401.71, J402.71, J403.71; also elsewhere on the board
5V_USER72: J401.72, J402.72, J403.72; also elsewhere on the board
5V_USER73: J401.73, J402.73, J403.73; also elsewhere on the board
5V_WAIT_N: J401.65, J402.65, J403.65; also elsewhere on the board
5V_WR_N: J401.24, J402.24, J403.24; also elsewhere on the board
+5V: C401.1, C402.1, C403.1, C404.1, C405.1, C406.1, C407.1, C408.1, C409.1, C410.1, C411.1, C412.1, J401.18, J401.58, J402.18, J402.58, J403.18, J403.58; also elsewhere on the board
/5V_RCBusConnectors/5V_BUSACK_N: J401.62, J402.62, J403.62
/5V_RCBusConnectors/5V_BUSREQ_N: J401.64, J402.64, J403.64
/5V_RCBusConnectors/5V_CLK_SRC: J401.61, J402.61, J403.61
/5V_RCBusConnectors/5V_HALT_N: J401.63, J402.63, J403.63
/5V_RCBusConnectors/5V_PAGE: J401.60, J402.60, J403.60
/5V_RCBusConnectors/5V_USER2: J401.38, J402.38, J403.38
/5V_RCBusConnectors/5V_USER3: J401.39, J402.39, J403.39
/5V_RCBusConnectors/USER41: J401.41, J402.41, J403.41
/5V_RCBusConnectors/USER42: J401.42, J402.42, J403.42
/5V_RCBusConnectors/USER43: J401.43, J402.43, J403.43
/5V_RCBusConnectors/USER45: J401.45, J402.45, J403.45
/5V_RCBusConnectors/USER46: J401.46, J402.46, J403.46
/5V_RCBusConnectors/USER47: J401.47, J402.47, J403.47
/5V_RCBusConnectors/USER48: J401.48, J402.48, J403.48
GND: C401.2, C402.2, C403.2, C404.2, C405.2, C406.2, C407.2, C408.2, C409.2, C410.2, C411.2, C412.2, J401.17, J401.44, J401.57, J401.74, J402.17, J402.44, J402.57, J402.74, J403.17, J403.44, J403.57, J403.74; also elsewhere on the board

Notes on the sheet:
80-PIN BOTH SIDES
40-PIN RIGHT SIDE OF CONNECTOR
5V CONNECTOR VERTICAL SOCKET
Card with a 40-pin bus slot should be plugged into the RIGHT hand side of connector.
These signals do not cross to the 3.3V domain.
5V RCBUS Connectors

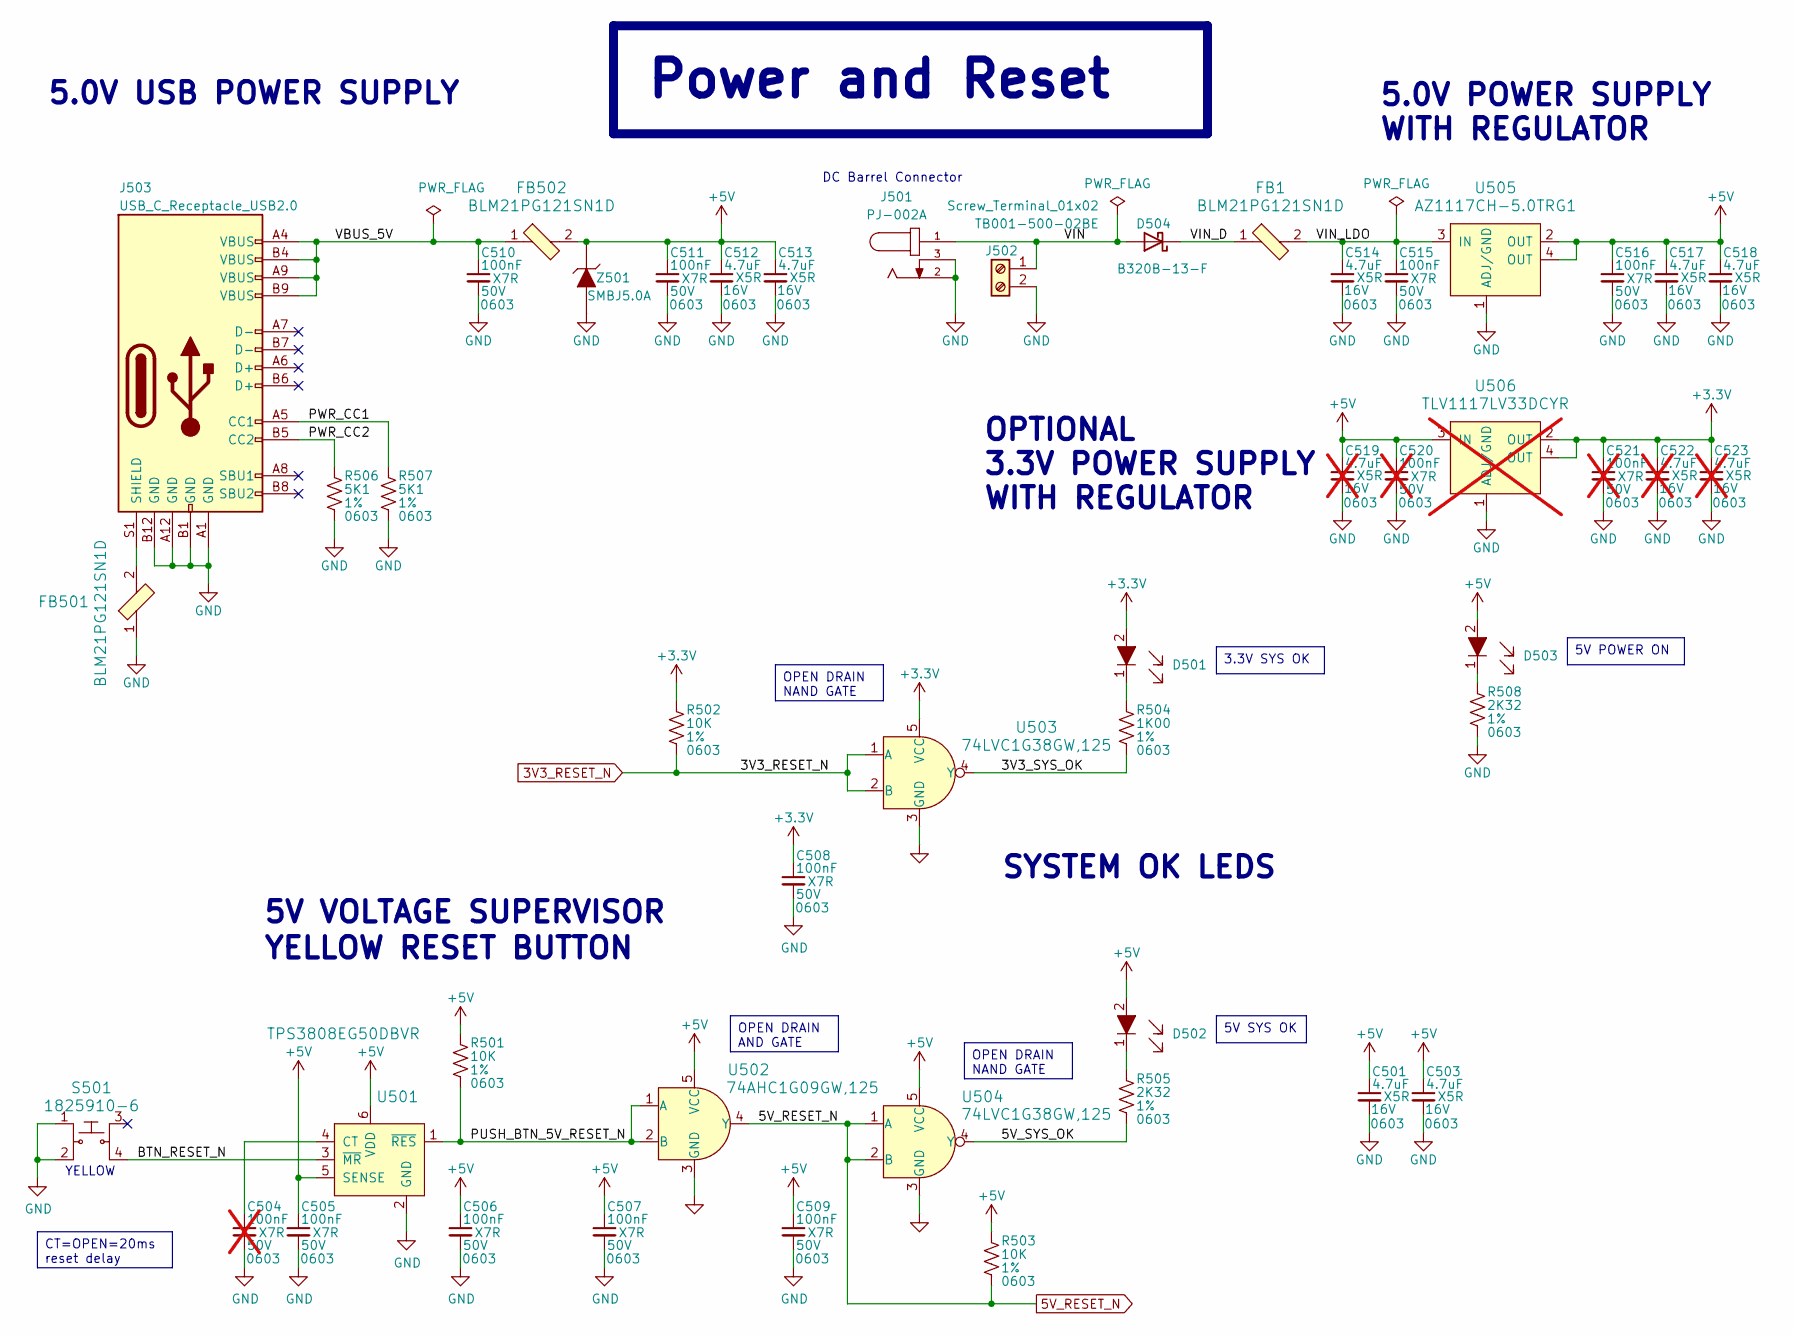
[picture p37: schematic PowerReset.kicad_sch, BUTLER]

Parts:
C501, C503, C512, C513, C514, C517, C518: 4.7uF; C_0603_1608Metric; Voltage 16V; Tolerance 10%; MPN CL10A475KO8NNNC; Digikey 1276-1784-1-ND
C504, C520, C521: 100nF; C_0603_1608Metric; Voltage 50V; Tolerance 10%; MPN CC0603KRX7R9BB104; Digikey 311-1344-1-ND; not fitted
C505, C506, C507, C508, C509, C510, C511, C515, C516: 100nF; C_0603_1608Metric; Voltage 50V; Tolerance 10%; MPN CC0603KRX7R9BB104; Digikey 311-1344-1-ND
C519, C522, C523: 4.7uF; C_0603_1608Metric; Voltage 16V; Tolerance 10%; MPN CL10A475KO8NNNC; Digikey 1276-1784-1-ND; not fitted
D501, D502, D503: LED_LTST-S270KGKT; LTST-S270KGKT; MPN LTST-S270KGKT; Digikey 160-1478-1-ND
D504: B320B-13-F; D_SMB; MPN B320B-13-F; Digikey B320B-FDICT-ND
FB1, FB501, FB502: BLM21PG121SN1D; L_0805_2012Metric; MPN BLM21PG121SN1D; Digikey 490-5986-1-ND
J501: PJ-002A; CUI_PJ-002A; MPN PJ-002A; Digikey CP-002A-ND
J502: Screw_Terminal_01x02; CUI_TB001-500-02BE; MPN TB001-500-02BE; Digikey 102-6134-ND
J503: USB_C_Receptacle_USB2.0; USB_C_Receptacle_HRO_TYPE-C-31-M-12; MPN USB4105-GF-A; LCSC Part # C167321
R501, R502, R503: 10K; R_0603_1608Metric; Tolerance 1%; MPN RC0603FR-0710KL; Digikey 311-10.0KHRCT-ND
R504: 1K00; R_0603_1608Metric; Tolerance 1%; MPN RC0603FR-071KL; Digikey 311-1.00KHRCT-ND
R505, R508: 2K32; R_0603_1608Metric; Tolerance 1%; MPN RC0603FR-072K32L; Digikey 311-2.32KHRCT-ND
R506, R507: 5K1; R_0603_1608Metric; Tolerance 1%; MPN RC0603FR-075K1L; Digikey 311-5.10KHRCT-ND
S501: 1825910-6; Switch_Tactile_THT_6x6mm; MPN 1825910-6; Digi-Key_PN 450-1650-ND
U501: TPS3808EG50DBVR; TSOT-23-6_HandSoldering; MPN TPS3808EG50DBVR; Digikey 296-TPS3808EG50DBVRCT-ND
U502: 74AHC1G09GW,125; SOT-353_SC-70-5; MPN 74AHC1G09GW,125; Digikey 1727-6017-1-ND
U503, U504: 74LVC1G38GW,125; SOT-353_SC-70-5; MPN 74LVC1G38GW,125; Digikey 1727-6077-1-ND
U505: AZ1117CH-5.0TRG1; SOT-223; MPN AZ1117CH-5.0TRG1; Digikey AZ1117CH-5.0TRG1DICT-ND
U506: TLV1117LV33DCYR; SOT-223; MPN TLV1117LV33DCYR; Digikey 296-28778-1-ND; not fitted
Z501: SMBJ5.0A; D_SMB; MPN SMBJ5.0A; Digikey SMBJ5.0ALFCT-ND

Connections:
3V3_RESET_N: R502.2, U503.1 (A), U503.2 (B); also elsewhere on the board
5V_RESET_N: R503.2, U502.4 (Y), U504.1 (A), U504.2 (B); also elsewhere on the board
+3.3V: C508.1, C521.1, C522.1, C523.1, D501.2, R502.1, U503.5 (VCC), U506.2 (OUT), U506.4 (OUT); also elsewhere on the board
+5V: C501.1, C503.1, C505.1, C506.1, C507.1, C509.1, C511.1, C512.1, C513.1, C516.1, C517.1, C518.1, C519.1, C520.1, D502.2, D503.2, FB502.2, R501.1, R503.1, U501.5 (SENSE), U501.6 (VDD), U502.5 (VCC), U504.5 (VCC), U505.2 (OUT), U505.4 (OUT), U506.3 (IN), Z501.1; also elsewhere on the board
/PowerAndReset/3V3_SYS_OK: R504.2, U503.4 (Y)
/PowerAndReset/5V_SYS_OK: R505.2, U504.4 (Y)
/PowerAndReset/BTN_RESET_N: S501.4, U501.3 (~MR)
/PowerAndReset/PUSH_BTN_5V_RESET_N: R501.2, U501.1 (~RES), U502.1 (A), U502.2 (B)
/PowerAndReset/PWR_CC1: J503.A5 (CC1), R507.1
/PowerAndReset/PWR_CC2: J503.B5 (CC2), R506.1
/PowerAndReset/VBUS_5V: C510.1, FB502.1, J503.A4 (VBUS), J503.A9 (VBUS), J503.B4 (VBUS), J503.B9 (VBUS)
/PowerAndReset/VIN: D504.2 (A), J501.1, J502.1
/PowerAndReset/VIN_D: D504.1 (K), FB1.1
/PowerAndReset/VIN_LDO: C514.1, C515.1, FB1.2, U505.3 (IN)
GND: C501.2, C503.2, C504.2, C505.2, C506.2, C507.2, C508.2, C509.2, C510.2, C511.2, C512.2, C513.2, C514.2, C515.2, C516.2, C517.2, C518.2, C519.2, C520.2, C521.2, C522.2, C523.2, FB501.1, J501.2, J501.3, J502.2, J503.A1 (GND), J503.A12 (GND), J503.B1 (GND), J503.B12 (GND), R506.2, R507.2, R508.2, S501.1, S501.2, U501.2 (GND), U502.3 (GND), U503.3 (GND), U504.3 (GND), U505.1 (ADJ/GND), U506.1 (ADJ/GND), Z501.2; also elsewhere on the board
unnamed: D501.1, R504.1
unnamed: D502.1, R505.1
unnamed: D503.1, R508.1
unnamed: FB501.2, J503.S1 (SHIELD)
unnamed: C504.1, U501.4 (CT)

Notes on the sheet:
5.0V USB POWER SUPPLY
OPTIONAL 3.3V POWER SUPPLY WITH REGULATOR
YELLOW RESET BUTTON
SYSTEM OK LEDS
5.0V POWER SUPPLY WITH REGULATOR
DC Barrel Connector
5V VOLTAGE SUPERVISOR
YELLOW
3.3V SYS OK
OPEN DRAIN NAND GATE
5V POWER ON
CT=OPEN=20ms reset delay
OPEN DRAIN AND GATE
5V SYS OK
Power and Reset

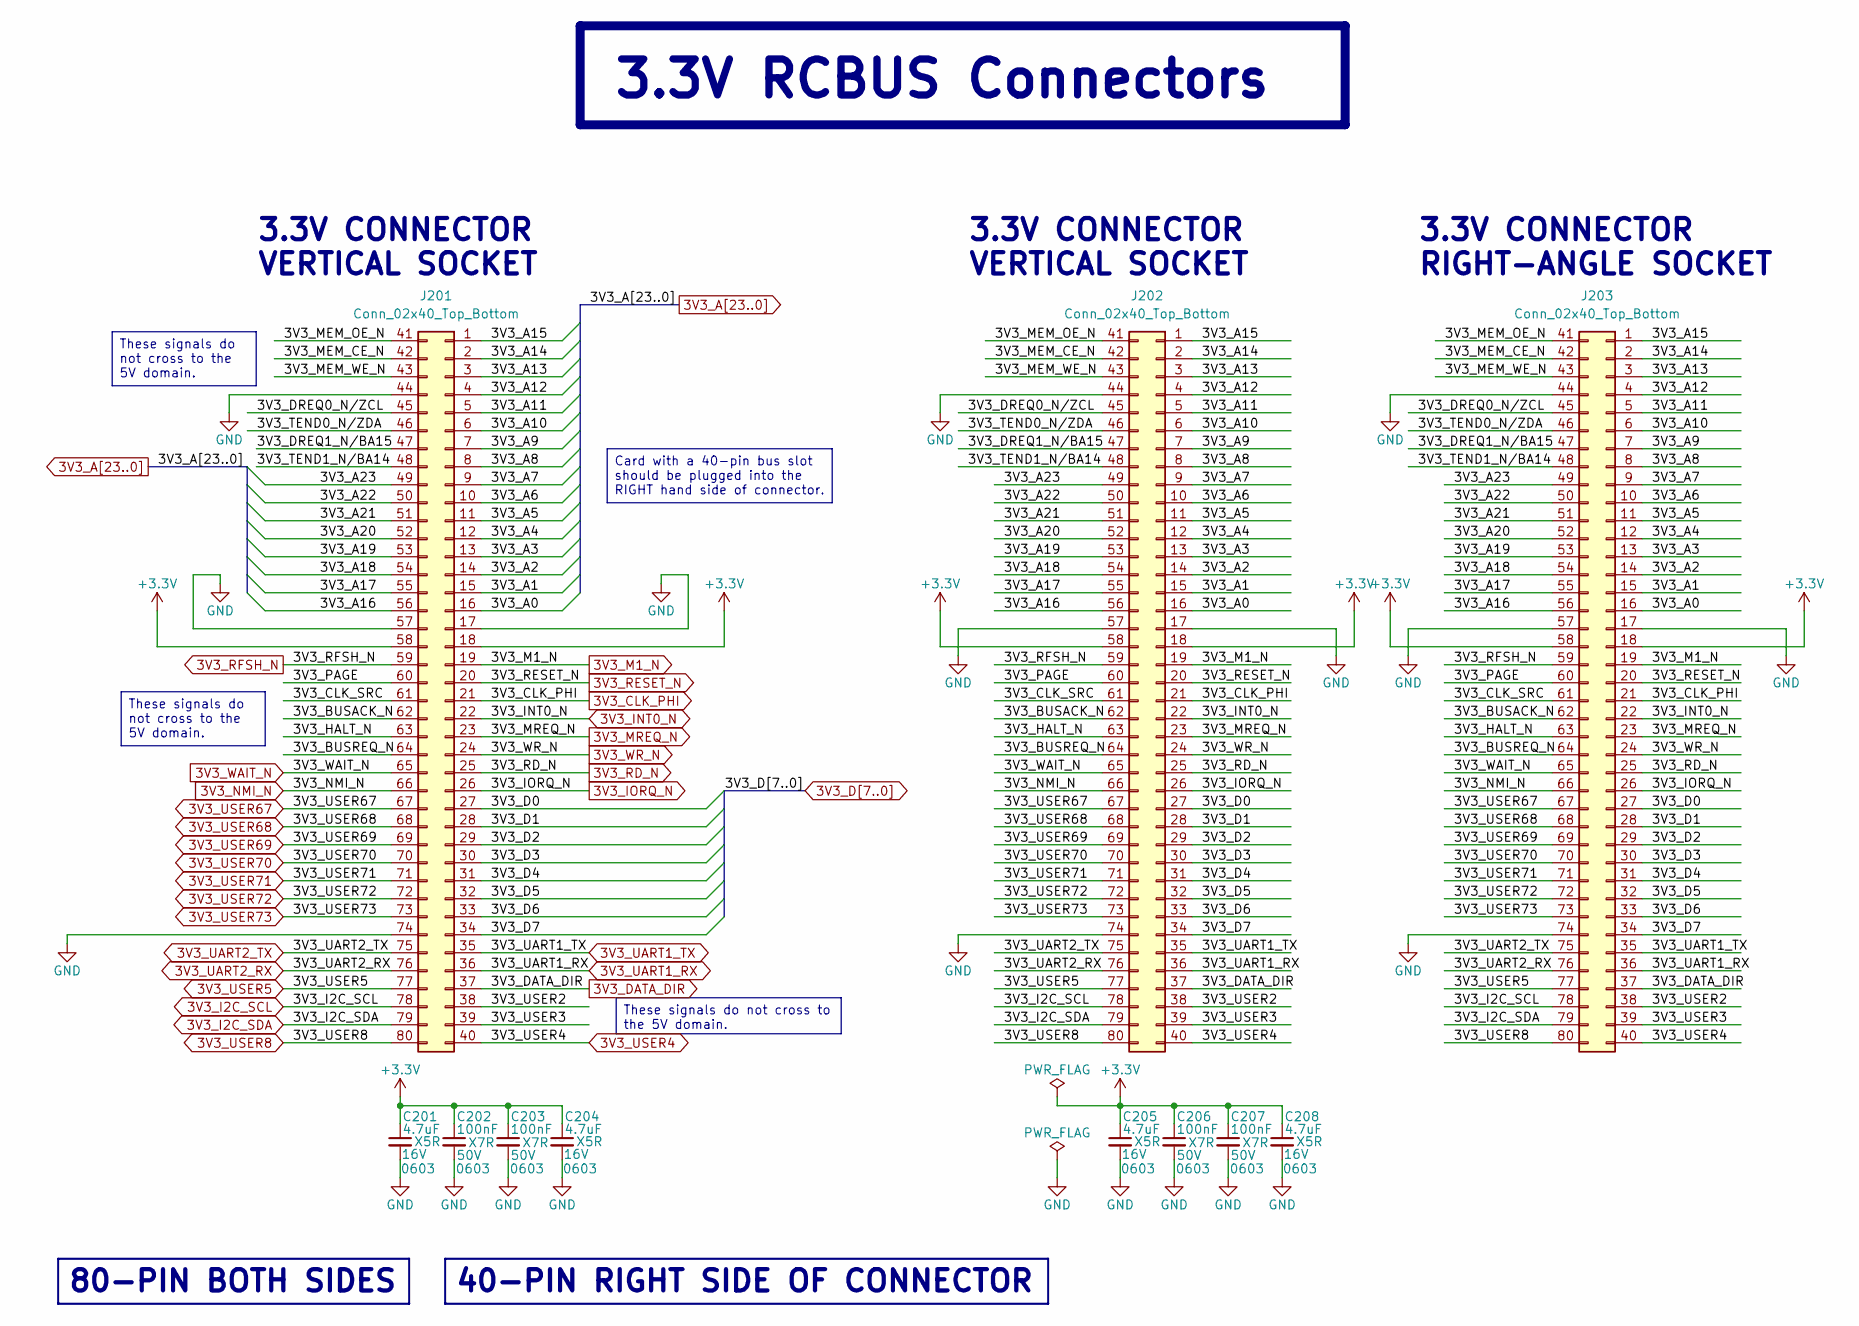
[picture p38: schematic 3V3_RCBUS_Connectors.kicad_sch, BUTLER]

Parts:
C201, C204, C205, C208: 4.7uF; C_0603_1608Metric; Voltage 16V; Tolerance 10%; MPN CL10A475KO8NNNC; Digikey 1276-1784-1-ND
C202, C203, C206, C207: 100nF; C_0603_1608Metric; Voltage 50V; Tolerance 10%; MPN CC0603KRX7R9BB104; Digikey 311-1344-1-ND
J201, J202: Conn_02x40_Top_Bottom; PinSocket_2x40_P2.54mm_Vertical_RCBUS80; LCSC Part # C7500806
J203: Conn_02x40_Top_Bottom; PinSocket_2x40_P2.54mm_Horizontal_RCBUS80; MPN SSW-140-02-T-D-RA; Digikey 612-SSW-140-02-T-D-RA-ND

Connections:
3V3_A0: J201.16, J202.16, J203.16; also elsewhere on the board
3V3_A1: J201.15, J202.15, J203.15; also elsewhere on the board
3V3_A2: J201.14, J202.14, J203.14; also elsewhere on the board
3V3_A3: J201.13, J202.13, J203.13; also elsewhere on the board
3V3_A4: J201.12, J202.12, J203.12; also elsewhere on the board
3V3_A5: J201.11, J202.11, J203.11; also elsewhere on the board
3V3_A6: J201.10, J202.10, J203.10; also elsewhere on the board
3V3_A7: J201.9, J202.9, J203.9; also elsewhere on the board
3V3_A8: J201.8, J202.8, J203.8; also elsewhere on the board
3V3_A9: J201.7, J202.7, J203.7; also elsewhere on the board
3V3_A10: J201.6, J202.6, J203.6; also elsewhere on the board
3V3_A11: J201.5, J202.5, J203.5; also elsewhere on the board
3V3_A12: J201.4, J202.4, J203.4; also elsewhere on the board
3V3_A13: J201.3, J202.3, J203.3; also elsewhere on the board
3V3_A14: J201.2, J202.2, J203.2; also elsewhere on the board
3V3_A15: J201.1, J202.1, J203.1; also elsewhere on the board
3V3_A16: J201.56, J202.56, J203.56; also elsewhere on the board
3V3_A17: J201.55, J202.55, J203.55; also elsewhere on the board
3V3_A18: J201.54, J202.54, J203.54; also elsewhere on the board
3V3_A19: J201.53, J202.53, J203.53; also elsewhere on the board
3V3_A20: J201.52, J202.52, J203.52; also elsewhere on the board
3V3_A21: J201.51, J202.51, J203.51; also elsewhere on the board
3V3_A22: J201.50, J202.50, J203.50; also elsewhere on the board
3V3_A23: J201.49, J202.49, J203.49; also elsewhere on the board
3V3_CLK_PHI: J201.21, J202.21, J203.21; also elsewhere on the board
3V3_D0: J201.27, J202.27, J203.27; also elsewhere on the board
3V3_D1: J201.28, J202.28, J203.28; also elsewhere on the board
3V3_D2: J201.29, J202.29, J203.29; also elsewhere on the board
3V3_D3: J201.30, J202.30, J203.30; also elsewhere on the board
3V3_D4: J201.31, J202.31, J203.31; also elsewhere on the board
3V3_D5: J201.32, J202.32, J203.32; also elsewhere on the board
3V3_D6: J201.33, J202.33, J203.33; also elsewhere on the board
3V3_D7: J201.34, J202.34, J203.34; also elsewhere on the board
3V3_DATA_DIR: J201.37, J202.37, J203.37; also elsewhere on the board
3V3_I2C_SCL: J201.78, J202.78, J203.78; also elsewhere on the board
3V3_I2C_SDA: J201.79, J202.79, J203.79; also elsewhere on the board
3V3_INT0_N: J201.22, J202.22, J203.22; also elsewhere on the board
3V3_IORQ_N: J201.26, J202.26, J203.26; also elsewhere on the board
3V3_M1_N: J201.19, J202.19, J203.19; also elsewhere on the board
3V3_MREQ_N: J201.23, J202.23, J203.23; also elsewhere on the board
3V3_NMI_N: J201.66, J202.66, J203.66; also elsewhere on the board
3V3_RD_N: J201.25, J202.25, J203.25; also elsewhere on the board
3V3_RESET_N: J201.20, J202.20, J203.20; also elsewhere on the board
3V3_RFSH_N: J201.59, J202.59, J203.59; also elsewhere on the board
3V3_UART1_RX: J201.36, J202.36, J203.36; also elsewhere on the board
3V3_UART1_TX: J201.35, J202.35, J203.35; also elsewhere on the board
3V3_UART2_RX: J201.76, J202.76, J203.76; also elsewhere on the board
3V3_UART2_TX: J201.75, J202.75, J203.75; also elsewhere on the board
3V3_USER4: J201.40, J202.40, J203.40; also elsewhere on the board
3V3_USER5: J201.77, J202.77, J203.77; also elsewhere on the board
3V3_USER8: J201.80, J202.80, J203.80; also elsewhere on the board
3V3_USER67: J201.67, J202.67, J203.67; also elsewhere on the board
3V3_USER68: J201.68, J202.68, J203.68; also elsewhere on the board
3V3_USER69: J201.69, J202.69, J203.69; also elsewhere on the board
3V3_USER70: J201.70, J202.70, J203.70; also elsewhere on the board
3V3_USER71: J201.71, J202.71, J203.71; also elsewhere on the board
3V3_USER72: J201.72, J202.72, J203.72; also elsewhere on the board
3V3_USER73: J201.73, J202.73, J203.73; also elsewhere on the board
3V3_WAIT_N: J201.65, J202.65, J203.65; also elsewhere on the board
3V3_WR_N: J201.24, J202.24, J203.24; also elsewhere on the board
+3.3V: C201.1, C202.1, C203.1, C204.1, C205.1, C206.1, C207.1, C208.1, J201.18, J201.58, J202.18, J202.58, J203.18, J203.58; also elsewhere on the board
/3V3_RCBusConnectors/3V3_BUSACK_N: J201.62, J202.62, J203.62
/3V3_RCBusConnectors/3V3_BUSREQ_N: J201.64, J202.64, J203.64
/3V3_RCBusConnectors/3V3_CLK_SRC: J201.61, J202.61, J203.61
/3V3_RCBusConnectors/3V3_DREQ0_N/ZCL: J201.45, J202.45, J203.45
/3V3_RCBusConnectors/3V3_DREQ1_N/BA15: J201.47, J202.47, J203.47
/3V3_RCBusConnectors/3V3_HALT_N: J201.63, J202.63, J203.63
/3V3_RCBusConnectors/3V3_MEM_CE_N: J201.42, J202.42, J203.42
/3V3_RCBusConnectors/3V3_MEM_OE_N: J201.41, J202.41, J203.41
/3V3_RCBusConnectors/3V3_MEM_WE_N: J201.43, J202.43, J203.43
/3V3_RCBusConnectors/3V3_PAGE: J201.60, J202.60, J203.60
/3V3_RCBusConnectors/3V3_TEND0_N/ZDA: J201.46, J202.46, J203.46
/3V3_RCBusConnectors/3V3_TEND1_N/BA14: J201.48, J202.48, J203.48
/3V3_RCBusConnectors/3V3_USER2: J201.38, J202.38, J203.38
/3V3_RCBusConnectors/3V3_USER3: J201.39, J202.39, J203.39
GND: C201.2, C202.2, C203.2, C204.2, C205.2, C206.2, C207.2, C208.2, J201.17, J201.44, J201.57, J201.74, J202.17, J202.44, J202.57, J202.74, J203.17, J203.44, J203.57, J203.74; also elsewhere on the board

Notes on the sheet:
80-PIN BOTH SIDES
40-PIN RIGHT SIDE OF CONNECTOR
3.3V CONNECTOR RIGHT-ANGLE SOCKET
3.3V CONNECTOR VERTICAL SOCKET
Card with a 40-pin bus slot should be plugged into the RIGHT hand side of connector.
These signals do not cross to the 5V domain.
3.3V RCBUS Connectors

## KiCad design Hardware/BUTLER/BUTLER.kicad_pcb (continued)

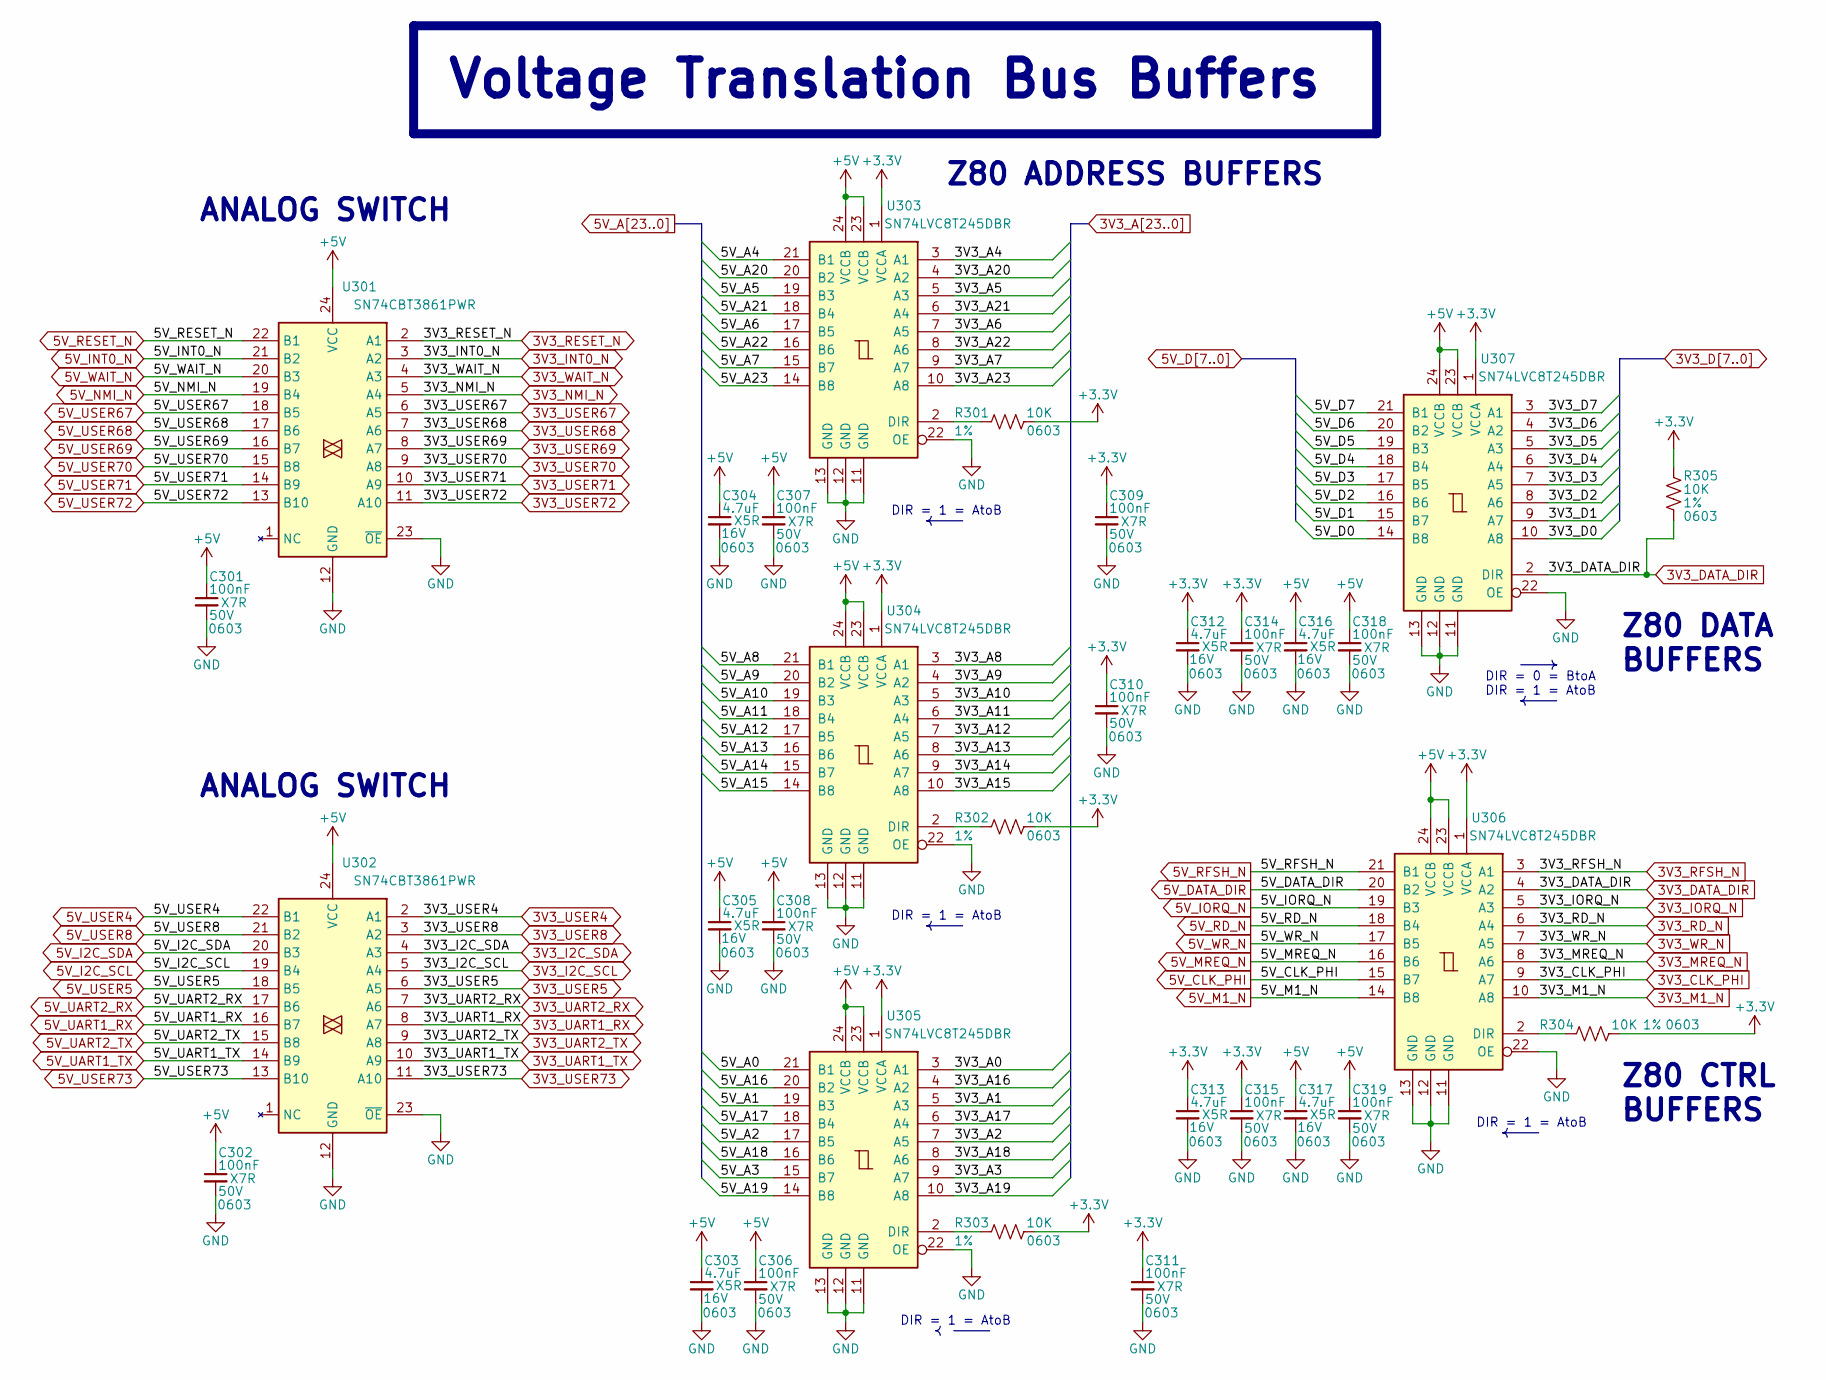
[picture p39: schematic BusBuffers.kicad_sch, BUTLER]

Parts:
C301, C302, C306, C307, C308, C309, C310, C311, C314, C315, C318, C319: 100nF; C_0603_1608Metric; Voltage 50V; Tolerance 10%; MPN CC0603KRX7R9BB104; Digikey 311-1344-1-ND
C303, C304, C305, C312, C313, C316, C317: 4.7uF; C_0603_1608Metric; Voltage 16V; Tolerance 10%; MPN CL10A475KO8NNNC; Digikey 1276-1784-1-ND
R301, R302, R303, R304, R305: 10K; R_0603_1608Metric; Tolerance 1%; MPN RC0603FR-0710KL; Digikey 311-10.0KHRCT-ND
U301, U302: SN74CBT3861PWR; TSSOP-24_4.4x7.8mm_P0.65mm; MPN SN74CBTD3861DBQR; Digikey 296-6483-1-ND
U303, U304, U305, U306, U307: SN74LVC8T245DBR; SSOP-24_5.3x8.2mm_P0.65mm; MPN SN74LVC8T245DBR; Digikey 296-21065-1-ND

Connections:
3V3_A0: U305.3 (A1); also elsewhere on the board
3V3_A1: U305.5 (A3); also elsewhere on the board
3V3_A2: U305.7 (A5); also elsewhere on the board
3V3_A3: U305.9 (A7); also elsewhere on the board
3V3_A4: U303.3 (A1); also elsewhere on the board
3V3_A5: U303.5 (A3); also elsewhere on the board
3V3_A6: U303.7 (A5); also elsewhere on the board
3V3_A7: U303.9 (A7); also elsewhere on the board
3V3_A8: U304.3 (A1); also elsewhere on the board
3V3_A9: U304.4 (A2); also elsewhere on the board
3V3_A10: U304.5 (A3); also elsewhere on the board
3V3_A11: U304.6 (A4); also elsewhere on the board
3V3_A12: U304.7 (A5); also elsewhere on the board
3V3_A13: U304.8 (A6); also elsewhere on the board
3V3_A14: U304.9 (A7); also elsewhere on the board
3V3_A15: U304.10 (A8); also elsewhere on the board
3V3_A16: U305.4 (A2); also elsewhere on the board
3V3_A17: U305.6 (A4); also elsewhere on the board
3V3_A18: U305.8 (A6); also elsewhere on the board
3V3_A19: U305.10 (A8); also elsewhere on the board
3V3_A20: U303.4 (A2); also elsewhere on the board
3V3_A21: U303.6 (A4); also elsewhere on the board
3V3_A22: U303.8 (A6); also elsewhere on the board
3V3_A23: U303.10 (A8); also elsewhere on the board
3V3_CLK_PHI: U306.9 (A7); also elsewhere on the board
3V3_D0: U307.10 (A8); also elsewhere on the board
3V3_D1: U307.9 (A7); also elsewhere on the board
3V3_D2: U307.8 (A6); also elsewhere on the board
3V3_D3: U307.7 (A5); also elsewhere on the board
3V3_D4: U307.6 (A4); also elsewhere on the board
3V3_D5: U307.5 (A3); also elsewhere on the board
3V3_D6: U307.4 (A2); also elsewhere on the board
3V3_D7: U307.3 (A1); also elsewhere on the board
3V3_DATA_DIR: R305.2, U306.4 (A2), U307.2 (DIR); also elsewhere on the board
3V3_I2C_SCL: U302.5 (A4); also elsewhere on the board
3V3_I2C_SDA: U302.4 (A3); also elsewhere on the board
3V3_INT0_N: U301.3 (A2); also elsewhere on the board
3V3_IORQ_N: U306.5 (A3); also elsewhere on the board
3V3_M1_N: U306.10 (A8); also elsewhere on the board
3V3_MREQ_N: U306.8 (A6); also elsewhere on the board
3V3_NMI_N: U301.5 (A4); also elsewhere on the board
3V3_RD_N: U306.6 (A4); also elsewhere on the board
3V3_RESET_N: U301.2 (A1); also elsewhere on the board
3V3_RFSH_N: U306.3 (A1); also elsewhere on the board
3V3_UART1_RX: U302.8 (A7); also elsewhere on the board
3V3_UART1_TX: U302.10 (A9); also elsewhere on the board
3V3_UART2_RX: U302.7 (A6); also elsewhere on the board
3V3_UART2_TX: U302.9 (A8); also elsewhere on the board
3V3_USER4: U302.2 (A1); also elsewhere on the board
3V3_USER5: U302.6 (A5); also elsewhere on the board
3V3_USER8: U302.3 (A2); also elsewhere on the board
3V3_USER67: U301.6 (A5); also elsewhere on the board
3V3_USER68: U301.7 (A6); also elsewhere on the board
3V3_USER69: U301.8 (A7); also elsewhere on the board
3V3_USER70: U301.9 (A8); also elsewhere on the board
3V3_USER71: U301.10 (A9); also elsewhere on the board
3V3_USER72: U301.11 (A10); also elsewhere on the board
3V3_USER73: U302.11 (A10); also elsewhere on the board
3V3_WAIT_N: U301.4 (A3); also elsewhere on the board
3V3_WR_N: U306.7 (A5); also elsewhere on the board
5V_A0: U305.21 (B1); also elsewhere on the board
5V_A1: U305.19 (B3); also elsewhere on the board
5V_A2: U305.17 (B5); also elsewhere on the board
5V_A3: U305.15 (B7); also elsewhere on the board
5V_A4: U303.21 (B1); also elsewhere on the board
5V_A5: U303.19 (B3); also elsewhere on the board
5V_A6: U303.17 (B5); also elsewhere on the board
5V_A7: U303.15 (B7); also elsewhere on the board
5V_A8: U304.21 (B1); also elsewhere on the board
5V_A9: U304.20 (B2); also elsewhere on the board
5V_A10: U304.19 (B3); also elsewhere on the board
5V_A11: U304.18 (B4); also elsewhere on the board
5V_A12: U304.17 (B5); also elsewhere on the board
5V_A13: U304.16 (B6); also elsewhere on the board
5V_A14: U304.15 (B7); also elsewhere on the board
5V_A15: U304.14 (B8); also elsewhere on the board
5V_A16: U305.20 (B2); also elsewhere on the board
5V_A17: U305.18 (B4); also elsewhere on the board
5V_A18: U305.16 (B6); also elsewhere on the board
5V_A19: U305.14 (B8); also elsewhere on the board
5V_A20: U303.20 (B2); also elsewhere on the board
5V_A21: U303.18 (B4); also elsewhere on the board
5V_A22: U303.16 (B6); also elsewhere on the board
5V_A23: U303.14 (B8); also elsewhere on the board
5V_CLK_PHI: U306.15 (B7); also elsewhere on the board
5V_D0: U307.14 (B8); also elsewhere on the board
5V_D1: U307.15 (B7); also elsewhere on the board
5V_D2: U307.16 (B6); also elsewhere on the board
5V_D3: U307.17 (B5); also elsewhere on the board
5V_D4: U307.18 (B4); also elsewhere on the board
5V_D5: U307.19 (B3); also elsewhere on the board
5V_D6: U307.20 (B2); also elsewhere on the board
5V_D7: U307.21 (B1); also elsewhere on the board
5V_DATA_DIR: U306.20 (B2); also elsewhere on the board
5V_I2C_SCL: U302.19 (B4); also elsewhere on the board
5V_I2C_SDA: U302.20 (B3); also elsewhere on the board
5V_INT0_N: U301.21 (B2); also elsewhere on the board
5V_IORQ_N: U306.19 (B3); also elsewhere on the board
5V_M1_N: U306.14 (B8); also elsewhere on the board
5V_MREQ_N: U306.16 (B6); also elsewhere on the board
5V_NMI_N: U301.19 (B4); also elsewhere on the board
5V_RD_N: U306.18 (B4); also elsewhere on the board
5V_RESET_N: U301.22 (B1); also elsewhere on the board
5V_RFSH_N: U306.21 (B1); also elsewhere on the board
5V_UART1_RX: U302.16 (B7); also elsewhere on the board
5V_UART1_TX: U302.14 (B9); also elsewhere on the board
5V_UART2_RX: U302.17 (B6); also elsewhere on the board
5V_UART2_TX: U302.15 (B8); also elsewhere on the board
5V_USER4: U302.22 (B1); also elsewhere on the board
5V_USER5: U302.18 (B5); also elsewhere on the board
5V_USER8: U302.21 (B2); also elsewhere on the board
5V_USER67: U301.18 (B5); also elsewhere on the board
5V_USER68: U301.17 (B6); also elsewhere on the board
5V_USER69: U301.16 (B7); also elsewhere on the board
5V_USER70: U301.15 (B8); also elsewhere on the board
5V_USER71: U301.14 (B9); also elsewhere on the board
5V_USER72: U301.13 (B10); also elsewhere on the board
5V_USER73: U302.13 (B10); also elsewhere on the board
5V_WAIT_N: U301.20 (B3); also elsewhere on the board
5V_WR_N: U306.17 (B5); also elsewhere on the board
+3.3V: C309.1, C310.1, C311.1, C312.1, C313.1, C314.1, C315.1, R301.2, R302.2, R303.2, R304.2, R305.1, U303.1 (VCCA), U304.1 (VCCA), U305.1 (VCCA), U306.1 (VCCA), U307.1 (VCCA); also elsewhere on the board
+5V: C301.1, C302.1, C303.1, C304.1, C305.1, C306.1, C307.1, C308.1, C316.1, C317.1, C318.1, C319.1, U301.24 (VCC), U302.24 (VCC), U303.23 (VCCB), U303.24 (VCCB), U304.23 (VCCB), U304.24 (VCCB), U305.23 (VCCB), U305.24 (VCCB), U306.23 (VCCB), U306.24 (VCCB), U307.23 (VCCB), U307.24 (VCCB); also elsewhere on the board
GND: C301.2, C302.2, C303.2, C304.2, C305.2, C306.2, C307.2, C308.2, C309.2, C310.2, C311.2, C312.2, C313.2, C314.2, C315.2, C316.2, C317.2, C318.2, C319.2, U301.12 (GND), U301.23 (~OE), U302.12 (GND), U302.23 (~OE), U303.11 (GND), U303.12 (GND), U303.13 (GND), U303.22 (OE), U304.11 (GND), U304.12 (GND), U304.13 (GND), U304.22 (OE), U305.11 (GND), U305.12 (GND), U305.13 (GND), U305.22 (OE), U306.11 (GND), U306.12 (GND), U306.13 (GND), U306.22 (OE), U307.11 (GND), U307.12 (GND), U307.13 (GND), U307.22 (OE); also elsewhere on the board
unnamed: R301.1, U303.2 (DIR)
unnamed: R302.1, U304.2 (DIR)
unnamed: R303.1, U305.2 (DIR)
unnamed: R304.1, U306.2 (DIR)

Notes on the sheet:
DIR = 1 = AtoB
DIR = 0 = BtoA
Z80 DATA BUFFERS
ANALOG SWITCH
Z80 ADDRESS BUFFERS
Z80 CTRL BUFFERS
Voltage Translation Bus Buffers

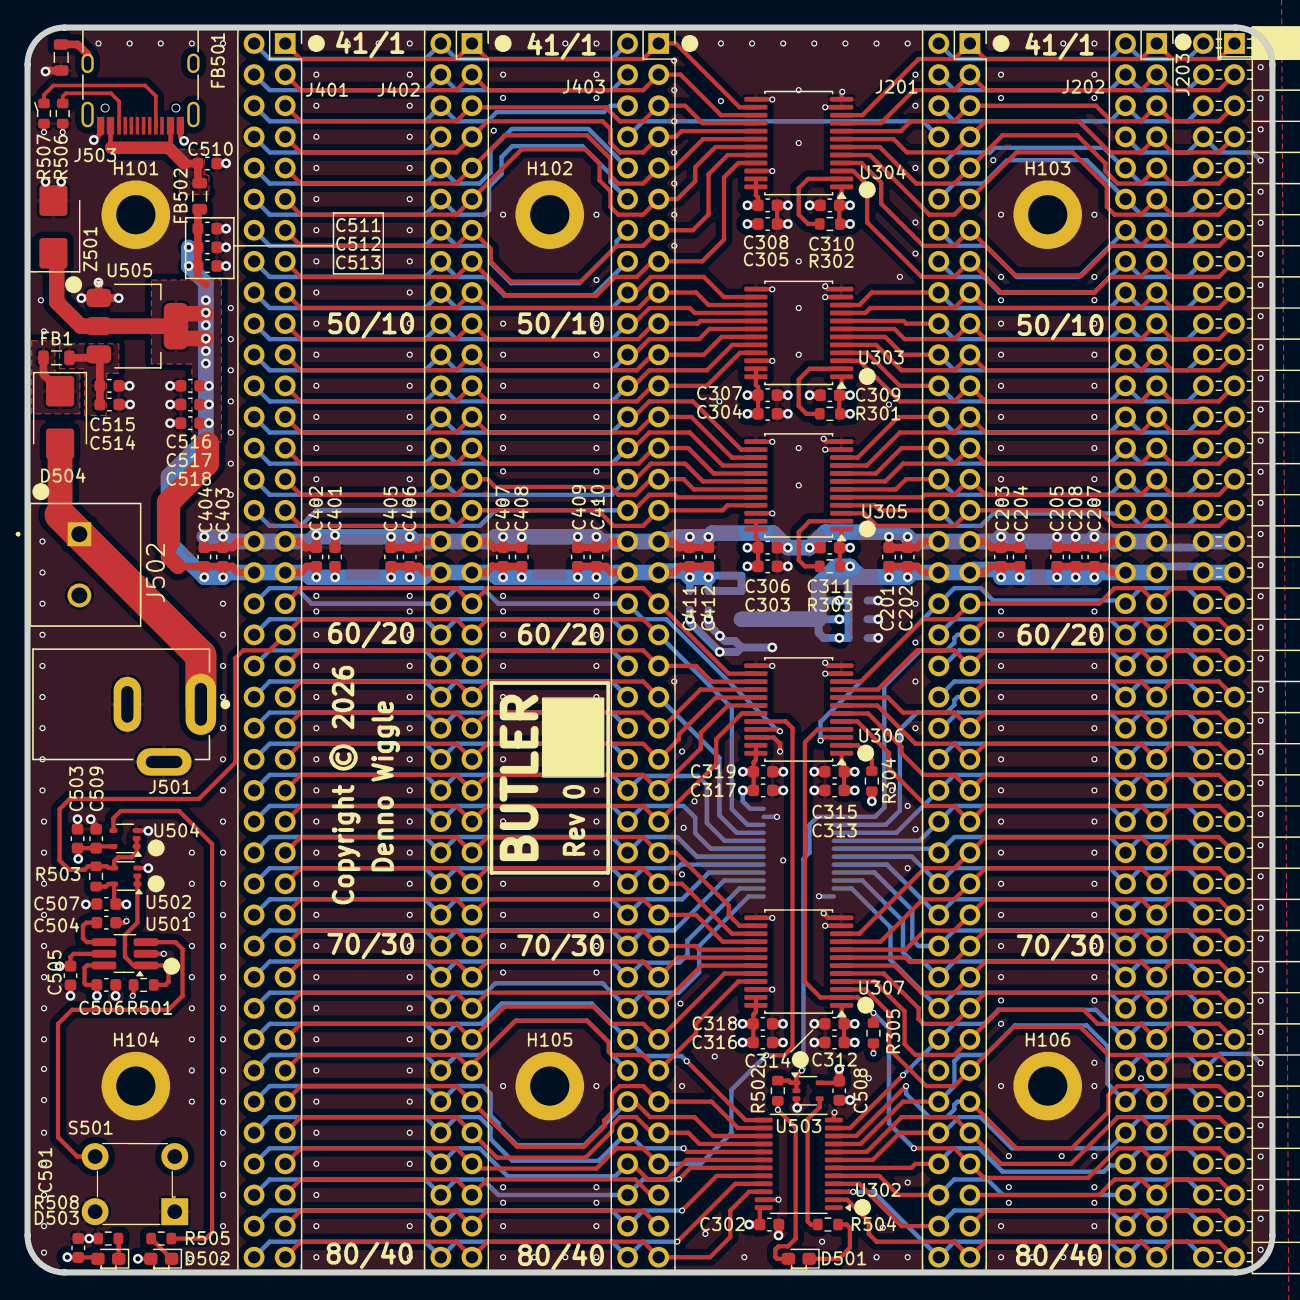
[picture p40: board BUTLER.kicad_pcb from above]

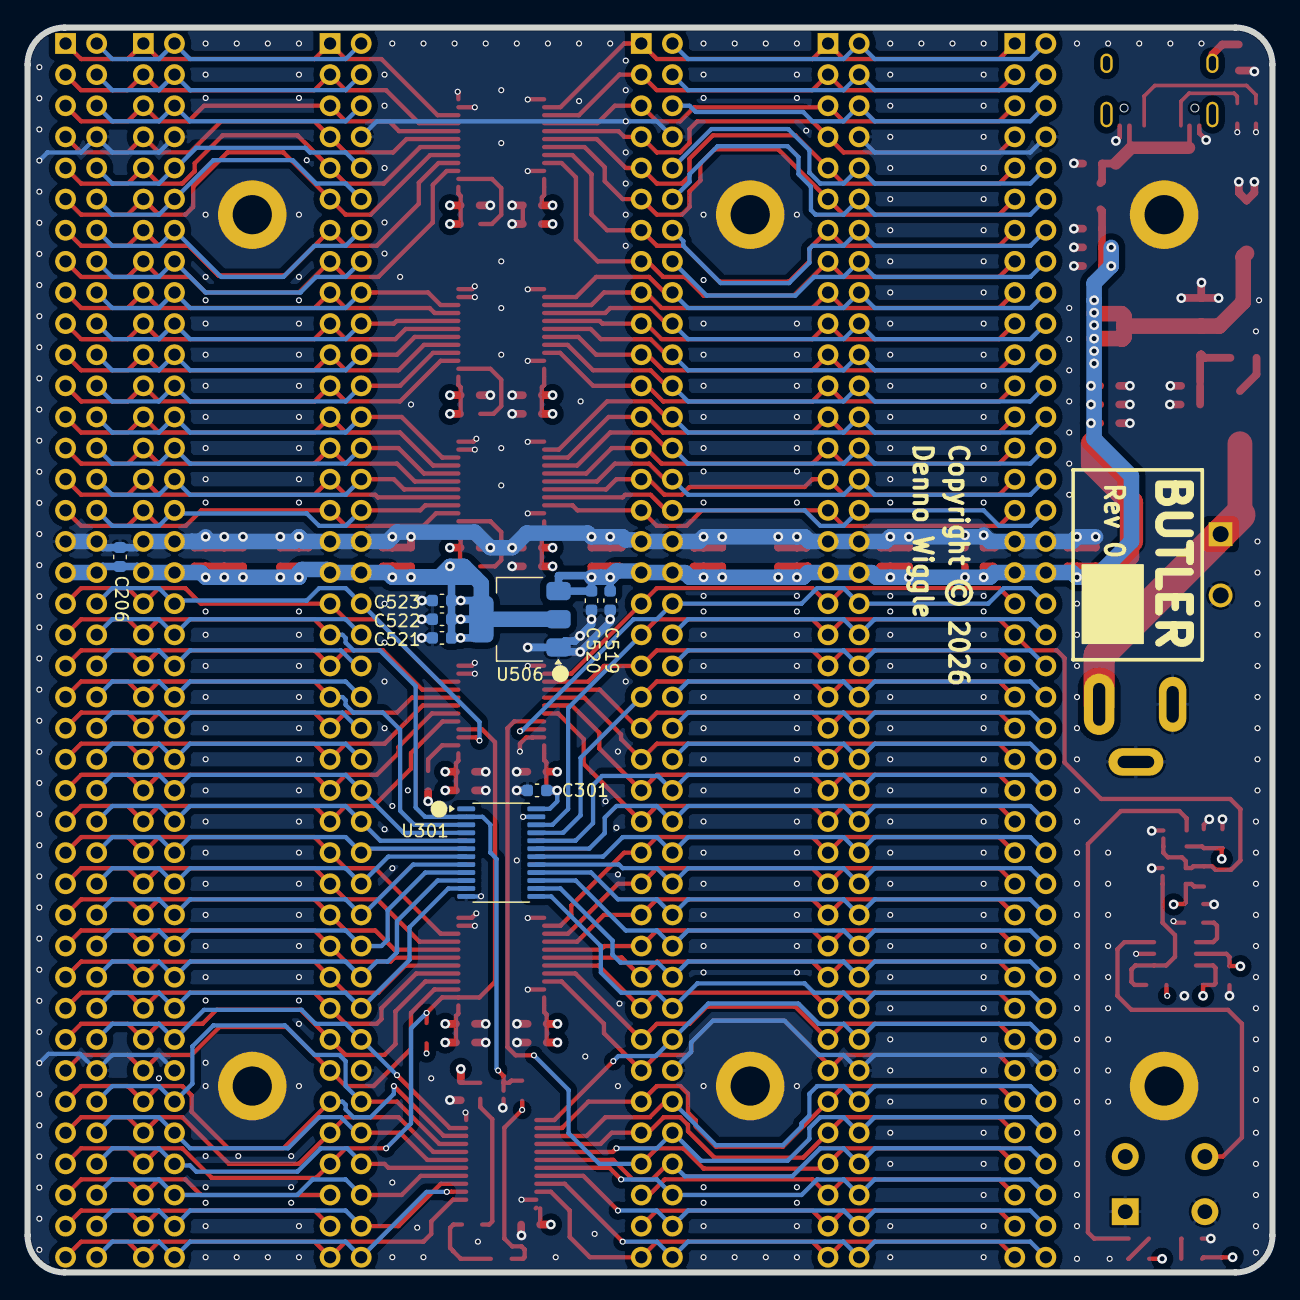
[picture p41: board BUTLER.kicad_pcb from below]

Board: 4 copper layers, 101.6 x 101.6 mm, 111 parts (9 on the bottom side), 170 nets.

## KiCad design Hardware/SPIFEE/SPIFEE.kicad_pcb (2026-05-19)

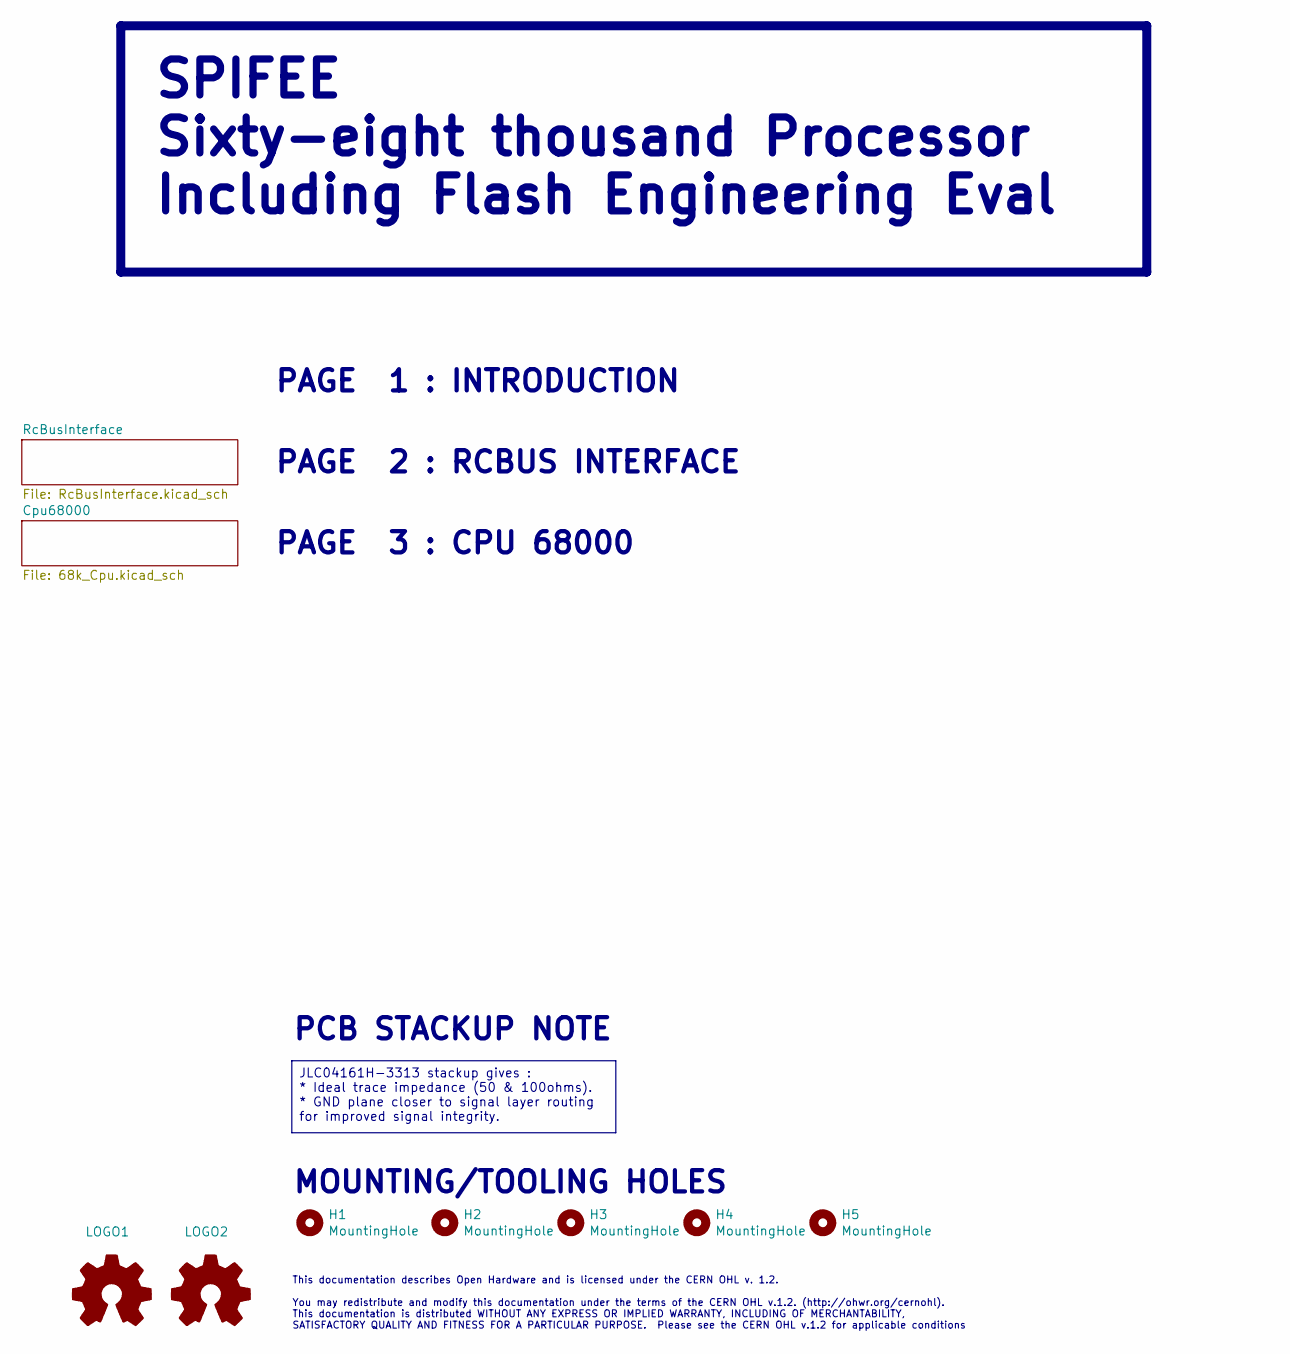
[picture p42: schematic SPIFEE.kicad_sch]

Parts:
H1: MountingHole; MountingHole_3.2mm_M3
H2, H3, H4, H5: MountingHole; MountingHole_2.7mm_M2.5_DIN965
LOGO1, LOGO2: Logo_Open_Hardware_Small; OSHW-Logo_7.5x8mm_SilkScreen

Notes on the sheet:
MOUNTING/TOOLING HOLES
PAGE 1 : INTRODUCTION
PCB STACKUP NOTE
This documentation describes Open Hardware and is licensed under the CERN OHL v. 1.2. You may redistribute and modify this documentation under the terms of the CERN OHL v.1.2. (http://ohwr.org/cernohl). This documentation is distributed WITHOUT ANY EXPRESS OR IMPLIED WARRANTY, INCLUDING OF MERCHANT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
PAGE 3 : CPU 68000
PAGE 2 : RCBUS INTERFACE
JLC04161H-3313 stackup gives : * Ideal trace impedance (50 & 100ohms). * GND plane closer to signal layer routing for improved signal integrity.
SPIFEE Sixty-eight thousand Processor Including Flash Engineering Eval

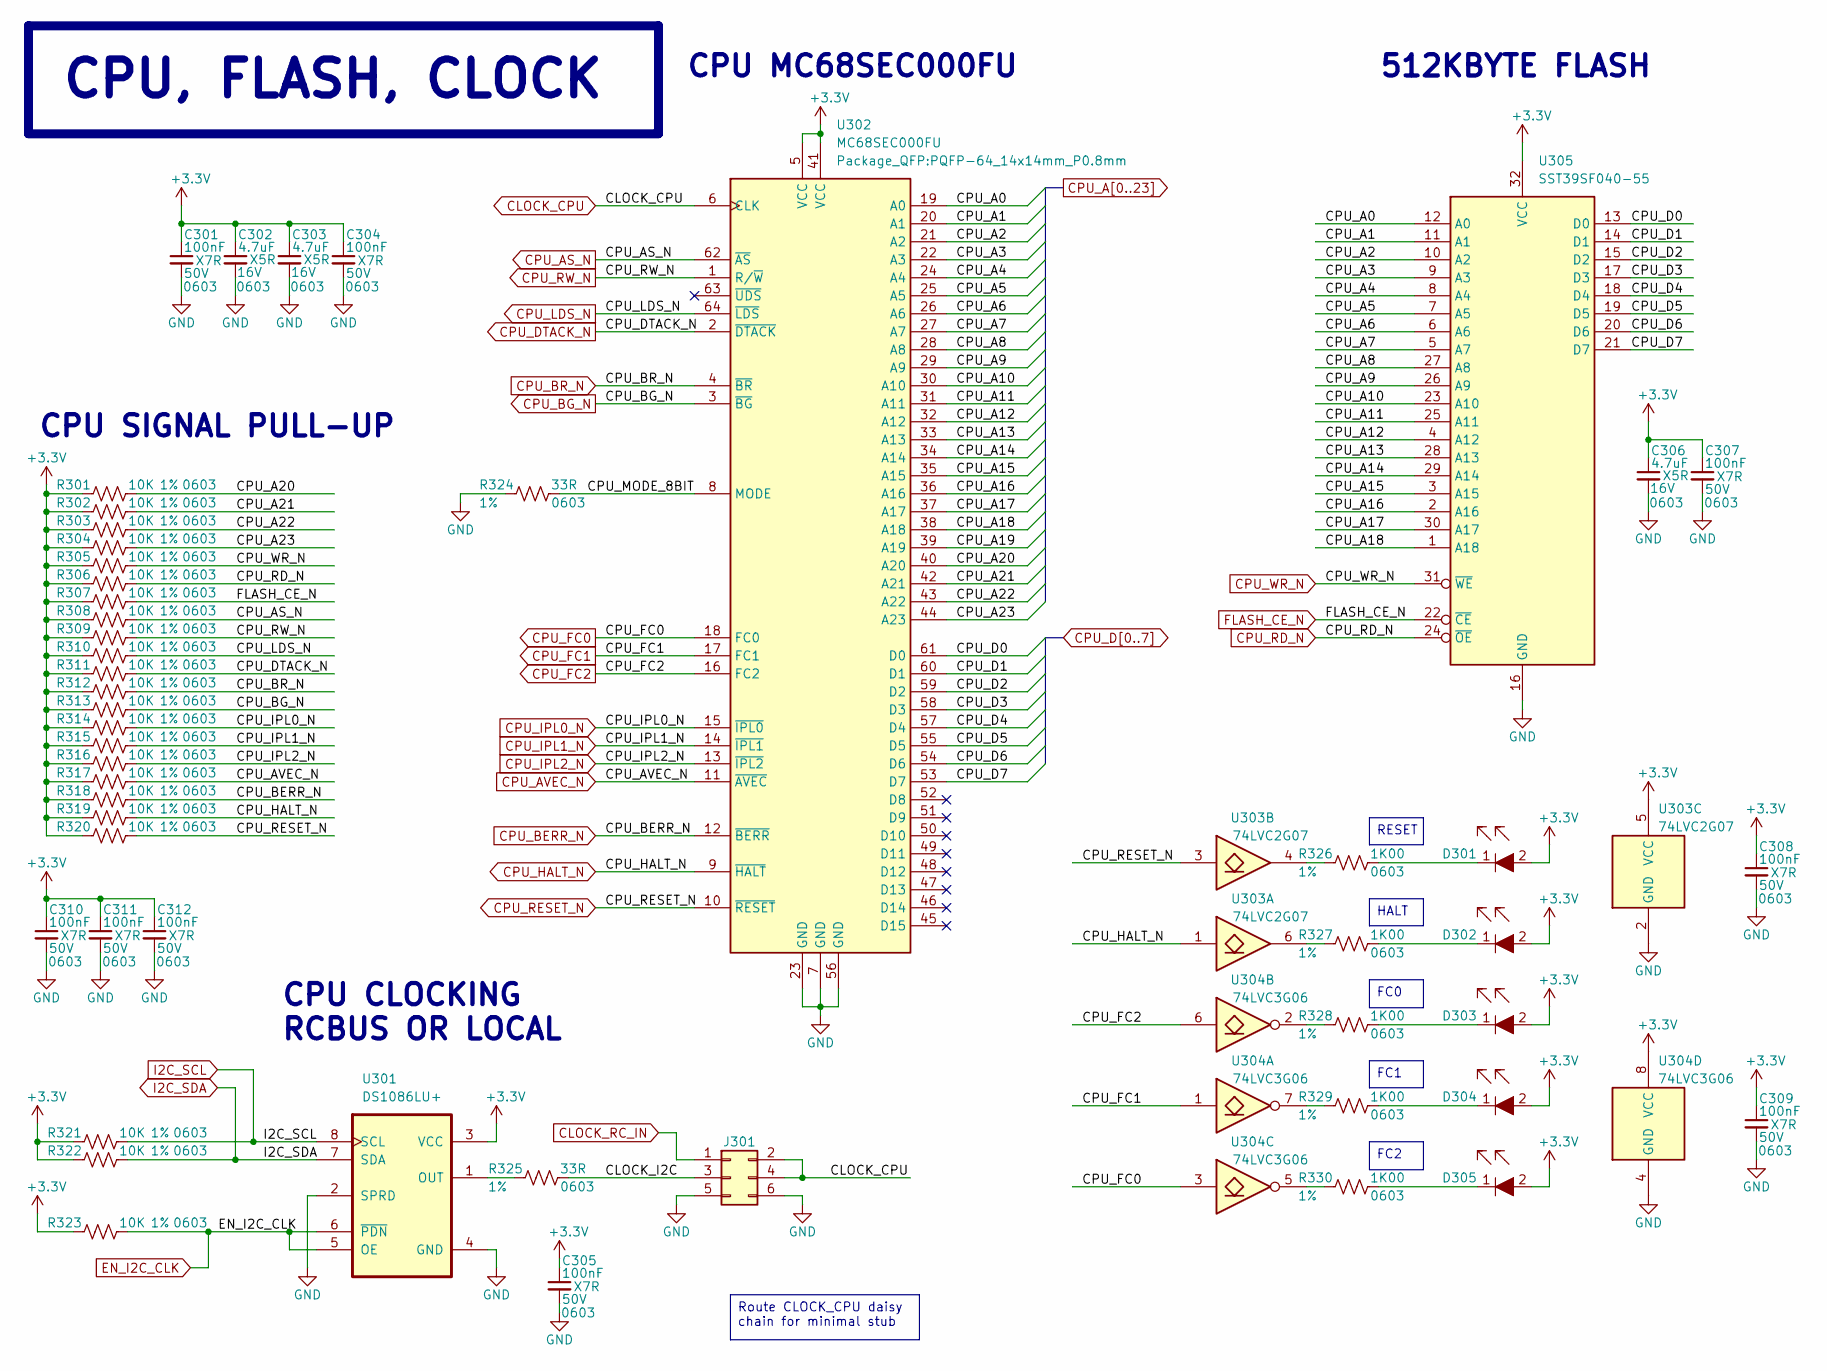
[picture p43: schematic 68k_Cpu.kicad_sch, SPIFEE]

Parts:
C301, C304, C305, C307, C308, C309, C310, C311, C312: 100nF; C_0603_1608Metric; Voltage 50V; Tolerance 10%; MPN CC0603KRX7R9BB104; Digikey 311-1344-1-ND
C302, C303, C306: 4.7uF; C_0603_1608Metric; Voltage 16V; Tolerance 10%; MPN CL10A475KO8NNNC; Digikey 1276-1784-1-ND
D301, D302, D303, D304, D305: LED_LTST-S270KGKT; LTST-S270KGKT; MPN LTST-S270KGKT; Digikey 160-1478-1-ND
J301: Conn_02x03; PinHeader_2x03_P2.54mm_Vertical; MPN PH2-06-UA; Digikey 2057-PH2-06-UA-ND
R301, R302, R303, R304, R305, R306, R307, R308, R309, R310, R311, R312, R313, R314, R315, R316, R317, R318, R319, R320, R321, R322, R323: 10K; R_0603_1608Metric; Tolerance 1%; MPN RC0603FR-0710KL; Digikey 311-10.0KHRCT-ND
R324, R325: 33R; R_0603_1608Metric; Tolerance 1%; MPN RC0603FR-0733RL; Digikey 13-RC0603FR-0733RLCT-ND
R326, R327, R328, R329, R330: 1K00; R_0603_1608Metric; Tolerance 1%; MPN RC0603FR-071KL; Digikey 311-1.00KHRCT-ND
U301: DS1086LU+; MSOP-8_3x3mm_P0.65mm; MPN DS1086LU+; Digikey DS1086LU+-ND
U302: MC68SEC000FU; PQFP-64_14x14mm_P0.8mm; MPN MC68SEC000FU20
U303: 74LVC2G07; SOT-363_SC-70-6; MPN 74LVC2G07GW,125; Digikey 1727-4121-1-ND
U304: 74LVC3G06; SSOP-8_2.95x2.8mm_P0.65mm; MPN 74LVC3G06SS8-7; Digikey 31-74LVC3G06SS8-7CT-ND
U305: SST39SF040-55; PLCC32_SMT_SOCKET_AMPHENOL_69802-132LF; MPN SST39LF040-55-4C-NHE; Digikey SST39LF040-55-4C-NHE-ND

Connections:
+3.3V: C301.1, C302.1, C303.1, C304.1, C305.1, C306.1, C307.1, C308.1, C309.1, C310.1, C311.1, C312.1, D301.2, D302.2, D303.2, D304.2, D305.2, R301.1, R302.1, R303.1, R304.1, R305.1, R306.1, R307.1, R308.1, R309.1, R310.1, R311.1, R312.1, R313.1, R314.1, R315.1, R316.1, R317.1, R318.1, R319.1, R320.1, R321.1, R322.1, R323.1, U301.3 (VCC), U302.5 (VCC), U302.41 (VCC), U303.5 (VCC), U304.8 (VCC), U305.32 (VCC); also elsewhere on the board
/Cpu68000/CLOCK_I2C: J301.3, R325.2
/Cpu68000/CPU_MODE_8BIT: R324.2, U302.8 (MODE)
CLOCK_CPU: J301.2, J301.4, U302.6 (CLK); also elsewhere on the board
CLOCK_RC_IN: J301.1; also elsewhere on the board
CPU_A0: U302.19 (A0), U305.12 (A0); also elsewhere on the board
CPU_A1: U302.20 (A1), U305.11 (A1); also elsewhere on the board
CPU_A2: U302.21 (A2), U305.10 (A2); also elsewhere on the board
CPU_A3: U302.22 (A3), U305.9 (A3); also elsewhere on the board
CPU_A4: U302.24 (A4), U305.8 (A4); also elsewhere on the board
CPU_A5: U302.25 (A5), U305.7 (A5); also elsewhere on the board
CPU_A6: U302.26 (A6), U305.6 (A6); also elsewhere on the board
CPU_A7: U302.27 (A7), U305.5 (A7); also elsewhere on the board
CPU_A8: U302.28 (A8), U305.27 (A8); also elsewhere on the board
CPU_A9: U302.29 (A9), U305.26 (A9); also elsewhere on the board
CPU_A10: U302.30 (A10), U305.23 (A10); also elsewhere on the board
CPU_A11: U302.31 (A11), U305.25 (A11); also elsewhere on the board
CPU_A12: U302.32 (A12), U305.4 (A12); also elsewhere on the board
CPU_A13: U302.33 (A13), U305.28 (A13); also elsewhere on the board
CPU_A14: U302.34 (A14), U305.29 (A14); also elsewhere on the board
CPU_A15: U302.35 (A15), U305.3 (A15); also elsewhere on the board
CPU_A16: U302.36 (A16), U305.2 (A16); also elsewhere on the board
CPU_A17: U302.37 (A17), U305.30 (A17); also elsewhere on the board
CPU_A18: U302.38 (A18), U305.1 (A18); also elsewhere on the board
CPU_A19: U302.39 (A19); also elsewhere on the board
CPU_A20: R301.2, U302.40 (A20); also elsewhere on the board
CPU_A21: R302.2, U302.42 (A21); also elsewhere on the board
CPU_A22: R303.2, U302.43 (A22); also elsewhere on the board
CPU_A23: R304.2, U302.44 (A23); also elsewhere on the board
CPU_AS_N: R308.2, U302.62 (~AS); also elsewhere on the board
CPU_AVEC_N: R317.2, U302.11 (~AVEC); also elsewhere on the board
CPU_BERR_N: R318.2, U302.12 (~BERR); also elsewhere on the board
CPU_BG_N: R313.2, U302.3 (~BG); also elsewhere on the board
CPU_BR_N: R312.2, U302.4 (~BR); also elsewhere on the board
CPU_D0: U302.61 (D0), U305.13 (D0); also elsewhere on the board
CPU_D1: U302.60 (D1), U305.14 (D1); also elsewhere on the board
CPU_D2: U302.59 (D2), U305.15 (D2); also elsewhere on the board
CPU_D3: U302.58 (D3), U305.17 (D3); also elsewhere on the board
CPU_D4: U302.57 (D4), U305.18 (D4); also elsewhere on the board
CPU_D5: U302.55 (D5), U305.19 (D5); also elsewhere on the board
CPU_D6: U302.54 (D6), U305.20 (D6); also elsewhere on the board
CPU_D7: U302.53 (D7), U305.21 (D7); also elsewhere on the board
CPU_DTACK_N: R311.2, U302.2 (~DTACK); also elsewhere on the board
CPU_FC0: U302.18 (FC0), U304.3; also elsewhere on the board
CPU_FC1: U302.17 (FC1), U304.1; also elsewhere on the board
CPU_FC2: U302.16 (FC2), U304.6; also elsewhere on the board
CPU_HALT_N: R319.2, U302.9 (~HALT), U303.1; also elsewhere on the board
CPU_IPL0_N: R314.2, U302.15 (~IPL0); also elsewhere on the board
CPU_IPL1_N: R315.2, U302.14 (~IPL1); also elsewhere on the board
CPU_IPL2_N: R316.2, U302.13 (~IPL2); also elsewhere on the board
CPU_LDS_N: R310.2, U302.64 (~LDS); also elsewhere on the board
CPU_RD_N: R306.2, U305.24 (~OE); also elsewhere on the board
CPU_RESET_N: R320.2, U302.10 (~RESET), U303.3; also elsewhere on the board
CPU_RW_N: R309.2, U302.1 (R/~W); also elsewhere on the board
CPU_WR_N: R305.2, U305.31 (~WE); also elsewhere on the board
EN_I2C_CLK: R323.2, U301.5 (OE), U301.6 (~PDN); also elsewhere on the board
FLASH_CE_N: R307.2, U305.22 (~CE); also elsewhere on the board
GND: C301.2, C302.2, C303.2, C304.2, C305.2, C306.2, C307.2, C308.2, C309.2, C310.2, C311.2, C312.2, J301.5, J301.6, R324.1, U301.2 (SPRD), U301.4 (GND), U302.7 (GND), U302.23 (GND), U302.56 (GND), U303.2 (GND), U304.4 (GND), U305.16 (GND); also elsewhere on the board
I2C_SCL: R321.2, U301.8 (SCL); also elsewhere on the board
I2C_SDA: R322.2, U301.7 (SDA); also elsewhere on the board
unnamed: D301.1, R326.2
unnamed: D302.1, R327.2
unnamed: D303.1, R328.2
unnamed: D304.1, R329.2
unnamed: D305.1, R330.2
unnamed: R326.1, U303.4
unnamed: R327.1, U303.6
unnamed: R328.1, U304.2
unnamed: R329.1, U304.7
unnamed: R330.1, U304.5
unnamed: R325.1, U301.1 (OUT)

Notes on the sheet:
512KBYTE FLASH
CPU SIGNAL PULL-UP
CPU CLOCKING RCBUS OR LOCAL
CPU MC68SEC000FU
HALT
FC0
CPU, FLASH, CLOCK
Route CLOCK_CPU daisy chain for minimal stub
FC1
RESET
FC2

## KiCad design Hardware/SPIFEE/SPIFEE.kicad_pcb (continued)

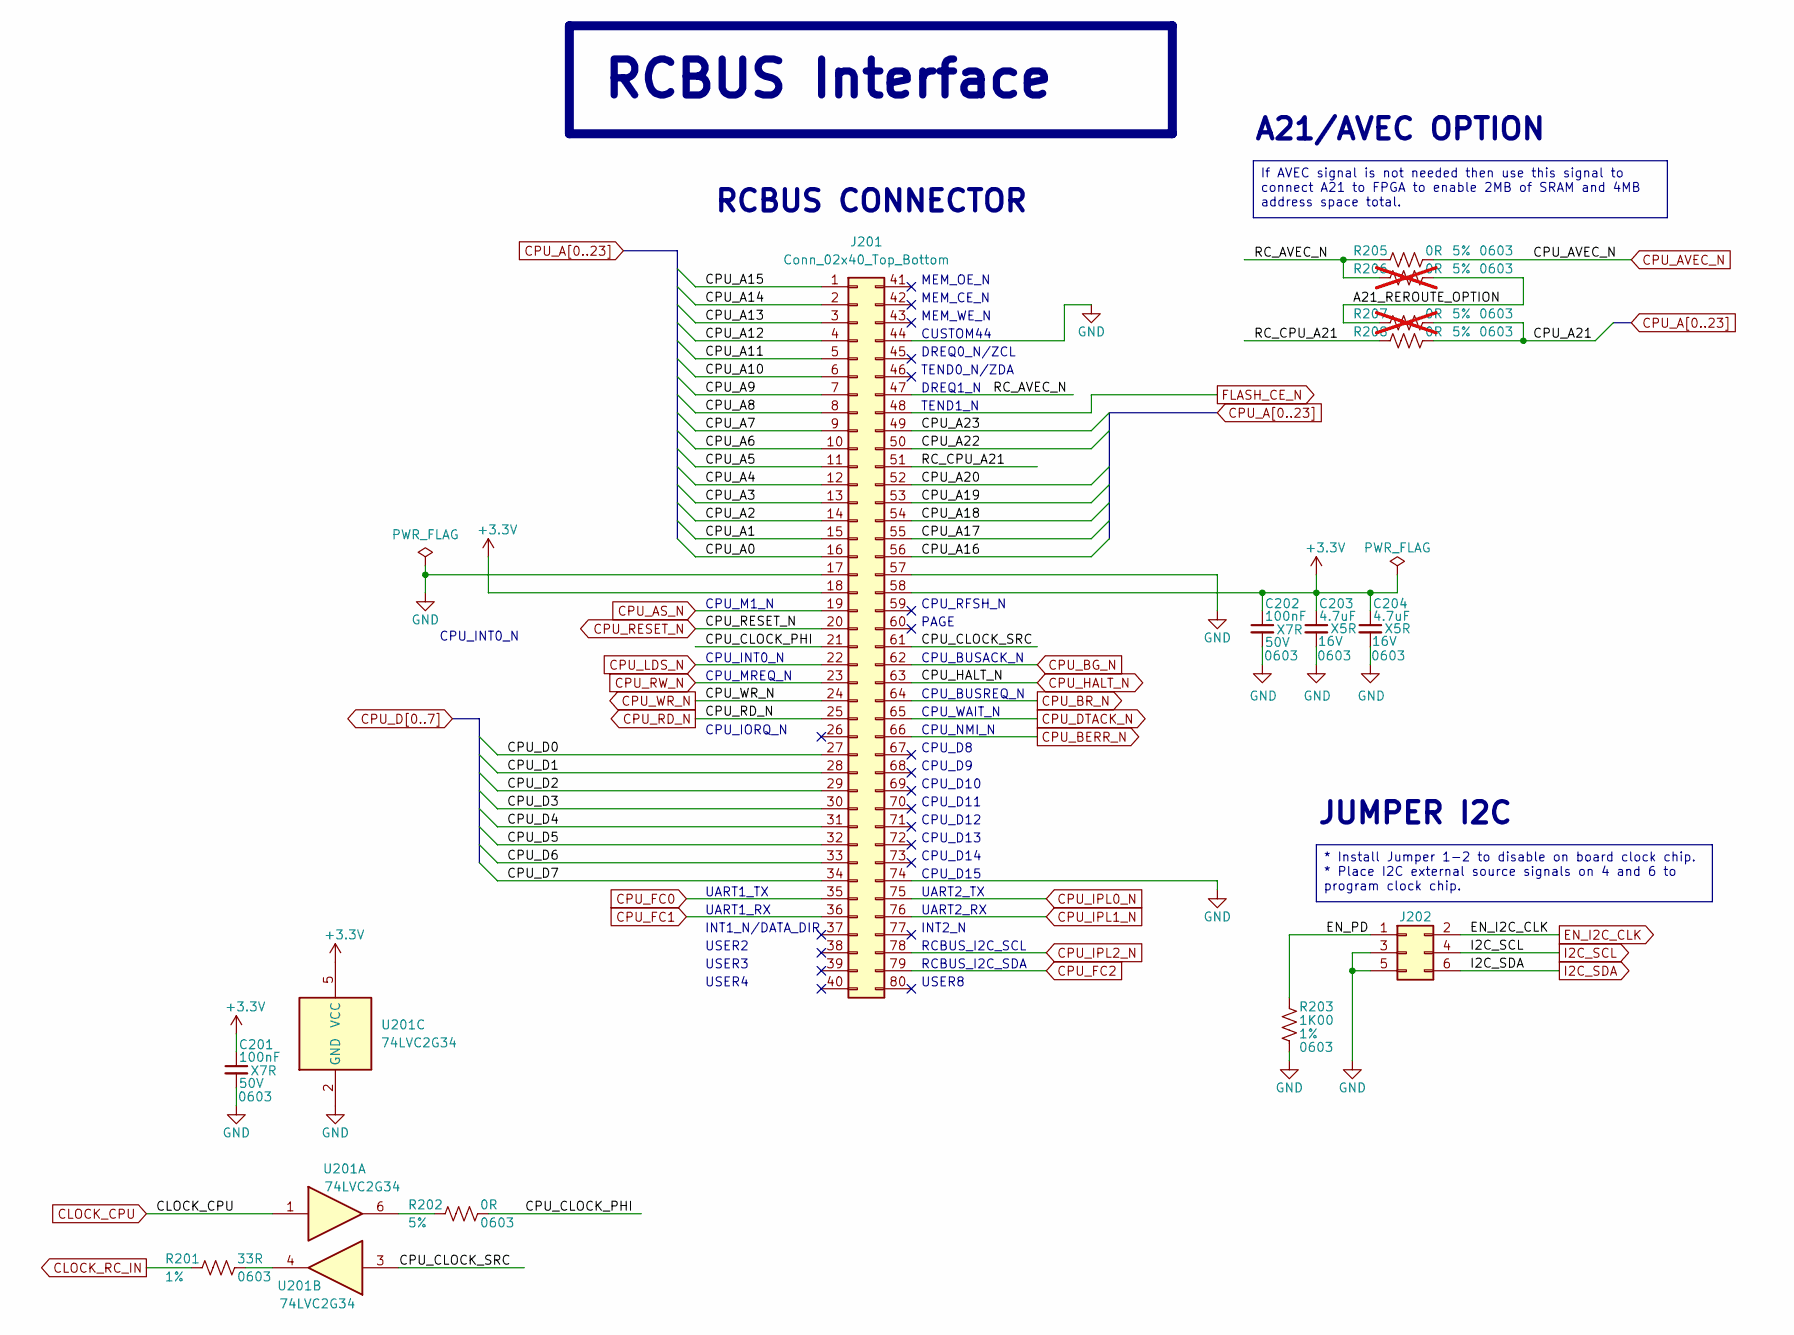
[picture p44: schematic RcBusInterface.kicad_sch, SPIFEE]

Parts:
C201, C202: 100nF; C_0603_1608Metric; Voltage 50V; Tolerance 10%; MPN CC0603KRX7R9BB104; Digikey 311-1344-1-ND
C203, C204: 4.7uF; C_0603_1608Metric; Voltage 16V; Tolerance 10%; MPN CL10A475KO8NNNC; Digikey 1276-1784-1-ND
J201: Conn_02x40_Top_Bottom; RCBUS_PinHeader_2x40_P2.54mm_Horizontal; MPN PH2RA-80-UA; Digikey 2057-PH2RA-80-UA-ND
J202: Conn_02x03; PinHeader_2x03_P2.54mm_Vertical; MPN PH2-06-UA; Digikey 2057-PH2-06-UA-ND
R201: 33R; R_0603_1608Metric; Tolerance 1%; MPN RC0603FR-0733RL; Digikey 13-RC0603FR-0733RLCT-ND
R202, R205, R208: 0R; R_0603_1608Metric; Tolerance 5%; MPN RC0603JR-070RL; Digikey 311-0.0GRCT-ND
R203: 1K00; R_0603_1608Metric; Tolerance 1%; MPN RC0603FR-071KL; Digikey 311-1.00KHRCT-ND
R206, R207: 0R; R_0603_1608Metric; Tolerance 5%; MPN RC0603JR-070RL; Digikey 311-0.0GRCT-ND; not fitted
U201: 74LVC2G34; SOT-363_SC-70-6; MPN 74LVC2G34GW,125; Digikey 1727-4219-1-ND

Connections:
+3.3V: C201.1, C202.1, C203.1, C204.1, J201.18, J201.58, U201.5 (VCC); also elsewhere on the board
/RcBusInterface/A21_REROUTE_OPTION: R206.2, R207.1
/RcBusInterface/CPU_CLOCK_PHI: J201.21, R202.2
/RcBusInterface/CPU_CLOCK_SRC: J201.61, U201.3
/RcBusInterface/EN_PD: J202.1, R203.1
/RcBusInterface/RC_AVEC_N: J201.47, R205.1, R206.1
/RcBusInterface/RC_CPU_A21: J201.51, R208.1
CLOCK_CPU: U201.1; also elsewhere on the board
CLOCK_RC_IN: R201.1; also elsewhere on the board
CPU_A0: J201.16; also elsewhere on the board
CPU_A1: J201.15; also elsewhere on the board
CPU_A2: J201.14; also elsewhere on the board
CPU_A3: J201.13; also elsewhere on the board
CPU_A4: J201.12; also elsewhere on the board
CPU_A5: J201.11; also elsewhere on the board
CPU_A6: J201.10; also elsewhere on the board
CPU_A7: J201.9; also elsewhere on the board
CPU_A8: J201.8; also elsewhere on the board
CPU_A9: J201.7; also elsewhere on the board
CPU_A10: J201.6; also elsewhere on the board
CPU_A11: J201.5; also elsewhere on the board
CPU_A12: J201.4; also elsewhere on the board
CPU_A13: J201.3; also elsewhere on the board
CPU_A14: J201.2; also elsewhere on the board
CPU_A15: J201.1; also elsewhere on the board
CPU_A16: J201.56; also elsewhere on the board
CPU_A17: J201.55; also elsewhere on the board
CPU_A18: J201.54; also elsewhere on the board
CPU_A19: J201.53; also elsewhere on the board
CPU_A20: J201.52; also elsewhere on the board
CPU_A21: R207.2, R208.2; also elsewhere on the board
CPU_A22: J201.50; also elsewhere on the board
CPU_A23: J201.49; also elsewhere on the board
CPU_AS_N: J201.19; also elsewhere on the board
CPU_AVEC_N: R205.2; also elsewhere on the board
CPU_BERR_N: J201.66; also elsewhere on the board
CPU_BG_N: J201.62; also elsewhere on the board
CPU_BR_N: J201.64; also elsewhere on the board
CPU_D0: J201.27; also elsewhere on the board
CPU_D1: J201.28; also elsewhere on the board
CPU_D2: J201.29; also elsewhere on the board
CPU_D3: J201.30; also elsewhere on the board
CPU_D4: J201.31; also elsewhere on the board
CPU_D5: J201.32; also elsewhere on the board
CPU_D6: J201.33; also elsewhere on the board
CPU_D7: J201.34; also elsewhere on the board
CPU_DTACK_N: J201.65; also elsewhere on the board
CPU_FC0: J201.35; also elsewhere on the board
CPU_FC1: J201.36; also elsewhere on the board
CPU_FC2: J201.79; also elsewhere on the board
CPU_HALT_N: J201.63; also elsewhere on the board
CPU_IPL0_N: J201.75; also elsewhere on the board
CPU_IPL1_N: J201.76; also elsewhere on the board
CPU_IPL2_N: J201.78; also elsewhere on the board
CPU_LDS_N: J201.22; also elsewhere on the board
CPU_RD_N: J201.25; also elsewhere on the board
CPU_RESET_N: J201.20; also elsewhere on the board
CPU_RW_N: J201.23; also elsewhere on the board
CPU_WR_N: J201.24; also elsewhere on the board
EN_I2C_CLK: J202.2; also elsewhere on the board
FLASH_CE_N: J201.48; also elsewhere on the board
GND: C201.2, C202.2, C203.2, C204.2, J201.17, J201.44, J201.57, J201.74, J202.3, J202.5, R203.2, U201.2 (GND); also elsewhere on the board
I2C_SCL: J202.4; also elsewhere on the board
I2C_SDA: J202.6; also elsewhere on the board
unnamed: R201.2, U201.4
unnamed: R202.1, U201.6

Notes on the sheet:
MEM_OE_N
A21/AVEC OPTION
CPU_NMI_N
CPU_BUSACK_N
CPU_INT0_N
MEM_WE_N
CPU_RFSH_N
CPU_D11
RCBUS_I2C_SDA
RCBUS CONNECTOR
CPU_D15
TEND1_N
CPU_D8
CPU_D14
UART2_TX
CPU_D12
UART2_RX
USER2
INT2_N
USER4
JUMPER I2C
CPU_MREQ_N
USER3
CPU_M1_N
CPU_WAIT_N
RCBUS_I2C_SCL
TEND0_N/ZDA
INT1_N/DATA_DIR
MEM_CE_N
UART1_TX
CPU_D9
USER8
DREQ0_N/ZCL
UART1_RX
CPU_D13
PAGE
CPU_BUSREQ_N
CUSTOM44
DREQ1_N
CPU_IORQ_N

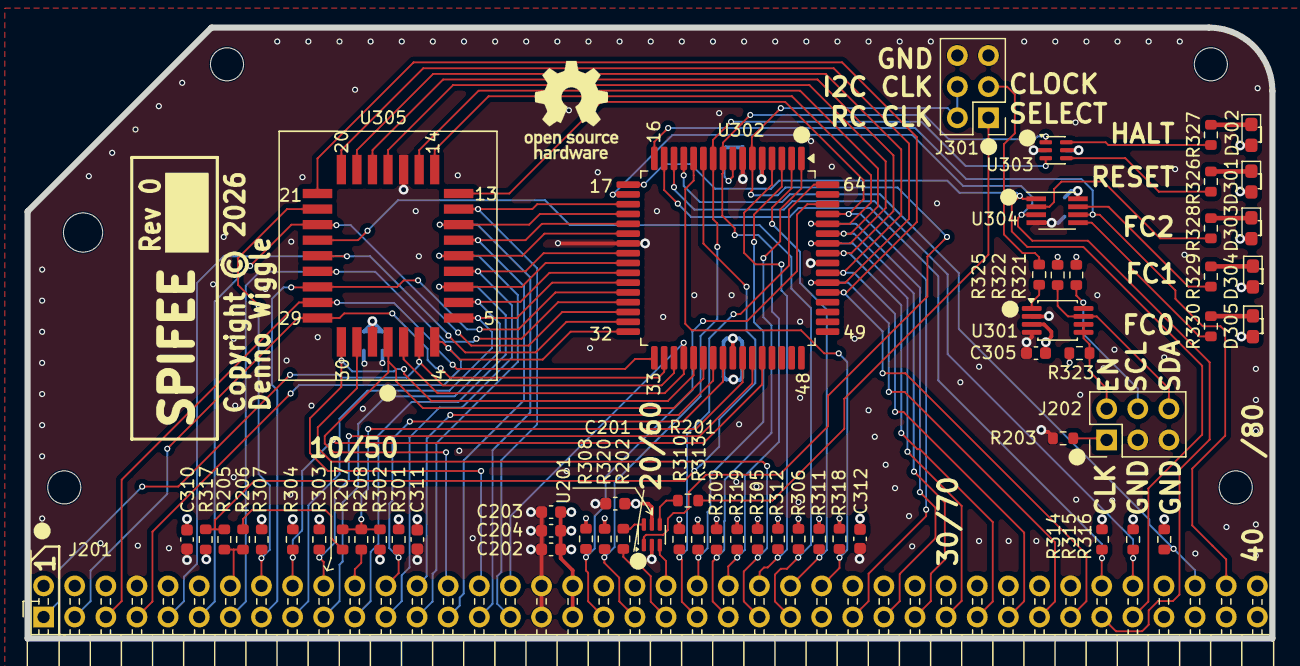
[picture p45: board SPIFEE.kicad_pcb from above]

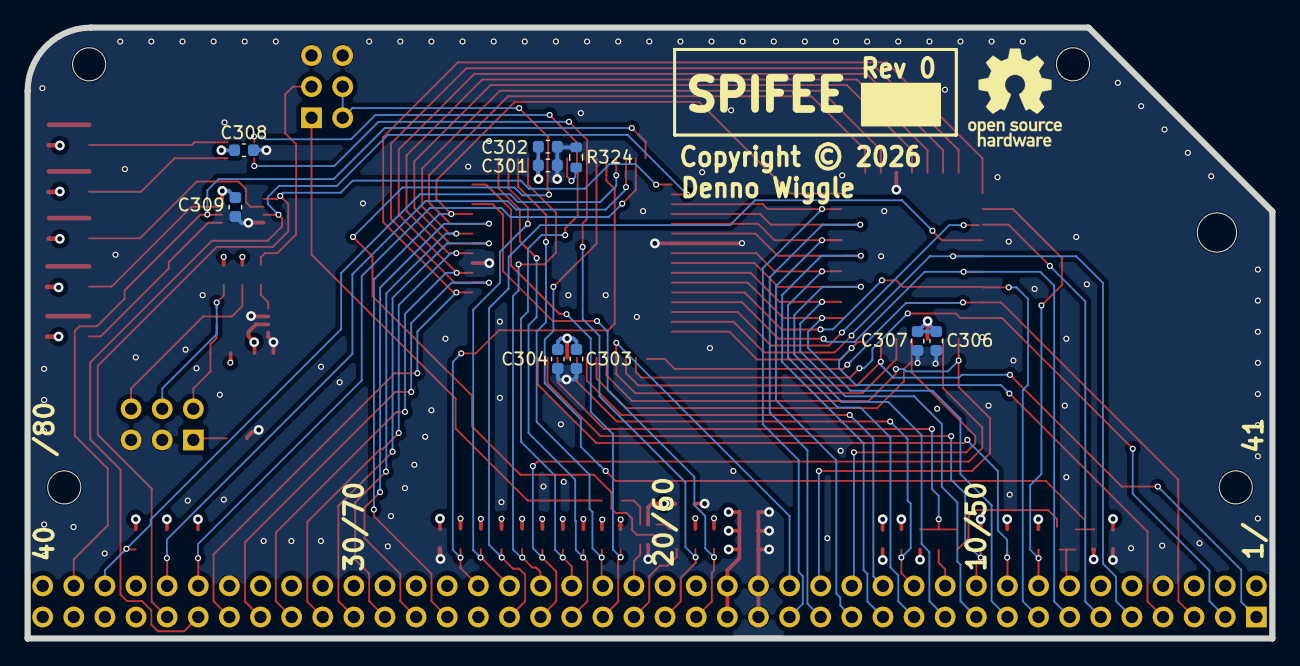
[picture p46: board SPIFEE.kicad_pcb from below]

Board: 4 copper layers, 101.6 x 49.9 mm, 74 parts (10 on the bottom side), 79 nets.

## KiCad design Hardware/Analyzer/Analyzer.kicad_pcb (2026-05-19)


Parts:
H4: MountingHole; MountingHole_2.7mm_M2.5_DIN965
LOGO1, LOGO2: Logo_Open_Hardware_Small; OSHW-Logo_7.5x8mm_SilkScreen

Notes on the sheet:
MOUNTING/TOOLING HOLES
PAGE 4 : PI PICO ANALYZER B
PAGE 1 : INTRODUCTION
PCB STACKUP NOTE
This documentation describes Open Hardware and is licensed under the CERN OHL v. 1.2. You may redistribute and modify this documentation under the terms of the CERN OHL v.1.2. (http://ohwr.org/cernohl). This documentation is distributed WITHOUT ANY EXPRESS OR IMPLIED WARRANTY, INCLUDING OF MERCHANT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
PAGE 3 : PI PICO ANALYZER A
PAGE 5 : Pi PICO ANALYZER C
PAGE 2 : RCBUS INTERFACE & POWER SUPPLY
BACKGROUND OF DESIGN
This design is a derivative work of John Winans S-100 bus logic analyzer targeted for RCBUS instead of S-100 bus. https://github.com/johnwinans/2070-S-100-bus-analyzer Both projects use the Dr Gusman software and firmware. https://github.com/gusmanb/logicanalyzer
JLC04161H-3313 stackup gives : * Ideal trace impedance (50 & 100ohms). * GND plane closer to signal layer routing for improved signal integrity.
ANALYZER Logic Analyzer for RCBUS using PI PICO 2[W]


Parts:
A501: RaspberryPi_Pico2W; RaspberryPi_Pico_Common_THT; MPN SC1634; Digikey 2648-SC1634-ND
C501, C503, C504, C506, C508: 100nF; C_0603_1608Metric; Voltage 50V; Tolerance 10%; MPN CC0603KRX7R9BB104; Digikey 311-1344-1-ND
C502, C505, C507: 4.7uF; C_0603_1608Metric; Voltage 16V; Tolerance 10%; MPN CL10A475KO8NNNC; Digikey 1276-1784-1-ND
J501: Conn_01x02; PinHeader_1x02_P2.54mm_Vertical; MPN PH2-02-UA; Digikey 2057-PH2-02-UA-ND
R502: 10K; R_0603_1608Metric; Tolerance 1%; MPN RC0603FR-0710KL; Digikey 311-10.0KHRCT-ND
U502, U503, U504: 74LVCH245APW,118; TSSOP-20_4.4x6.5mm_P0.65mm; MPN 74LVCH245APW,118; Digikey 1727-4041-1-ND

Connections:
3V3_PICO_C: A501.36 (3V3), C501.1, C502.1, C503.1, C504.1, C505.1, C506.1, R502.2, U502.20 (VCC), U503.20 (VCC), U504.20 (VCC)
+VSYS: A501.39 (VSYS), C507.1, C508.1; also elsewhere on the board
/PiPicoC/GPIO_CHC_A0: A501.31 (GPIO26_ADC0), U504.13 (B6)
/PiPicoC/GPIO_CHC_A1: A501.32 (GPIO27_ADC1), U504.12 (B7)
/PiPicoC/GPIO_CHC_A2: A501.34 (GPIO28_ADC2), U504.11 (B8)
/PiPicoC/GPIO_CHC_P2: A501.4 (GPIO2), U502.18 (B1)
/PiPicoC/GPIO_CHC_P3: A501.5 (GPIO3), U502.17 (B2)
/PiPicoC/GPIO_CHC_P4: A501.6 (GPIO4), U502.16 (B3)
/PiPicoC/GPIO_CHC_P5: A501.7 (GPIO5), U502.15 (B4)
/PiPicoC/GPIO_CHC_P6: A501.9 (GPIO6), U502.14 (B5)
/PiPicoC/GPIO_CHC_P7: A501.10 (GPIO7), U502.13 (B6)
/PiPicoC/GPIO_CHC_P8: A501.11 (GPIO8), U502.12 (B7)
/PiPicoC/GPIO_CHC_P9: A501.12 (GPIO9), U502.11 (B8)
/PiPicoC/GPIO_CHC_P10: A501.14 (GPIO10), U503.13 (B6)
/PiPicoC/GPIO_CHC_P11: A501.15 (GPIO11), U503.14 (B5)
/PiPicoC/GPIO_CHC_P12: A501.16 (GPIO12), U503.15 (B4)
/PiPicoC/GPIO_CHC_P13: A501.17 (GPIO13), U503.16 (B3)
/PiPicoC/GPIO_CHC_P14: A501.19 (GPIO14), U503.17 (B2)
/PiPicoC/GPIO_CHC_P15: A501.20 (GPIO15), U503.18 (B1)
/PiPicoC/GPIO_CHC_P16: A501.21 (GPIO16), U504.16 (B3)
/PiPicoC/GPIO_CHC_P17: A501.22 (GPIO17), U504.17 (B2)
/PiPicoC/GPIO_CHC_P18: A501.24 (GPIO18), U504.18 (B1)
/PiPicoC/GPIO_CHC_P19: A501.25 (GPIO19), U503.11 (B8)
/PiPicoC/GPIO_CHC_P20: A501.26 (GPIO20), U503.12 (B7)
/PiPicoC/GPIO_CHC_P21: A501.27 (GPIO21), U504.15 (B4)
/PiPicoC/GPIO_CHC_P22: A501.29 (GPIO22), U504.14 (B5)
/PiPicoC/TRIG_CHC: A501.1 (GPIO0), A501.2 (GPIO1), J501.1
D0: U502.2 (A1); also elsewhere on the board
D1: U502.4 (A3); also elsewhere on the board
D2: U502.6 (A5); also elsewhere on the board
D3: U502.8 (A7); also elsewhere on the board
D4: U503.2 (A1); also elsewhere on the board
D5: U503.4 (A3); also elsewhere on the board
D6: U503.6 (A5); also elsewhere on the board
D7: U503.8 (A7); also elsewhere on the board
D8: U502.3 (A2); also elsewhere on the board
D9: U502.5 (A4); also elsewhere on the board
D10: U502.7 (A6); also elsewhere on the board
D11: U502.9 (A8); also elsewhere on the board
D12: U503.3 (A2); also elsewhere on the board
D13: U503.5 (A4); also elsewhere on the board
D14: U503.7 (A6); also elsewhere on the board
D15: U503.9 (A8); also elsewhere on the board
DATA_DIR: U504.6 (A5); also elsewhere on the board
GND: A501.3 (GND), A501.8 (GND), A501.13 (GND), A501.18 (GND), A501.23 (GND), A501.28 (GND), A501.33 (AGND), A501.38 (GND), C501.2, C502.2, C503.2, C504.2, C505.2, C506.2, C507.2, C508.2, U502.10 (GND), U502.19 (~OE), U503.10 (GND), U503.19 (~OE), U504.10 (GND), U504.19 (~OE); also elsewhere on the board
unnamed: R502.1, U502.1 (DIR), U503.1 (DIR), U504.1 (DIR)
PICO_RESET_N: A501.30 (RUN); also elsewhere on the board
TRIG: J501.2; also elsewhere on the board
UART1_RX: U504.4 (A3); also elsewhere on the board
UART1_TX: U504.2 (A1); also elsewhere on the board
UART2_RX: U504.5 (A4); also elsewhere on the board
UART2_TX: U504.3 (A2); also elsewhere on the board
USER2: U504.7 (A6); also elsewhere on the board
USER3: U504.8 (A7); also elsewhere on the board
USER4: U504.9 (A8); also elsewhere on the board

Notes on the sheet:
Pi PICO Channel C


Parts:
A301: RaspberryPi_Pico2W; RaspberryPi_Pico_Common_THT; MPN SC1634; Digikey 2648-SC1634-ND
C301, C303, C304, C306, C308: 100nF; C_0603_1608Metric; Voltage 50V; Tolerance 10%; MPN CC0603KRX7R9BB104; Digikey 311-1344-1-ND
C302, C305, C307: 4.7uF; C_0603_1608Metric; Voltage 16V; Tolerance 10%; MPN CL10A475KO8NNNC; Digikey 1276-1784-1-ND
J301: Conn_01x02; PinHeader_1x02_P2.54mm_Vertical; MPN PH2-02-UA; Digikey 2057-PH2-02-UA-ND
R301: 10K; R_0603_1608Metric; Tolerance 1%; MPN RC0603FR-0710KL; Digikey 311-10.0KHRCT-ND
R302: 2.2K; R_0603_1608Metric; Tolerance 1%; MPN RC0603FR-072K2L; Digikey 311-2.20KHRCT-ND
U301, U302, U303: 74LVCH245APW,118; TSSOP-20_4.4x6.5mm_P0.65mm; MPN 74LVCH245APW,118; Digikey 1727-4041-1-ND

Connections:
3V3_PICO_A: A301.36 (3V3), C301.1, C302.1, C303.1, C304.1, C305.1, C306.1, R301.2, U301.20 (VCC), U302.20 (VCC), U303.20 (VCC)
+VSYS: A301.39 (VSYS), C307.1, C308.1; also elsewhere on the board
/PiPicoA/GPIO_CHA_A0: A301.31 (GPIO26_ADC0), U303.18 (B1)
/PiPicoA/GPIO_CHA_A1: A301.32 (GPIO27_ADC1), U302.11 (B8)
/PiPicoA/GPIO_CHA_A2: A301.34 (GPIO28_ADC2), U302.12 (B7)
/PiPicoA/GPIO_CHA_P2: A301.4 (GPIO2), U301.17 (B2)
/PiPicoA/GPIO_CHA_P3: A301.5 (GPIO3), U301.15 (B4)
/PiPicoA/GPIO_CHA_P4: A301.6 (GPIO4), U301.13 (B6)
/PiPicoA/GPIO_CHA_P5: A301.7 (GPIO5), U301.11 (B8)
/PiPicoA/GPIO_CHA_P8: A301.11 (GPIO8), U302.13 (B6)
/PiPicoA/GPIO_CHA_P9: A301.12 (GPIO9), U302.14 (B5)
/PiPicoA/GPIO_CHA_P10: A301.14 (GPIO10), U302.15 (B4)
/PiPicoA/GPIO_CHA_P11: A301.15 (GPIO11), U302.16 (B3)
/PiPicoA/GPIO_CHA_P12: A301.16 (GPIO12), U302.17 (B2)
/PiPicoA/GPIO_CHA_P13: A301.17 (GPIO13), U302.18 (B1)
/PiPicoA/GPIO_CHA_P16: A301.21 (GPIO16), U303.15 (B4)
/PiPicoA/GPIO_CHA_P17: A301.22 (GPIO17), U303.14 (B5)
/PiPicoA/GPIO_CHA_P18: A301.24 (GPIO18), U303.13 (B6)
/PiPicoA/GPIO_CHA_P19: A301.25 (GPIO19), U303.12 (B7)
/PiPicoA/GPIO_CHA_P20: A301.26 (GPIO20), U303.11 (B8)
/PiPicoA/GPIO_CHA_P21: A301.27 (GPIO21), U303.16 (B3)
/PiPicoA/GPIO_CHA_P22: A301.29 (GPIO22), U303.17 (B2)
/PiPicoA/TRIG_CHA: A301.1 (GPIO0), A301.2 (GPIO1), J301.1
A0: U303.9 (A8); also elsewhere on the board
A1: U303.7 (A6); also elsewhere on the board
A2: U303.5 (A4); also elsewhere on the board
A3: U303.3 (A2); also elsewhere on the board
A4: U302.9 (A8); also elsewhere on the board
A5: U302.7 (A6); also elsewhere on the board
A6: U302.5 (A4); also elsewhere on the board
A7: U302.3 (A2); also elsewhere on the board
A12: U301.8 (A7); also elsewhere on the board
A13: U301.7 (A6); also elsewhere on the board
A14: U301.5 (A4); also elsewhere on the board
A15: U301.3 (A2); also elsewhere on the board
A16: U303.8 (A7); also elsewhere on the board
A17: U303.6 (A5); also elsewhere on the board
A18: U303.4 (A3); also elsewhere on the board
A19: U303.2 (A1); also elsewhere on the board
A20: U302.8 (A7); also elsewhere on the board
A21: U302.6 (A5); also elsewhere on the board
A22: U302.4 (A3); also elsewhere on the board
A23: U302.2 (A1); also elsewhere on the board
DREQ0_N: U301.9 (A8); also elsewhere on the board
GND: A301.3 (GND), A301.8 (GND), A301.13 (GND), A301.18 (GND), A301.23 (GND), A301.28 (GND), A301.33 (AGND), A301.38 (GND), C301.2, C302.2, C303.2, C304.2, C305.2, C306.2, C307.2, C308.2, R302.2, U301.10 (GND), U301.19 (~OE), U302.10 (GND), U302.19 (~OE), U303.10 (GND), U303.19 (~OE); also elsewhere on the board
GPIO_CHA_P6: A301.9 (GPIO6); also elsewhere on the board
GPIO_CHA_P7: A301.10 (GPIO7); also elsewhere on the board
GPIO_CHA_P14: A301.19 (GPIO14); also elsewhere on the board
GPIO_CHA_P15: A301.20 (GPIO15); also elsewhere on the board
GPIO_CHB_P2: U301.18 (B1); also elsewhere on the board
GPIO_CHB_P3: U301.16 (B3); also elsewhere on the board
GPIO_CHB_P4: U301.14 (B5); also elsewhere on the board
GPIO_CHB_P5: U301.12 (B7); also elsewhere on the board
MEM_CE_N: U301.4 (A3); also elsewhere on the board
MEM_OE_N: U301.2 (A1); also elsewhere on the board
MEM_WE_N: U301.6 (A5); also elsewhere on the board
unnamed: R301.1, U301.1 (DIR), U302.1 (DIR), U303.1 (DIR)
PICO_RESET_N: A301.30 (RUN); also elsewhere on the board
TRIG: J301.2, R302.1; also elsewhere on the board

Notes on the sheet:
Pi PICO Channel A


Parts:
C201, C202: 100nF; C_0603_1608Metric; Voltage 50V; Tolerance 10%; MPN CC0603KRX7R9BB104; Digikey 311-1344-1-ND
C203, C204, C205, C206: 4.7uF; C_0603_1608Metric; Voltage 16V; Tolerance 10%; MPN CL10A475KO8NNNC; Digikey 1276-1784-1-ND
D201: B320B-13-F; D_SMB; MPN B320B-13-F; Digikey B320B-FDICT-ND
FB201, FB202: BLM21PG121SN1D; L_0805_2012Metric; MPN BLM21PG121SN1D; Digikey 490-5986-1-ND
J201: Conn_02x40_Top_Bottom; RCBUS_PinHeader_2x40_P2.54mm_Horizontal; MPN PH2RA-80-UA; Digikey 2057-PH2RA-80-UA-ND
J202: USB_C_Receptacle_USB2.0; USB_C_Receptacle_HRO_TYPE-C-31-M-12; MPN USB4105-GF-A; LCSC Part # C167321
R201: 0R; R_0603_1608Metric; Tolerance 5%; MPN RC0603JR-070RL; Digikey 311-0.0GRCT-ND
R202, R203: 5K1; R_0603_1608Metric; Tolerance 1%; MPN RC0603FR-075K1L; Digikey 311-5.10KHRCT-ND
S201: 1825910-6; Switch_Tactile_THT_6x6mm; MPN 1825910-6; Digikey 450-1650-ND
Z201: SMBJ5.0A; D_SMB; MPN SMBJ5.0A; Digikey SMBJ5.0ALFCT-ND

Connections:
+5V: C202.1, C204.1, C206.1, D201.2 (A), FB202.2, Z201.1
+VSYS: C203.1, C205.1, D201.1 (K); also elsewhere on the board
/RcBusInterface/PWR_CC1: J202.A5 (CC1), R203.1
/RcBusInterface/PWR_CC2: J202.B5 (CC2), R202.1
/RcBusInterface/USER44: J201.44, R201.1
/RcBusInterface/VBUS_5V: C201.1, FB202.1, J202.A4 (VBUS), J202.A9 (VBUS), J202.B4 (VBUS), J202.B9 (VBUS)
A0: J201.16; also elsewhere on the board
A1: J201.15; also elsewhere on the board
A2: J201.14; also elsewhere on the board
A3: J201.13; also elsewhere on the board
A4: J201.12; also elsewhere on the board
A5: J201.11; also elsewhere on the board
A6: J201.10; also elsewhere on the board
A7: J201.9; also elsewhere on the board
A8: J201.8; also elsewhere on the board
A9: J201.7; also elsewhere on the board
A10: J201.6; also elsewhere on the board
A11: J201.5; also elsewhere on the board
A12: J201.4; also elsewhere on the board
A13: J201.3; also elsewhere on the board
A14: J201.2; also elsewhere on the board
A15: J201.1; also elsewhere on the board
A16: J201.56; also elsewhere on the board
A17: J201.55; also elsewhere on the board
A18: J201.54; also elsewhere on the board
A19: J201.53; also elsewhere on the board
A20: J201.52; also elsewhere on the board
A21: J201.51; also elsewhere on the board
A22: J201.50; also elsewhere on the board
A23: J201.49; also elsewhere on the board
BUSACK_N: J201.62; also elsewhere on the board
BUSREQ_N: J201.64; also elsewhere on the board
CLK_PHI: J201.21; also elsewhere on the board
CLK_SRC: J201.61; also elsewhere on the board
D0: J201.27; also elsewhere on the board
D1: J201.28; also elsewhere on the board
D2: J201.29; also elsewhere on the board
D3: J201.30; also elsewhere on the board
D4: J201.31; also elsewhere on the board
D5: J201.32; also elsewhere on the board
D6: J201.33; also elsewhere on the board
D7: J201.34; also elsewhere on the board
D8: J201.67; also elsewhere on the board
D9: J201.68; also elsewhere on the board
D10: J201.69; also elsewhere on the board
D11: J201.70; also elsewhere on the board
D12: J201.71; also elsewhere on the board
D13: J201.72; also elsewhere on the board
D14: J201.73; also elsewhere on the board
D15: J201.74; also elsewhere on the board
DATA_DIR: J201.37; also elsewhere on the board
DREQ0_N: J201.45; also elsewhere on the board
DREQ1_N: J201.47; also elsewhere on the board
GND: C201.2, C202.2, C203.2, C204.2, C205.2, C206.2, FB201.1, J201.17, J201.57, J202.A1 (GND), J202.A12 (GND), J202.B1 (GND), J202.B12 (GND), R201.2, R202.2, R203.2, S201.1, S201.2, Z201.2; also elsewhere on the board
HALT_N: J201.63; also elsewhere on the board
I2C_SCL: J201.78; also elsewhere on the board
I2C_SDA: J201.79; also elsewhere on the board
INT0_N: J201.22; also elsewhere on the board
IORQ_N: J201.26; also elsewhere on the board
M1_N: J201.19; also elsewhere on the board
MEM_CE_N: J201.42; also elsewhere on the board
MEM_OE_N: J201.41; also elsewhere on the board
MEM_WE_N: J201.43; also elsewhere on the board
MREQ_N: J201.23; also elsewhere on the board
NMI_N: J201.66; also elsewhere on the board
unnamed: FB201.2, J202.S1 (SHIELD)
PAGE: J201.60; also elsewhere on the board
PICO_RESET_N: S201.3; also elsewhere on the board
RD_N: J201.25; also elsewhere on the board
RESET_N: J201.20; also elsewhere on the board
TEND0_N: J201.46; also elsewhere on the board
TEND1_N: J201.48; also elsewhere on the board
UART1_RX: J201.36; also elsewhere on the board
UART1_TX: J201.35; also elsewhere on the board
UART2_RX: J201.76; also elsewhere on the board
UART2_TX: J201.75; also elsewhere on the board
USER2: J201.38; also elsewhere on the board
USER3: J201.39; also elsewhere on the board
USER4: J201.40; also elsewhere on the board
WAIT_N: J201.65; also elsewhere on the board
WR_N: J201.24; also elsewhere on the board

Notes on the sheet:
5.0V USB POWER SUPPLY
REFRESH_N
VBUS
40-PIN LEFT SIDE
USER8
80-PIN BOTH SIDES
YELLOW
GND
RCBUS CARD SOCKET CONNECTOR
PUSH BUTTON RESET FOR PICO
USER5
RCBUS CONNECTOR

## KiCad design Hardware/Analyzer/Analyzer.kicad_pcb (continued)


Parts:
A401: RaspberryPi_Pico2W; RaspberryPi_Pico_Common_THT; MPN SC1634; Digikey 2648-SC1634-ND
C401, C403, C404, C406, C408: 100nF; C_0603_1608Metric; Voltage 50V; Tolerance 10%; MPN CC0603KRX7R9BB104; Digikey 311-1344-1-ND
C402, C405, C407: 4.7uF; C_0603_1608Metric; Voltage 16V; Tolerance 10%; MPN CL10A475KO8NNNC; Digikey 1276-1784-1-ND
J401: Conn_01x02; PinHeader_1x02_P2.54mm_Vertical; MPN PH2-02-UA; Digikey 2057-PH2-02-UA-ND
R401: 10K; R_0603_1608Metric; Tolerance 1%; MPN RC0603FR-0710KL; Digikey 311-10.0KHRCT-ND
U401, U402, U403: 74LVCH245APW,118; TSSOP-20_4.4x6.5mm_P0.65mm; MPN 74LVCH245APW,118; Digikey 1727-4041-1-ND

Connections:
3V3_PICO_B: A401.36 (3V3), C401.1, C402.1, C403.1, C404.1, C405.1, C406.1, R401.2, U401.20 (VCC), U402.20 (VCC), U403.20 (VCC)
+VSYS: A401.39 (VSYS), C407.1, C408.1; also elsewhere on the board
/PiPicoB/GPIO_CHB_A0: A401.31 (GPIO26_ADC0), U403.13 (B6)
/PiPicoB/GPIO_CHB_A1: A401.32 (GPIO27_ADC1), U403.12 (B7)
/PiPicoB/GPIO_CHB_A2: A401.34 (GPIO28_ADC2), U403.11 (B8)
/PiPicoB/GPIO_CHB_P6: A401.9 (GPIO6), U401.17 (B2)
/PiPicoB/GPIO_CHB_P7: A401.10 (GPIO7), U401.15 (B4)
/PiPicoB/GPIO_CHB_P8: A401.11 (GPIO8), U401.13 (B6)
/PiPicoB/GPIO_CHB_P9: A401.12 (GPIO9), U401.11 (B8)
/PiPicoB/GPIO_CHB_P10: A401.14 (GPIO10), U402.13 (B6)
/PiPicoB/GPIO_CHB_P11: A401.15 (GPIO11), U402.14 (B5)
/PiPicoB/GPIO_CHB_P12: A401.16 (GPIO12), U402.15 (B4)
/PiPicoB/GPIO_CHB_P13: A401.17 (GPIO13), U402.16 (B3)
/PiPicoB/GPIO_CHB_P14: A401.19 (GPIO14), U402.17 (B2)
/PiPicoB/GPIO_CHB_P15: A401.20 (GPIO15), U402.18 (B1)
/PiPicoB/GPIO_CHB_P16: A401.21 (GPIO16), U403.15 (B4)
/PiPicoB/GPIO_CHB_P17: A401.22 (GPIO17), U403.16 (B3)
/PiPicoB/GPIO_CHB_P18: A401.24 (GPIO18), U403.17 (B2)
/PiPicoB/GPIO_CHB_P19: A401.25 (GPIO19), U403.18 (B1)
/PiPicoB/GPIO_CHB_P20: A401.26 (GPIO20), U402.11 (B8)
/PiPicoB/GPIO_CHB_P21: A401.27 (GPIO21), U402.12 (B7)
/PiPicoB/GPIO_CHB_P22: A401.29 (GPIO22), U403.14 (B5)
/PiPicoB/TRIG_CHB: A401.1 (GPIO0), A401.2 (GPIO1), J401.1
A8: U401.8 (A7); also elsewhere on the board
A9: U401.6 (A5); also elsewhere on the board
A10: U401.4 (A3); also elsewhere on the board
A11: U401.2 (A1); also elsewhere on the board
BUSACK_N: U402.7 (A6); also elsewhere on the board
BUSREQ_N: U403.3 (A2); also elsewhere on the board
CLK_PHI: U402.4 (A3); also elsewhere on the board
CLK_SRC: U402.5 (A4); also elsewhere on the board
DREQ1_N: U401.5 (A4); also elsewhere on the board
GND: A401.3 (GND), A401.8 (GND), A401.13 (GND), A401.18 (GND), A401.23 (GND), A401.28 (GND), A401.33 (AGND), A401.38 (GND), C401.2, C402.2, C403.2, C404.2, C405.2, C406.2, C407.2, C408.2, U401.10 (GND), U401.19 (~OE), U402.10 (GND), U402.19 (~OE), U403.10 (GND), U403.19 (~OE); also elsewhere on the board
GPIO_CHA_P6: U401.18 (B1); also elsewhere on the board
GPIO_CHA_P7: U401.16 (B3); also elsewhere on the board
GPIO_CHA_P14: U401.12 (B7); also elsewhere on the board
GPIO_CHA_P15: U401.14 (B5); also elsewhere on the board
GPIO_CHB_P2: A401.4 (GPIO2); also elsewhere on the board
GPIO_CHB_P3: A401.5 (GPIO3); also elsewhere on the board
GPIO_CHB_P4: A401.6 (GPIO4); also elsewhere on the board
GPIO_CHB_P5: A401.7 (GPIO5); also elsewhere on the board
HALT_N: U402.9 (A8); also elsewhere on the board
I2C_SCL: U403.8 (A7); also elsewhere on the board
I2C_SDA: U403.9 (A8); also elsewhere on the board
INT0_N: U402.6 (A5); also elsewhere on the board
IORQ_N: U403.6 (A5); also elsewhere on the board
M1_N: U401.9 (A8); also elsewhere on the board
MREQ_N: U402.8 (A7); also elsewhere on the board
NMI_N: U403.7 (A6); also elsewhere on the board
unnamed: R401.1, U401.1 (DIR), U402.1 (DIR), U403.1 (DIR)
PAGE: U402.3 (A2); also elsewhere on the board
PICO_RESET_N: A401.30 (RUN); also elsewhere on the board
RD_N: U403.4 (A3); also elsewhere on the board
RESET_N: U402.2 (A1); also elsewhere on the board
TEND0_N: U401.3 (A2); also elsewhere on the board
TEND1_N: U401.7 (A6); also elsewhere on the board
TRIG: J401.2; also elsewhere on the board
WAIT_N: U403.5 (A4); also elsewhere on the board
WR_N: U403.2 (A1); also elsewhere on the board

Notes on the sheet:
Pi PICO Channel B



Board: 4 copper layers, 101.6 x 76.2 mm, 62 parts (17 on the bottom side), 163 nets.

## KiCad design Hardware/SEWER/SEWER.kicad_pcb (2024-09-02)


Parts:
H1: MountingHole; MountingHole_3.2mm_M3
H2, H3, H4, H5: MountingHole; MountingHole_2.7mm_M2.5_DIN965
LOGO1, LOGO2: Logo_Open_Hardware_Small; OSHW-Logo_7.5x8mm_SilkScreen

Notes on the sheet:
JLC04161H-3313 stackup gives : * Ideal trace impedance (50 & 100ohms). * GND plane closer to signal layer routing for improved signal integrity.
SEWER Simple Eval With EZ80F91 on RCBUS
PAGE 5 : CPU ETHERNET
PAGE 1 : INTRODUCTION
PAGE 4 : CPU ADDRESS & DATA BUS
PAGE 2 : RCBUS INTERFACE
MOUNTING/TOOLING HOLES
This documentation describes Open Hardware and is licensed under the CERN OHL v. 1.2. You may redistribute and modify this documentation under the terms of the CERN OHL v.1.2. (http://ohwr.org/cernohl). This documentation is distributed WITHOUT ANY EXPRESS OR IMPLIED WARRANTY, INCLUDING OF MERCHANT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
PAGE 6 : CPU GPIO & RTC
PAGE 3 : CPU POWER & ZDI
PCB STACKUP NOTE


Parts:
B601: BAT-HLD-012-SMT; BAT-HLD-012-SMT_TEC; MPN BAT-HLD-012-SMT; Digikey BAT-HLD-012-SMT-ND
C601, C602: 12pF; C_0603_1608Metric; Voltage 50V; Tolerance 5%; MPN CL10C120JB8NNNC; Digikey 1276-1254-1-ND
C603: 4.7uF; C_0603_1608Metric; Voltage 16V; Tolerance 10%; MPN CL10A475KO8NNNC; Digikey 1276-1784-1-ND
C604, C605: 100nF; C_0603_1608Metric; Voltage 50V; Tolerance 10%; MPN CC0603KRX7R9BB104; Digikey 311-1344-1-ND
J601: Conn_02x10_Odd_Even; PinHeader_2x10_P2.54mm_Horizontal; MPN PH2RA-20-UA; Digikey 2057-PH2RA-20-UA-ND
R602, R603, R604, R605, R606, R607, R608, R609, R610, R611, R612, R613, R614, R615, R616, R617, R618, R619: 10K; R_0603_1608Metric; Tolerance 1%; MPN RC0603FR-0710KL; Digikey 311-10.0KHRCT-ND
U301: eZ80F91-LQFP144; LQFP-144_20x20mm_P0.5mm; MPN EZ80F91AZA50EK; Digikey 269-EZ80F91AZA50EK-ND
Y601: ECX-.327-CDX-1293; Crystal_SMD_EuroQuartz_EQ161-2Pin_3.2x1.5mm_HandSoldering; Tolerance 5ppm; MPN ECX-.327-CDX-1293; Digikey XC2292CT-ND

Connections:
+3.3V: C603.1, C604.1, C605.1, J601.2, R602.2, R603.2, R604.2, R605.2, R606.2, R607.2, R608.2, R609.2, R610.2, R611.2, R612.2, R613.2, R614.2, R615.2, R616.2, R617.2, R618.2, R619.2; also elsewhere on the board
/CpuGpioRtc/CPU_PA0: J601.14, R609.1, U301.114 (PA0/PWM0/OC0)
/CpuGpioRtc/CPU_PA1: J601.16, R610.1, U301.115 (PA1/PWM1/OC1)
/CpuGpioRtc/CPU_PC2: J601.7, R611.1, U301.92 (PC2/RTS1)
/CpuGpioRtc/CPU_PC3: J601.9, R612.1, U301.93 (PC3/CTS1)
/CpuGpioRtc/CPU_PD2: J601.8, R613.1, U301.75 (PD2/RTS0)
/CpuGpioRtc/CPU_PD3: J601.10, R614.1, U301.76 (PD3/CTS0)
/CpuGpioRtc/RTC_XIN: C601.1, U301.61 (RTC_XIN), Y601.1
/CpuGpioRtc/RTC_XOUT: C602.1, U301.62 (RTC_XOUT), Y601.2
/CpuGpioRtc/SPI_CLK: J601.15, R604.1, U301.103 (PB3/SCK)
/CpuGpioRtc/SPI_CS0_N: J601.17, R605.1, U301.100 (PB0/IC0/EC0)
/CpuGpioRtc/SPI_CSS_N: J601.19, R606.1, U301.102 (PB2/SS)
/CpuGpioRtc/SPI_MISO: J601.13, R603.1, U301.106 (PB6/MISO)
/CpuGpioRtc/SPI_MOSI: J601.11, R602.1, U301.107 (PB7/MOSI)
/CpuGpioRtc/VBAT_RTC: B601.1, B601.2, U301.63 (RTC_VDD)
CPU_I2C_SCL: J601.18, R607.1, U301.110 (SCL); also elsewhere on the board
CPU_I2C_SDA: J601.20, R608.1, U301.109 (SDA); also elsewhere on the board
CPU_INT0_N: R617.1, U301.101 (PB1/IC1); also elsewhere on the board
CPU_INT1_N: R618.1, U301.104 (PB4/IC2); also elsewhere on the board
CPU_INT2_N: R619.1, U301.105 (PB5/IC3); also elsewhere on the board
CPU_UART1_RXD: J601.6, R615.1, U301.74 (PD1/RXD0/IR_RXD); also elsewhere on the board
CPU_UART1_TXD: J601.4, U301.73 (PD0/TXD0/IR_TXD); also elsewhere on the board
CPU_UART2_RXD: J601.5, R616.1, U301.91 (PC1/RXD1); also elsewhere on the board
CPU_UART2_TXD: J601.3, U301.90 (PC0/TXD1); also elsewhere on the board
GND: B601.3, C601.2, C602.2, C603.2, C604.2, C605.2, J601.1, J601.12; also elsewhere on the board

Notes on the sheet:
CPU GPIO RTC
CR1225 BATTERY
TTL LEVEL CPU SIGNAL HEADER


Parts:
R401, R402, R403, R404, R406, R407: 33R; R_0603_1608Metric; Tolerance 1%; MPN RC0603FR-0733RL; Digikey 13-RC0603FR-0733RLCT-ND
R405, R408: 33R; R_0603_1608Metric; Tolerance 1%; MPN RC0603FR-0733RL; Digikey 13-RC0603FR-0733RLCT-ND; not fitted
R410, R411, R412, R413, R417, R418: 10K; R_0603_1608Metric; Tolerance 1%; MPN RC0603FR-0710KL; Digikey 311-10.0KHRCT-ND
U301: eZ80F91-LQFP144; LQFP-144_20x20mm_P0.5mm; MPN EZ80F91AZA50EK; Digikey 269-EZ80F91AZA50EK-ND
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

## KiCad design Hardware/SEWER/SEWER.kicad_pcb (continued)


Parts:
C201: 100nF; C_0603_1608Metric; Voltage 50V; Tolerance 10%; MPN CC0603KRX7R9BB104; Digikey 311-1344-1-ND
C202: 4.7uF; C_0603_1608Metric; Voltage 16V; Tolerance 10%; MPN CL10A475KO8NNNC; Digikey 1276-1784-1-ND
J201: Conn_02x40_Top_Bottom; RCBUS_PinHeader_2x40_P2.54mm_Horizontal; MPN PH2RA-80-UA; Digikey 2057-PH2RA-80-UA-ND
J202, J203: Conn_02x04_Odd_Even; PinHeader_2x04_P2.54mm_Vertical; MPN PH2-08-UA; Digikey 2057-PH2-08-UA-ND
J204: Conn_02x03; PinHeader_2x03_P2.54mm_Vertical; MPN PH2-06-UA; Digikey 2057-PH2-06-UA-ND
R201, R202, R203, R204: 0R; R_0603_1608Metric_Pad0.98x0.95mm_HandSolder; Tolerance 5%; MPN RC0603JR-070RL; Digikey 311-0.0GRCT-ND; not fitted
R205, R206: 0R; R_0603_1608Metric_Pad0.98x0.95mm_HandSolder; Tolerance 5%; MPN RC0603JR-070RL; Digikey 311-0.0GRCT-ND

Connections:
+3.3V: J204.6; also elsewhere on the board
/RcBusInterface/BANK_ADDR_A14: J201.48, R204.1
/RcBusInterface/BANK_ADDR_A15: J201.47, R203.1
/RcBusInterface/CPU_D15: J201.74, R202.1
/RcBusInterface/CUSTOM44: J201.44, R201.1
/RcBusInterface/RCBUS_A14: J201.2, R206.1
/RcBusInterface/RCBUS_A15: J201.1, R205.1
/RcBusInterface/RCBUS_I2C_SCL: J201.78, J203.4
/RcBusInterface/RCBUS_I2C_SDA: J201.79, J203.2
/RcBusInterface/RCBUS_INT1_N: J201.37, J203.8
/RcBusInterface/RCBUS_INT2_N: J201.77, J203.6
/RcBusInterface/RCBUS_UART1_RX: J201.36, J202.4
/RcBusInterface/RCBUS_UART1_TX: J201.35, J202.8
/RcBusInterface/RCBUS_UART2_RX: J201.76, J202.2
/RcBusInterface/RCBUS_UART2_TX: J201.75, J202.6
/RcBusInterface/RCBUS_ZCL: J201.45, J204.4
/RcBusInterface/RCBUS_ZDA: J201.46, J204.2
CPU_A0: J201.16; also elsewhere on the board
CPU_A1: J201.15; also elsewhere on the board
CPU_A2: J201.14; also elsewhere on the board
CPU_A3: J201.13; also elsewhere on the board
CPU_A4: J201.12; also elsewhere on the board
CPU_A5: J201.11; also elsewhere on the board
CPU_A6: J201.10; also elsewhere on the board
CPU_A7: J201.9; also elsewhere on the board
CPU_A8: J201.8; also elsewhere on the board
CPU_A9: J201.7; also elsewhere on the board
CPU_A10: J201.6; also elsewhere on the board
CPU_A11: J201.5; also elsewhere on the board
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

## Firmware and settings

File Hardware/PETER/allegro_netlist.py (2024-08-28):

#!/usr/bin/env python3
# Copyright (c) 2021 Google LLC. All rights reserved.
#
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

# WARNING: Allegro is not case sensitive with net names.
#          Be sure to have the "labels are similar" ERC set to flag an error!
# TODO: error out if case-mismatched nets make it through

# NOTE: the Footprint field in KiCad is supposed to be a valid part in the KiCad
#       library, and needs to be specified as Library:File. This won't work well
#       for Allegro-centric designs, so instead the conversion script uses the
#       footprint filter definition to select the Allegro footprint. The first
#       entry in the footprint filter list will correspond to the name of the
#       footprint in allegro (should be the .psm file in one of the PSMPATH
#       directories, minus the .psm). The remaining names will be added as
#       ALT_SYMBOLS, which allow the PCB designer to select from a few options.
#       This is commonly used to allow old footprints that are cached in the
#       board database to continue to be used, or for enabling the selection of
#       more or less aggressive footprint metrics.

# NOTE: Allegro supports pin and function swapping. KiCad does not (see #1950).
#       To enable function/pinswap, we define a syntax for func_* properties
#       that specify function names, a shorthand for selecting pins within each
#       instance of that function, and which pins within a fucntion can also be
#       arbitrarily swapped amongst themselves. If the pinswap/function swap
#       functions are used in Allegro, you will need to bring the swaps back
#       into the schematic somehow. Allegro can export pinswap reports as well
#       as the effective netlist post-swaps ("Netlist w/ Properties"). These
#       swaps can either be manually applied back into the schematic or
#       automatically done so via an additional script. Potential approaches for
#       automatic back-annotation include renaming nets (not always feasible)
#       and auto-generating project-local parts with the pins rearranged
#       (somewhat involved, and doesn't allow for later library updates, but
#       works as long as you don't have multiple instances of a sheet with
#       different effective pin swappings).
#
#       Functions are defined by creating any number of properties named
#       func_name, where name can be anything other than main, which is the
#       default function name given to all remaining pins.
#       The func_* property contents are:
#         group1re1,group1re2,...;group2re1...;groupNre1.....;;swap,indices,...
#       Each group is a bunch of regexes. results for each regex are
#       alphabetically sorted. order between regexes are maintained.
#       All groups must resolve to the same number of pins, and pins can only be
#       in a single group across all functions. Regexes can overlap between
#       groups in a function (first group wins), but must not overlap between
#       functions, since function order isn't guaranteed.
#       Swap indices are optional and are 1-indexed ranges in the group pin list
#       that indicates these pins can be swapped within the group.
#       Alternatively, a * means all pins within the group can be swapped.
#       A single group followed by a ;;* is an easy way to specify a list of
#       pins that can be arbitrarily swapped, without having multiple groups.

# NOTE: Care is taken to output the files in a consistent way, by sorting things
#       that can be sorted. The goals are to minimze diffs in version control
#       (with equivalent netlists having no differences) as well as reasonably
#       match the output of Allegro's "Netlist w/ Properties" output.
#       In addition, we want to minimize the number of device files created,
#       since these tend to get added to version control but never cleaned up.
# TODO: detect extraneous device files in version control and list them out as a
#       report? Make sure it's not annoying if it's intentional, e.g., multiple
#       projects/netlists in the same directory. Easiest way for designer to
#       solve is to just delete the devices directory before generating a
#       netlist again.


import os
import re
import sys

# Import kicad's netlist reader helper.
# This is copied from the kicad install's plugins directory.
sys.dont_write_bytecode = True
import kicad_netlist_reader

# Routines to convert strings into various Telesis-safe output.
# Character safety rules (discovered by trial and error):
# ! and ' in strings will cause errors even if they're 'quoted'.
# Non-ASCII characters will also cause errors.
# Strings that include spaces, +, -, or . need to be 'quoted'.
# Device names cannot include spaces, +, -, /, or .
def format_text(t):
  # Convert a string into Telesis-safe format. Unsupported characters are
  # replaced with ?'s, and the string is quoted if necessary.
  # FIXME: replace unsupported characters with an encoding instead, to avoid
  #        having similar strings mapped to each other
  if not t:
    return ''
  t = re.sub("[!']|[^ -~]", '?', t.replace('\u03BC', 'u'))
  return f"'{t}'" if re.search('[^a-zA-Z0-9_/]', t) else t
def format_net(t):
  # Converts a string into one safe for a Telesis net name.
  # Since nets in Allegro are case-insensitive, make them all uppercase to match
  # Allegro's own output.
  return format_text(t).upper()
def format_dev(t):
  # Converts a string into one safe for a Telesis device name.
  # These are all lowercase and have a more restricted set of characters.
  # FIXME: replace unsupported characters with an encoding instead
  return re.sub('[^a-z0-9_-]', '_', t.lower())
def format_pin(p):
  # Generates a Telesis-compatible pin name from a pin node.
  # Telesis requires all pin names to be unique, and doesn't have separate
  # fields for pin number and pin name/function, so we combine them together to
  # make a unique name that still describes its function if you check pin info.
  # FIXME: replace unsupported characters with an encoding instead
  t = '%s__%s' % (p.get('pin', 'name'), p.get('pin', 'num'))
  return re.sub('[^A-Za-z0-9_+?/-]', '?', t)

def pin_sort_key(p):
  # Provide a sorting key for a pin so that the pin order within a function
  # group is consistent. Consistency is important when matching regexes in
  # pinswap definitions.
  name = p.get('pin', 'name')
  if name and name != '~':
    return name
  return p.get('pin', 'num')
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

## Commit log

2024-08-28 Initial Commit of PETER
    [CpuBusSram.kicad_sch, Esp32s3-Programmer.kicad_sch, FPGA-config.kicad_sch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]
2024-08-29 Update Readme files. Add the GOLD board hardware design files.
    [GOLD-CuBottom.gbr, GOLD-CuIn1.gbr, GOLD-CuIn2.gbr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]
2024-08-30 Initial commit of BALD board.
    [BALD-CuBottom.gbr, BALD-CuIn1.gbr, BALD-CuIn2.gbr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]
2024-08-31 Initial Commit Randy
    [RANDY-CuBottom.gbr, RANDY-CuIn1.gbr, RANDY-CuIn2.gbr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]
2024-09-01 Initial commit of the ZORO board.
    [ZORO-CuBottom.gbr, ZORO-CuIn1.gbr, ZORO-CuIn2.gbr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]
2024-09-02 Initial commit of the SEWER card.
    [RcBusInterface.kicad_sch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]
2026-05-19 Initial release of ANALYZER
    [Analyzer-B_Cu.gbl, Analyzer-B_Mask.gbs, Analyzer-B_Paste.gbp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]
2026-05-19 Initial release of SPIFEE
    [68k_Cpu.kicad_sch, MC68SEC000FU20--3DModel-STEP-56544.STEP, PLCC32_SMT_SOCKET_69802-132LF--3DModel-STEP-554624.STEP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]
2026-05-19 Initial release of BUTLER
    [3V3_RCBUS_Connectors.kicad_sch, 5V_RCBUS_Connectors.kicad_sch, BOM-BUTLER_V0.0.csv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]
2026-07-07 Doc update
    [68k_Cpu.kicad_sch, SPIFEE_V0.0_BOM.csv]

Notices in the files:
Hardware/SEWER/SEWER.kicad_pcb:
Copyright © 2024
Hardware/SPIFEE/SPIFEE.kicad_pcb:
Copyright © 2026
